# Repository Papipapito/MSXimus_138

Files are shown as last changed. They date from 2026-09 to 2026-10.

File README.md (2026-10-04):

<p align="center">MSXimus</p>

<h1 align="center">MSXimus</h1>
<p align="center"><b>A complete MSX2+ on a Tang Console 60K — now with the V9968 VDP</b></p>

> **This repository is the port of the MSXimus to the Tang Console 138K (MSXimus_138, v3.7).** What is specific to the port (SOM Mega 138K, flash map, PLL cascade, campaigns, what has and has not been tested) is in [README.138.md](README.138.md); the documentation adapted to the 138K is in [docs/INDICE.md](docs/INDICE.md). The rest of this README describes the MSXimus for the Tang Console 60K it derives from.
<p align="center">
  
  
  
</p>

<p align="center">🇪🇸 <a href="README.es.md">Versión en castellano</a></p>

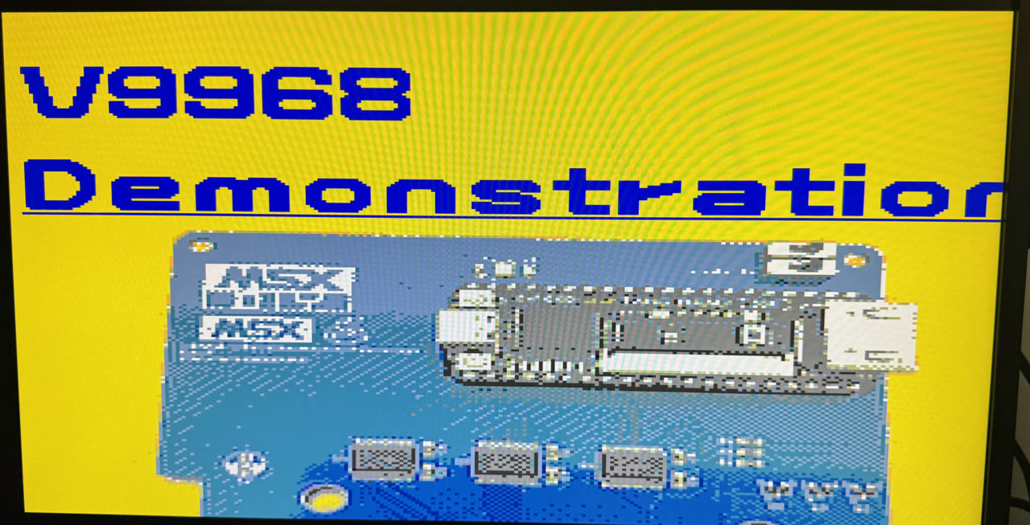
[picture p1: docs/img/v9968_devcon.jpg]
The V9968 DEVCON demo running on the MSXimus

<p align="center"><i>HRA!'s official V9968 demo, running on the MSXimus.</i></p>

---

**MSXimus** is the big brother of the [**MSXnano**](https://github.com/Papipapito/MSXnano): the same MSX2+ core lineage (goauld → MSXnano), ported to and expanded on the **Tang Console 60K**. *Nano* was the small one; *Maximus* is the big one.

It doesn't need an MSX. It **is** an MSX.

## Why v3.1 and not v2.2

Because the ground moved.

In August 2026 Gowin confirmed that the **SSRAM of the GW5AT-60B is withdrawn on purpose**: there is a silicon problem under investigation, and their recommendation is to migrate anything that uses it to BSRAM or to registers.

Version 2.1 leaned on that resource heavily — the audio engines alone accounted for most of it. So v3 is not v2.1 with more features stacked on top: it is the same MSX **rebuilt so that not one bit lives on the withdrawn resource**. Every memory that was there moved to BSRAM or to registers, and that meant reworking the OPL4 wavetable engine, the OPL3 register files and the PCM cache from the inside out.

That is a change at the foundation rather than on the surface, and it earned its own number. Everything you already knew works exactly the same; what changed is what it is standing on.

## What's inside

**Video** · Full-screen 720p HDMI output · **V9968** or V9958 · CRT-style borders · scanlines toggle, right from the menu

**Audio** · PSG · dual SCC with stereo · OPLL (MSX-Music) · **MSX-Audio Y8950** with FM and ADPCM-B · full **MoonSound / OPL4**: FM (OPL3) plus 24-voice wavetable

**Storage** · Nextor over microSD · megaram with Konami4, Konami-SCC, ASCII8 and ASCII16 mappers

**Input** · USB keyboard straight into the board (no hub needed), with physical F1–F10 · USB gamepads mapped to MSX joysticks · USB mouse as an MSX mouse

**On screen** · Optional **status panel on F12**, painted over the MSX by the BL616 the board already carries

**WiFi** · UNAPI through an external **ESP32-C6**, with an **optional display** for extra information

**Extras** · 5.37 MHz Panasonic-style turbo on **F11** · turboR-style machine identification · your choice of two BIOSes · boot logo · temperature-driven fan control · serial-port telemetry for diagnostics

## Required hardware

| | What | Notes |
|---|---|---|
| **Required** | [Sipeed **Tang Console 60K**](https://wiki.sipeed.com/hardware/en/tang/tang-console/mega-console.html) | Tang Mega 60K SOM (Gowin GW5AT-60), HDMI, 2× USB-A, microSD, DDR3 |
| **Required** | The Console's **SDRAM** module | It is the MSX's RAM; the core won't boot without it |
| Optional | **20×20 mm heatsink** on the SOM | Recommended: the core keeps the chip busy. [Like these](https://s.click.aliexpress.com/e/_c4WMlpD9) |
| Optional | **20×20 mm 5 V fan** | **1.25 mm JST connector, 2-pin** — [like this one](https://s.click.aliexpress.com/e/_c328rXwB). Fully temperature-controlled by the core |
| Optional | **USB** keyboard and gamepad | Straight into the board's USB-A ports, no hub |
| Optional | **USB mouse**, wired | Straight into the board. ⚠️ A **wireless** receiver will not work: it presents itself as a composite device |
| Optional | **ESP32-C6** (Waveshare C6-LCD-1.3) | For **WiFi**, with an optional info display |
| Optional | *Nothing to buy* — the board's own **BL616** | Enables the F12 status panel. Needs its firmware flashed once |

The fan is not needed for operation. If you fit one, the core drives it by itself: it measures the die temperature with an internal thermometer and only spins it when needed.

## Installation

Everything goes into the board's **SPI flash**, at three different addresses. ⚠️ **These are the 138K addresses**: the 138K bitstream is twice as big, so the pack and the OPL4 waves sit 4 MB higher than on the 60K (`0x400000` / `0x500000` there).

| # | File | Address | Required? |
|---|---|---|---|
| 1 | `msximus138_v3.x_dadoNNNN.fs` | **`0x000000`** | Yes — this is the core |
| 2 | BIOS pack (`pack_bios_msximus*.bin`) | **`0x800000`** | Yes — the MSX won't boot without it |
| 3 | `yrw801.bin` | **`0x900000`** | No — only for MoonSound/OPL4 (shipped as `.bin`: Gowin's Programmer does not accept `.rom`; rename a `yrw801.rom` if that is what you have) |

Two more pieces are **optional** and do not live in that flash: the **ESP32-C6** firmware (WiFi) and the **BL616** firmware (the F12 panel). Each has its own section below.

**The tools you need**, all free and all official:

| For | Tool |
|---|---|
| The three files above | [**Gowin Programmer**](https://www.gowinsemi.com/en/support/download_eda/) (the one bundled with the 1.9.12 IDE works fine) |
| ESP32-C6 (WiFi) | [**esptool-js**](https://espressif.github.io/esptool-js/) in the browser — nothing to install — or `esptool` |
| BL616 (F12 panel) | [**Bouffalo Lab Dev Cube**](https://github.com/bouffalolab/bouffalo_sdk) (BLDevCube) |

### How to flash

1. Connect the board over **USB-C** and open the **Gowin Programmer** (the 1.9.12 one works fine).
2. Let it detect the device: it should report a **GW5AST-138**.
3. For **each** of the three files, configure a write operation to the **external SPI flash** (the options starting with *exFlash*, not the SRAM ones), select the file as *Programming File*, and put **the address from the table into the start-address field**.
4. Flash the `.fs` first, then the other two. Their order doesn't matter — **the addresses do**: if the pack doesn't land exactly at `0x800000`, the core boots to a black screen.
5. **Power-cycle the board.** A reset is **not** enough: the DDR3 needs a cold recalibration and may hang after a warm reset.

> If you power up and only get a blue screen, it's almost always (a) the pack at the wrong address, or (b) a missing power-cycle.

### About the BIOS pack

The release ships **everything you need**: the core, the BIOS pack, the OPL4's `yrw801.bin` and the firmwares. Download, flash, and it boots.

There are **two builds of the same pack**, differing only in the disk kernel inside:

| Pack | Nextor |
|---|---|
| `pack_bios_msximus.bin` | **2.1.4** — the stable one, the one you want |
| `pack_bios_msximus_nextor3.bin` | **3.0 beta 1** — to try the beta |

If you would rather build the pack from your own ROMs, there's the [**MSXnano Pack Builder**](https://github.com/Papipapito/MSXnano), which assembles the file from them, Nextor included.

Without `yrw801.bin` the core works just the same; you simply won't have MoonSound.

### One BIOS, and the menu is a setting

Up to v3.1 there were **two** packs and you had to decide which to flash. There is now **one**, and that choice is a tick box in Settings.

On power-up the machine **boots straight into the MSX**. If you want the SD browser: press **S** at boot, tick **"Menu al arrancar"**, then `Save & Restart`. Untick it and you are back to booting straight in. The choice is stored in the board's flash, so it survives a power cycle.

With the menu on you get the card browser, the ROM and DSK launcher and — if you fitted the WiFi — key **F** to search and download ROMs and disk images straight to the microSD, with no PC involved.

> Mounting a `.dsk` rewrites sectors of a file that **already exists**: it never creates directory entries or allocates clusters.

After that, insert a microSD with your ROMs and disk images and you're done. The best way to prepare it is **[MSX SD Maker](https://github.com/Papipapito/SD_Maker)**, which has its own repository (a copy with its guide is in [`MSXsdmaker/`](MSXsdmaker/README.md)): a Windows program that partitions the card the way Nextor does, installs Nextor and a set of programs (SofaRun, Multi Mente…) and writes the `AUTOEXEC.BAT`.

> **About microSD cards:** use a **name-brand, Class 10** card (Samsung, SanDisk, Kingston...), formatted **FAT16**. Cheap no-name cards read fine but reject or lose sector writes under sustained bursts — we measured it on the bench: a no-name card kept failing writes even when paced, while a Samsung EVO+ was flawless with the exact same code and geometry. If downloads or saves act up, suspect the card first.

## The status panel — F12 (optional)

The Console 60K carries a second chip you have probably never used: a **BL616** microcontroller, wired to the FPGA from the factory. Give it a firmware and it will paint a status panel straight over the MSX picture.

Press **F12** and the MSX freezes and the panel comes up. Press it again and the game carries on exactly where it was. It is **read-only** — there is no menu, no cursor, nothing to break. It reports what the core says about itself:

```
 ,----------------------------.
 |       MSXimus  V3.1        |
 `----------------------------'

   CPU      3.58 MHz  normal
   Card     SDHC  st 1
   Fan      OFF
   Keyboard CAPS ON
   WiFi     0 lost  0 empty
 `----------------------------'
    F12 to go back to the MSX
```

This costs you nothing in hardware: **no wires, no soldering, no module**. The link between the two chips (a 2 Mbps serial line) was already routed on the board; it was just never used.

> Because the BL616 takes F12 for itself, that key never reaches the MSX. The **turbo toggle is F11**.

### Flashing the BL616

Two images, and they **coexist** — the Sipeed factory one stays where it is:

| File | Address |
|---|---|
| `bl616_fpga_partner_60kConsole.bin` (Sipeed's, shipped in the release) | **`0x0`** |
| `bl616_v3.1.bin` | **`0x40000`** |

1. **Hold the BOOT button down while you plug in the USB.** That puts the chip in ISP mode.
2. A **new COM port** appears — that one is the BL616. (Listing the ports before and after plugging it in is the easy way to tell which.)
3. Open **BLDevCube** and load the release's **`flash_prog_cfg.ini`**: it already carries both images with their addresses, so there is nothing to type. Keep it in the same folder as the two `.bin` files.
4. Unplug, plug back in, and power-cycle the board.

ISP mode lives in the chip's ROM, not in its flash, so it works no matter what you have written. **It is the reverse gear that never fails** — you cannot brick the board this way.

If you would rather not flash it at all, don't: the MSX works exactly the same, you simply won't have the F12 panel.

## Wiring the ESP32-C6 (WiFi)

Optional — the core works fine without it; you simply won't have WiFi. Three or four wires between the board's **J10** header and the module:

<p align="center">ESP32-C6 to J10 wiring diagram</p>

| J10 pin | Signal | FPGA ball | ESP32-C6 |
|---|---|---|---|
| **11** | +5 V (power) | — | **5V** (right strip, last one) |
| **12** | GND | — | **GND** (right strip) |
| **14** | TX (FPGA → C6) | W21 | **IO17** (left strip, the C6's RX) |
| **16** | RX (FPGA ← C6) | N17 | **IO16** (left strip, the C6's TX) |
| **18** | TURBO (FPGA → C6) | N13 | **GPIO3** (right strip, first one) — optional, only feeds the display's turbo indicator |

And this is the module side:

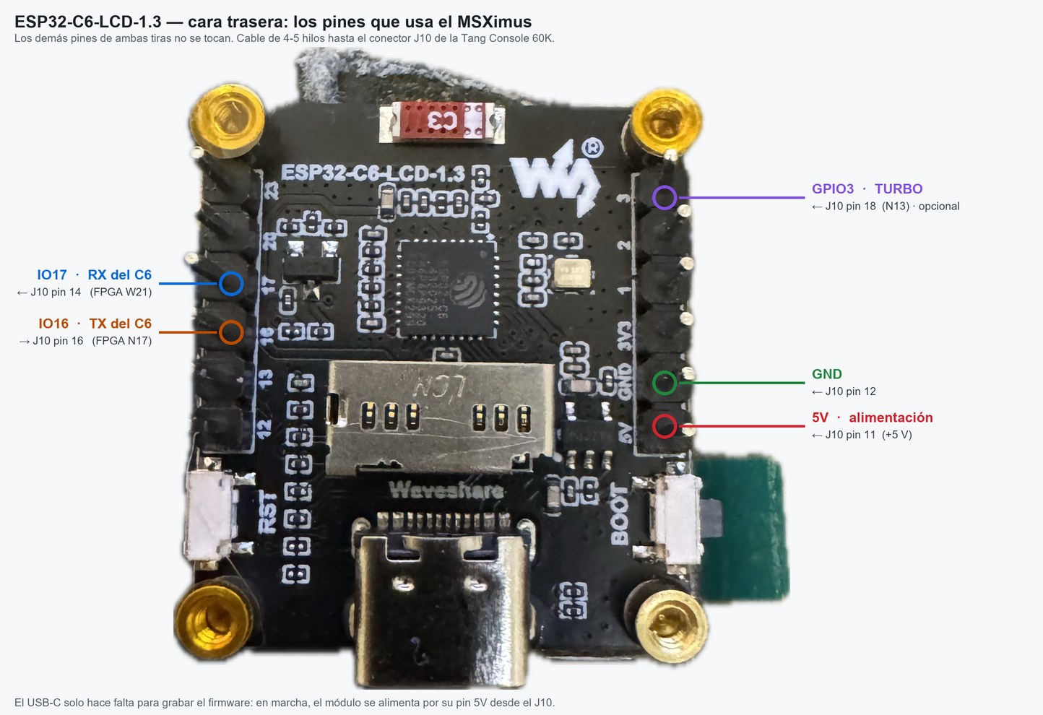
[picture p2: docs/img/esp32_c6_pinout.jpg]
ESP32-C6 pins used by the MSXimus


- **J10 is the free 2×20 header**, labelled *SDRAM1 CONN.* in Sipeed's schematic — **not** the one holding the SDRAM module the core needs.
- **Identifying the pins without silkscreen**: with the board powered off and a multimeter in continuity mode, **pin 12 is the only pin on the whole header with a path to ground**. Its row partner is pin 11 (+5 V), and from pin 12 towards the long side (the one leaving 14 rows, not 5) come 14, 16 and 18.
- **Power comes from J10 itself** (pin 11 → the module's `5V`): the C6's USB-C is only needed to flash its firmware.
- ⚠️ **Better not to have both power sources connected at once.** The module has protection and copes fine, but when flashing over USB-C it's advisable to unplug the 5 V wire (or power the board down).
- TX and RX are **crossed**, as usual. The UART runs at 859 372 baud.
- ⚠️ If a second SDRAM module is ever fitted on J10, the ESP has to move elsewhere.

### Flashing the C6

The module's firmware and its full technical inventory live in their own repository, [**ESP32-for-FPGA**](https://github.com/Papipapito/ESP32-for-FPGA) — the same binary serves the MSXimus and the MSXnano, so no copy is kept here any more. Take `firmware_esp32c6_v3.2_merged.bin` from the release and write it to the C6 through **its own USB-C**. You do **not** need the Arduino IDE, and you do not need to compile anything — the release ships a single merged binary.

**The easy way — from the browser, nothing installed.** Open [**esptool-js**](https://espressif.github.io/esptool-js/), Espressif's own web flasher, in Chrome or Edge. Connect, pick the file, set the offset to `0x0`, and click Program. No drivers, no Python, no IDE.

**The command-line way**, if you already have it:

```
esptool --chip esp32c6 --port COMx write_flash 0x0 firmware_esp32c6_v3.2_merged.bin
```

> There is no drag-and-drop route like the Raspberry Pi Pico's `.uf2`: the ESP32 has no mass-storage bootloader in ROM, so a file you copy onto a drive is not an option on any ESP32. The web flasher above is as close as it gets — one page, two clicks, nothing to install.

## The case

A 3D-printable case in the shape of a Spectravideo SVI-728, with the Console 60K inside, a bay with a lid for the ESP32-C6 and its display, a fan, and the connectors brought out to the back and the front. It derives from Palver's [SVI-728 Retropie case](https://www.thingiverse.com/thing:4066021).

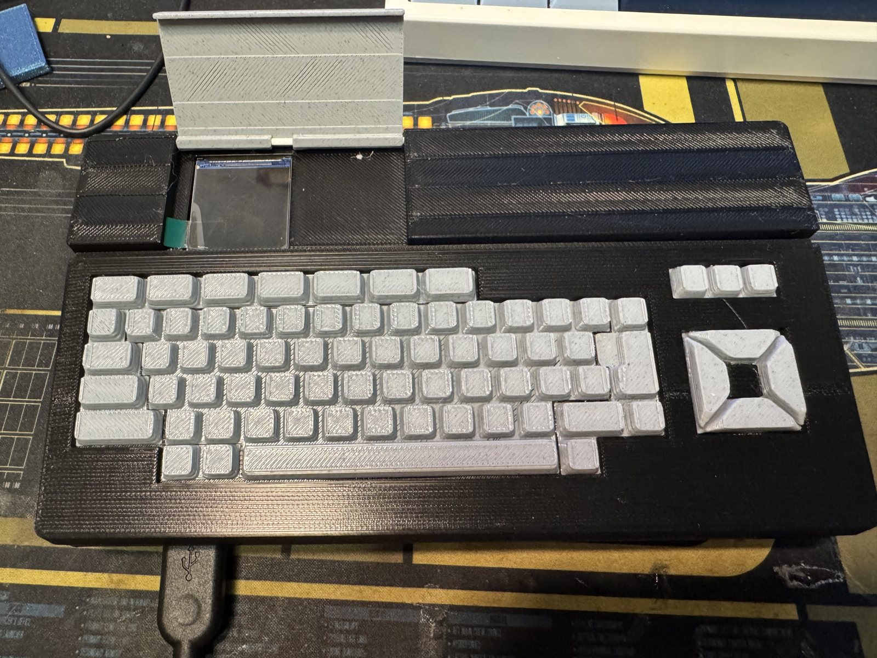
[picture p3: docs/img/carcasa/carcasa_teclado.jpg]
The printed case, display lid open

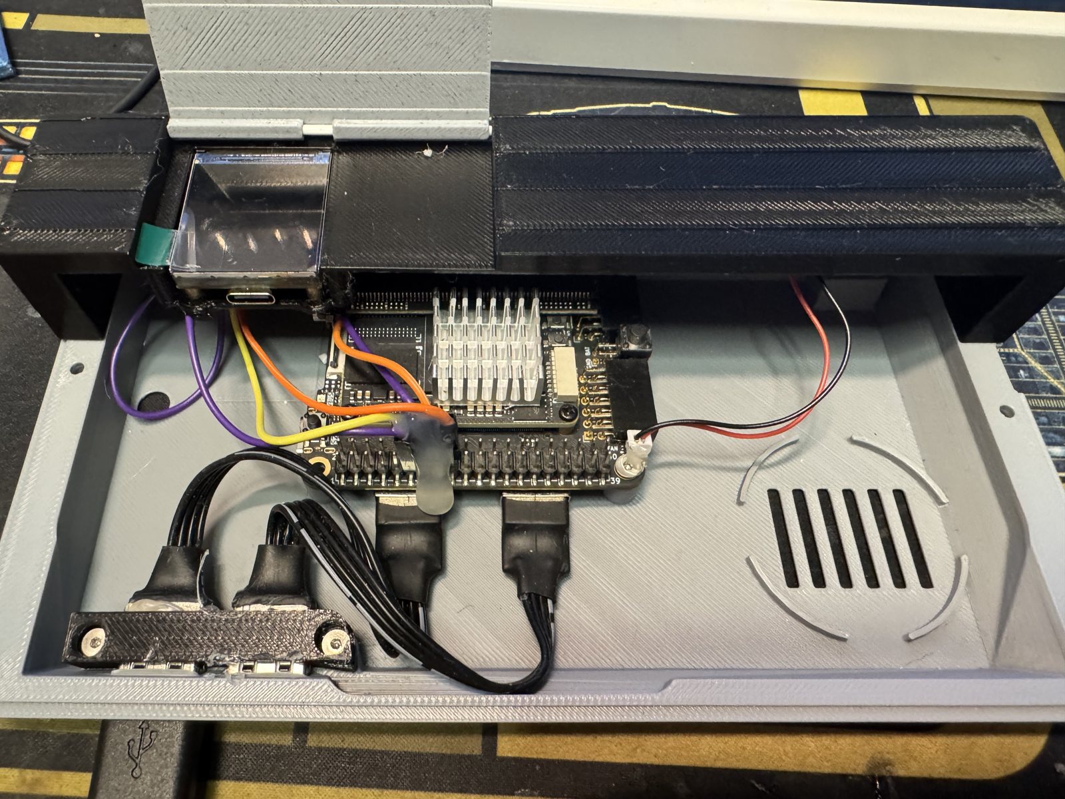
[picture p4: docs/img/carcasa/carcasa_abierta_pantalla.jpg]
Inside: the Console 60K, the C6 in its bay, the wiring


The Bambu Studio project, the STLs, the print settings and the assembly notes are in [`carcasa/`](carcasa/README.md).

## Status

This version has been validated on hardware with HRA!'s V9968 test suite, the DEVCON demos, Metal Gear 2, Aleste 2 and the usual MSX2+ catalogue. The V9968 tracks HRA!'s **latest published revision**; its provenance and every local patch are documented in [`fpga/v9968/ORIGEN.txt`](fpga/v9968/ORIGEN.txt).

## Repository layout

```
carcasa/         The 3D-printable case (3MF, STLs, assembly)
docs/            Manual, technical reference, history, logo, photos
MSXsdmaker/      MSX SD Maker: prepares the SD card (Windows program + instructions)
fpga/            top.v, build.tcl
  v9968/         The V9968 VDP (+ ORIGEN.txt: provenance and local patches)
  video720/      HDMI bridge and scaler
  src/           Own RTL (VRAM shim, DDR3 backend, audio, USB, S1990…)
    iosys/       The BL616 link and the on-screen panel
  constraints/   Console 60K pinout and constraints
tools/           Testbenches and validation utilities
```

## What's new in v3.2

The core **does not change**: it is the same `.fs` as v3.1. What changes is everything above it.

- **One BIOS** — no more picking a pack. The SD browser is now a tick box in Settings: `S` at boot, "Menu al arrancar", done. Stored in flash.
- **Downloads from the menu** — with WiFi, key `F` searches and pulls ROMs and disk images straight to the microSD, no PC.
- **Boot logo on the C6 screen** — the MSX logo assembling from both sides, like a real MSX2.
- **The C6 firmware lives in its own repository**, [ESP32-for-FPGA](https://github.com/Papipapito/ESP32-for-FPGA), and it is the same binary for the MSXimus and the MSXnano.

## What's new in v3.1

- **Rebuilt off the withdrawn silicon** — the whole core now runs without the GW5AT-60B's SSRAM. This is the headline of the version and the reason for the number; the [why](#why-v31-and-not-v22) is at the top.
- **A status panel on F12** — the BL616 already on the board paints the machine's real state over the picture, with the MSX frozen underneath. No wires, no module, no extra hardware.
- **It introduces itself as a turboR** — the S1990 identification registers are in (`E4h`–`E7h`), and `CHGCPU` really does move the turbo. No R800: same Z80, telling the truth about what it is.
- **MSX mouse from a USB mouse** — plug a **wired** USB mouse into the board and MSX software sees an MSX mouse. (A wireless receiver will not do: it presents itself as a composite device.)
- **Two BIOSes to choose from** — a plain MSX, or the same plus an SD browser and launcher. *(Merged into one in v3.2.)*
- **Turbo on F11** — F12 now belongs to the panel.

Everything from v2.1 is still here: the V9968 at HRA!'s latest revision, the remastered audio, the 256 KB MSX-Audio, the CRT-style picture and the full 2 MB ASCII16 megaROMs.

## The V9968

The heart of the MSXimus is **Takayuki Hara's (HRA!) [V9968](https://github.com/hra1129/V9968_Cartridge)**, an imaginary VDP that extends the V9958 with everything Yamaha never got to ship:

- **Multicolor sprites**: 15 colors plus transparency **per sprite**, defined pixel by pixel
- **16 sprites per line** instead of 8 — flicker is over
- **Scalable sprites**, with free magnification, rotation and mirroring
- **Extended palette**: 256 colors in 16 sets of 16
- **256 KB of VRAM**, extended commands (LRMM rotation, LFMM, LFMC) and a fast command mode

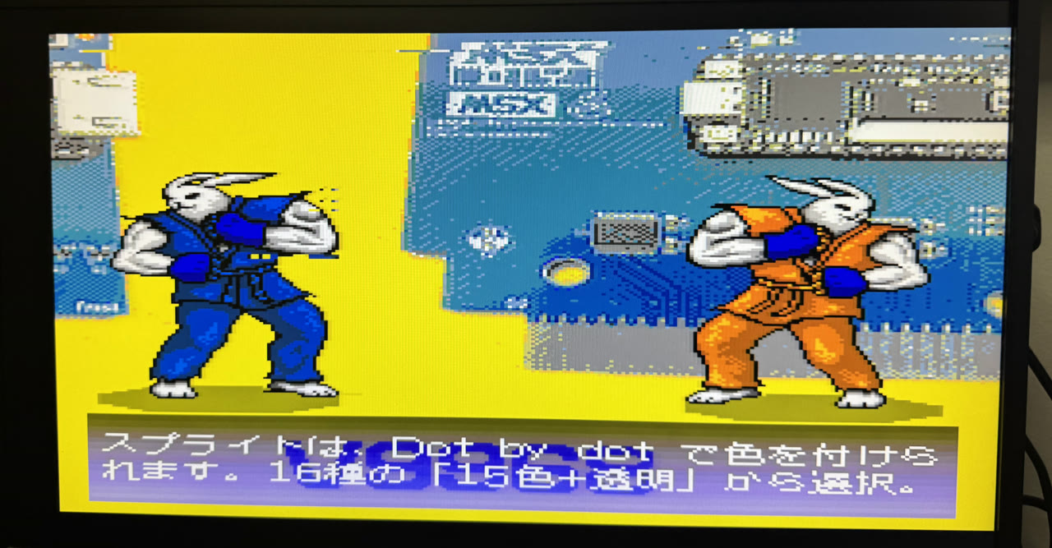
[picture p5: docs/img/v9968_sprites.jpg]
V9968 multicolor sprites

<p align="center"><i>15-color sprites defined pixel by pixel: impossible on a real MSX2+.</i></p>

The V9968's VRAM lives in the board's **DDR3**, leaving the whole SDRAM to the MSX's RAM and to whatever comes next.

And it's still a regular MSX2+: your usual software runs just the same.

## License

**GPLv3**, derived from [`Papipapito/MSXnano`](https://github.com/Papipapito/MSXnano). See [LICENSE](LICENSE) and [UPSTREAM.md](UPSTREAM.md) for full attribution and third-party IP.

The **V9968** belongs to Takayuki Hara and comes under his own BSD-like but **non-commercial** license: it may be redistributed with its notices intact and published for free, **but not sold**. That condition is inherited, so **this project is not for sale**.

The MSXimus logo belongs to the project.

---

# Thanks

I didn't build this alone — not even close. Everything here stands on the work of people who published theirs so others could keep going.

### The core and its lineage

- **[jabadiagm](https://github.com/jabadiagm)** — MSXgoauldSD, the Goa'uld, origin of this whole lineage (goauld → MSXnano → MSXimus), and MSX_LCD_tn20k.
- **OCM-PLD / ESE Artists' Factory lineage** — Kunihiko Ohnaka, KdL and everyone who has kept the FPGA MSX2+ alive for two decades. The V9958 VDP comes from there.

### The V9968

- **[Takayuki Hara — HRA!](https://github.com/hra1129)** — author of the **V9968**, the VDP that makes this version special, of the DEVCON demo and of the whole test suite it was validated against. Thank you for publishing and documenting it so well.
- **[Albert Herranz — herraa1](https://github.com/herraa1)** — the MSXgl demo port (`ru66-v9968-demo`), the V9968 cartridge and the reference material that made debugging the core possible.

### Audio

- **[Jose Tejada — jotego](https://github.com/jotego)** — jt2413 (OPLL), jtopl2 (Y8950 FM) and jt10_adpcmb. GPLv3.
- **[Greg Taylor — gtaylormb](https://github.com/gtaylormb)** — opl3_fpga (LGPLv3), which includes `afifo.v` by **Dan Gisselquist (ZipCPU)**.
- **Jokin Miragaia (antxiko)** — mangOPL4, the Gowin fixes and the integration lessons.
- **srg320** — YMF278B.sv, the OPL4's PCM engine, contributed with express permission.
- **MAME team** — R. Belmont, Olivier Galibert and hap (ymf278b.cpp), and **Aaron Giles** (ymfm).
- **Tatsuyuki Satoh** — the reference ADPCM-B algorithm.

### The board and the video chain

- **[nand2mario](https://github.com/nand2mario)** — `ddr3_framebuffer_gowin` (the DDR3 IP recipe that makes VRAM-in-DDR3 possible), `usb_hid_host`, the 720p video template and, in general, for clearing the path in the Tang ecosystem.
- **hdl-util (Sameer Puri)** — the HDMI packer (MIT).
- **[ducasp](https://github.com/ducasp)** — the ESP UNAPI firmware and protocol.

### Validation and tools

- **The [openMSX](https://openmsx.org) team** — the reference against which right and wrong get decided.
- **Laurens Holst (grauw)** — VGMPlay MSX and the MSX Assembly Page.
- **aoineko (Guillaume Blanchard)** — MSXgl.
- **[Sipeed](https://sipeed.com)** and **Gowin** — the board and the toolchain.
- **Yamaha** — for the original chips (V9958, YM2149, YM2413, Y8950, YMF262, YMF278B) that this project emulates with love.

### And

- **Claude (Anthropic)** — **code co-author**: new RTL, the VRAM-over-DDR3 shim, the audio integrations, the validation suite, and an indecent number of debugging hours built on simulation, telemetry, and being wrong many times before being right.

---

<p align="center"><i>For the MSX community. May it last another forty years.</i></p>

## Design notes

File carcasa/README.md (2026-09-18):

# La carcasa del MSXimus

Una carcasa para imprimir en 3D con la forma de un Spectravideo SVI-728, con la Tang Console 60K dentro, el ESP32-C6 con su pantalla en una bahía con tapa, ventilador, y los conectores sacados al exterior.

<p align="center">La carcasa impresa, con la tapa de la pantalla abierta</p>

## Origen

Deriva de la **[Spectravideo SVI-728 Retropie case](https://www.thingiverse.com/thing:4066021)** de Palver en Thingiverse, una réplica del SVI-728 pensada para una Raspberry Pi, rediseñada aquí para la Console 60K. **El 3MF lleva todo lo necesario**: no hace falta bajar nada del original. La licencia del diseño original se aplica a lo que se conserva de él; conviene mirarla en la página de Thingiverse antes de redistribuir.

## Qué hay

| Fichero | Qué es |
|---|---|
| `MSXimus_carcasa.3mf` | El proyecto de **Bambu Studio** con las once piezas ya repartidas en cuatro platos y con los ajustes de impresión. Es lo que se abre y se imprime, y es la caja completa |
| `stl/` | Las mismas once piezas sueltas, en STL, para cualquier otro laminador |

Las piezas:

| Pieza | Para qué | Plato del 3MF |
|---|---|---|
| `placa_inferior` | **La tapa de abajo**: el suelo, con los postes donde se atornilla la Console 60K, la rejilla del ventilador y las salidas de los cables | 3 |
| `zona_pantalla` | **La tapa de arriba, parte trasera**: la bahía del ESP32-C6 con su pantalla, la ventana del ventilador y la ranura de los conectores | 1 |
| `tapateclado` | **La tapa de arriba, parte delantera**: el marco del teclado, donde se pegan las teclas | 4 |
| `tapacartucho` | La tapa con bisagra de la bahía de la pantalla, donde el SVI-728 tenía el cartucho; se levanta para ver la pantalla | 1 |
| `usb_conector_clamp_x1` | La brida que sujeta la extensión de dos USB-A al frontal | 2 |
| `key_1` a `key_4` (gris oscuro), `key_5` (gris claro), `cursor` | Las teclas del teclado y el cursor en cruz. **Van pegadas** al marco de `tapateclado` | 2 |

El teclado es decorativo: el MSXimus usa un teclado USB.

## Impresión

Los ajustes con que se imprimió la de las fotos, tal como van en el 3MF:

| | |
|---|---|
| Impresora | Bambu Lab X1 Carbon, boquilla de 0,4 mm |
| Material | PLA. Dos colores: gris claro para el suelo y las tapas, negro o gris oscuro para la tapa superior; las teclas en los dos grises |
| Altura de capa | 0,24 mm |
| Relleno | 15 % |

Cuatro platos. En cualquier otra impresora valen los STL con ajustes equivalentes.

## Montaje

<p align="center">La carcasa abierta: la Console 60K atornillada al suelo, el C6 en su bahía, los cables</p>

- La **Console 60K** va atornillada a los postes del suelo, con el disipador hacia arriba y el conector J10 hacia la bahía de la pantalla.
- El **ESP32-C6** se sujeta en la bahía trasera con dos tornillos por su brida impresa y queda con la pantalla mirando hacia arriba, bajo la tapa, y el USB-C accesible desde dentro para grabarlo. Sus cables al J10 son los del [capítulo 02 del manual](../docs/manual/02-instalacion.md): 5 V, GND, TX, RX y, opcional, el turbo. Una vez probados, un poco de silicona sobre el conector del J10 los deja fijos.

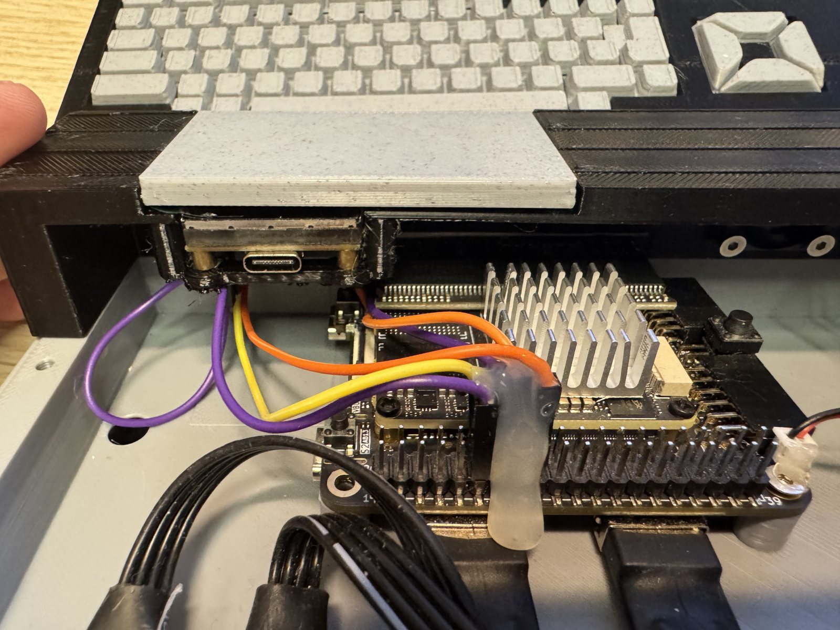
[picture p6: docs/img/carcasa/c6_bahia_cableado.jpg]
El C6 en su bahía, con los cables al J10 fijados con silicona

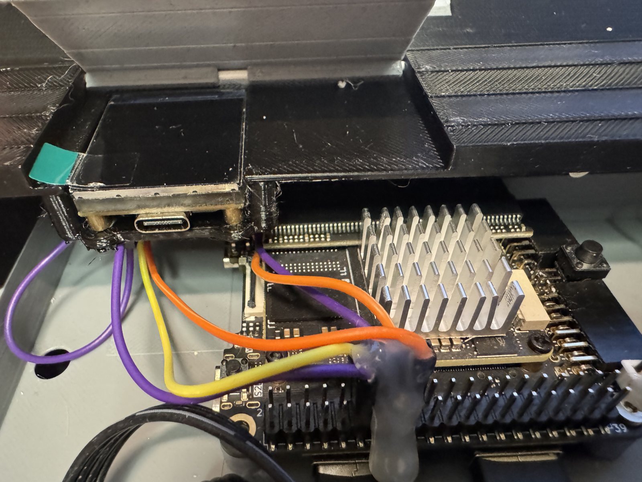
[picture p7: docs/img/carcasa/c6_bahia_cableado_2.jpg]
La bahía del C6 con la tapa levantada

- El **ventilador** de 20 mm va en la ventana trasera de la tapa, con su cable al conector de ventilador de la placa (el rojo y negro de la foto).
- **HDMI y USB**: latiguillos cortos de extensión llevan el HDMI y el USB de la placa a las ranuras traseras, y una extensión de dos USB-A con su brida sale al frontal izquierdo, para el teclado y el mando.

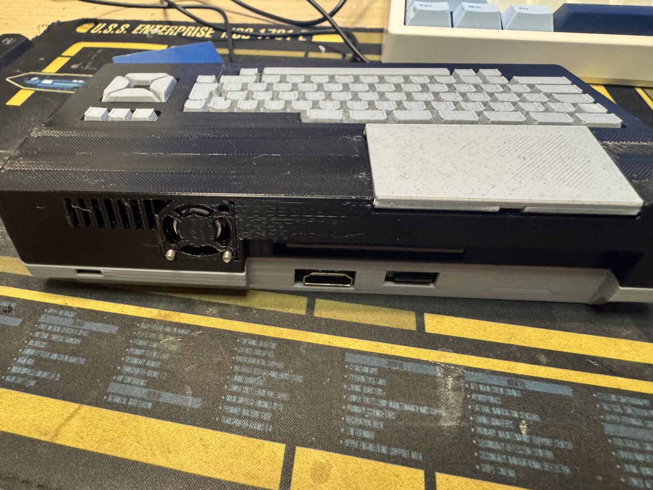
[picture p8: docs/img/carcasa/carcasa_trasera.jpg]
La parte trasera: ventilador, HDMI y USB


Y así queda junto a la carcasa VG-8020 del MSXnano, con la pantalla del C6 encendida:

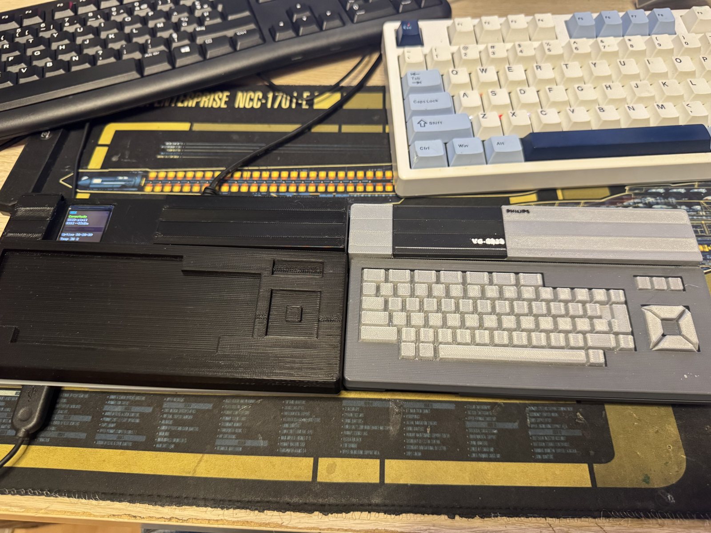
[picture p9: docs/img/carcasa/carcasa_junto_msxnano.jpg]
MSXimus y MSXnano en sus carcasas


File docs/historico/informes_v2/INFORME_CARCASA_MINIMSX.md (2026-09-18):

# Carcasa "mini MSX" para la Tang Console 60K + pantallita Waveshare — catálogo comentado

Investigación web (jul-2026). Objetivo: alojar la **Sipeed Tang Console 60K** (placa base "console" + SOM Mega 60K encima) y la **Waveshare ESP32-C6-LCD-1.3** (LCD 1.3" 240x240) como display frontal, conectada por cable plano de 4 hilos, dentro de una carcasa imprimible con estética de MSX clásico en miniatura.

---

## 1. Dimensiones confirmadas (el dato clave)

| Pieza | Dato | Fuente |
|---|---|---|
| Placa Tang Console (la "dock" donde pincha el SOM) | **65 × 56 mm** | [CNX Software](https://www.cnx-software.com/2025/05/27/sipeed-tang-console-a-gowin-gw5ast-gw5at-board-with-60k-or-138k-lut-for-fpga-development-and-retro-gaming/), [Hackster](https://www.hackster.io/news/sipeed-takes-on-the-mighty-mister-with-its-tang-console-fpga-development-board-112a417b3ec6) |
| Altura del conjunto placa+SOM | No publicada en texto; **sacarla del STEP oficial** (abajo) | — |
| Conectores a recortar | HDMI, 2× USB3-A, 2× USB-C, conector LCD 40P, altavoz, 2× PMOD, 2× 2x20P | Wiki Sipeed / CNX |
| Planos y 3D oficiales | Mechanical drawing: `dl.sipeed.com/shareURL/TANG/Console/04_Mechanical_drawing` · 3D: `.../05_3D_file` | [Wiki Sipeed](https://wiki.sipeed.com/hardware/en/tang/tang-console/mega-console.html) |
| Carcasa oficial del bundle | Acrílico estilo NES (no imprimible, referencia estética) | [Time Extension](https://www.timeextension.com/news/2025/01/usd69-fpga-tang-console-can-double-as-a-retro-gaming-handheld) |
| ESP32-C6-LCD-1.3: pantalla | 1.3" IPS 240×240, ST7789V2, SPI 4 hilos | [docs.waveshare.com](https://docs.waveshare.com/ESP32-C6-LCD-1.3) |
| ESP32-C6-LCD-1.3: conexión | Header GPIO **9 pines paso 2.54 mm** (encaja con tu plan de cable plano de 4 hilos) | docs.waveshare.com |
| ESP32-C6-LCD-1.3: PCB | Dims exactas solo en el plano-imagen "Product_Size" de la wiki (no legible por texto); área activa de un 1.3" cuadrado ≈ **23.4 × 23.4 mm** (geometría) | docs.waveshare.com |

**Conclusión de encaje**: la 60K es pequeña (65×56 mm). Cualquier mini-MSX a escala 1:2 (~25 cm de ancho, siendo un MSX real ~50 cm) la traga con holgura enorme; incluso a ~1:3 cabría. El problema nunca será el volumen, sino los **recortes de puertos** y el anclaje.

---

## 2. Catálogo

### A. Minis MSX imprimibles

| # | Modelo | Plataforma | Enlace | Licencia | Formato | Veredicto |
|---|---|---|---|---|---|---|
| 1 | **MSX Philips VG-8020 (escala 1:2)** — amandris | Thingiverse + Cults3D | [thing:3564052](https://www.thingiverse.com/thing:3564052) · [Cults3D (gratis)](https://cults3d.com/en/3d-model/gadget/amandris) | **CC-BY** (etiqueta "No AI") — remezclable con atribución | **14 STL** (base, teclado, teclas, tapa trasera, tapa cartucho, pies…) + decals al agua en PDF | **El mejor candidato directo**: pensado para meter una Raspberry Pi + electrónica (emulador MSX), interior hueco; pega: solo STL, los recortes de puertos van a golpe de editor de malla |
| 2 | **The MSX Mini Replica** (VG-8020 1:2, diseño de Gustavo Miguélez) | Blog propio | [themsxmini.blogspot.com](https://themsxmini.blogspot.com/) | Carcasa usada "bajo permiso escrito" — **ficheros NO publicados** | — | Solo referencia estética/prueba de concepto (RetroPie dentro, HDMI 720p); no descargable |
| 3 | Omega MSX Computer Case — charlesmouse | Thingiverse | [thing:5233265](https://www.thingiverse.com/thing:5233265) | ver página | STL | Tamaño completo (para el Omega MSX2+ real con teclado): NO es mini, no aplica |
| 4 | Spectravideo SVI-728 Retropie case | Thingiverse (vía Yeggi) | [yeggi "msx case"](https://www.yeggi.com/q/msx+case/) | ver página | STL | Carcasa estilo MSX1 para RPi pero a tamaño grande; estética SVI, no Philips/Panasonic |
| 5 | Miniaturas-llavero MSX (Hotbit HB-8000, Sony Hit-Bit…) | STLFinder/varios | [stlfinder "sony msx"](https://www.stlfinder.com/3dmodels/sony-msx/) | varias | STL | Sólidas, decorativas: no sirven como carcasa |
| 6 | Amstrad CPC464mini retro computer | MakerWorld | [modelo 821842](https://makerworld.com/en/models/821842-amstrad-cpc464mini-retro-computer) | ver página | 3MF/STL | No es MSX, pero es el patrón de calidad de "micro-ordenador retro en mini con hueco para SBC": útil como referencia técnica |
| 7 | Mini NES Raspberry Pi Case (NESPi) — daftmike | Thingiverse | [thing:1727668](https://www.thingiverse.com/thing:1727668) | ver página | STL | Vía alternativa "consola": casa con la estética NES de la carcasa oficial de Sipeed, pero deja de "parecer un MSX" |

### B. Específico Tang Console 60K

| # | Modelo | Plataforma | Enlace | Licencia | Formato | Veredicto |
|---|---|---|---|---|---|---|
| 8 | **Tang Retro Console PCB (STEP oficial de la placa)** — usuario 源源圆球 | MakerWorld | [modelo 1031373](https://makerworld.com/en/models/1031373-tang-retro-console-pcb) | descarga libre | **STEP** | **ORO**: el modelo 3D de la PCB subido expresamente para que la comunidad diseñe carcasas (Sipeed montó un concurso de carcasas regalando una consola al ganador — [RetroShell](https://shop.retroshell.com/2025/01/25/sipeed-introduces-tang-console-a-69-fpga-device-with-retro-gaming-capabilities/)); importas la placa en CAD y los cortes salen exactos |
| 9 | Planos + 3D oficiales Sipeed | dl.sipeed.com | [04_Mechanical_drawing](https://dl.sipeed.com/shareURL/TANG/Console/04_Mechanical_drawing) · [05_3D_file](https://dl.sipeed.com/shareURL/TANG/Console/05_3D_file) | libre | DWG/PDF + 3D | Fuente canónica de cotas; complementa al #8 |
| 10 | Console enclosure for Tang Nano **20K** — Silicon Dioxide Studios | Printables | [modelo 1446342](https://www.printables.com/model/1446342-console-enclosure-for-sipeed-tang-nano-20k-fpga) | gratis (ver página) | STL | Es para la TN20K, no para la 60K → **no vale aquí, pero es un bonus directo para tu MSXnano** |
| 11 | Case for Tang Nano 9K — Alexander K | Printables | [modelo 1047221](https://www.printables.com/model/1047221-case-for-sipeed-tang-nano-9k) | gratis | STL | No aplica (9K); solo inventario |

**No existe (a jul-2026) ninguna carcasa comunitaria imprimible publicada específica de la Tang Console 60K** en Printables/MakerWorld/Thingiverse — el hueco que dejó el concurso de Sipeed lo cubre el STEP del #8. TangCore (nand2mario) tampoco referencia carcasas en su repo.

### C. Montura para la Waveshare ESP32-C6-LCD-1.3

| # | Modelo | Plataforma | Enlace | Veredicto |
|---|---|---|---|---|
| 12 | (ninguno específico del 1.3") | — | búsquedas en [Yeggi](https://www.yeggi.com/q/esp32+c6/), MakerWorld, Printables | **No hay case/bezel publicado para el 1.3"** (placa nueva); todo lo que aparece es del hermano **1.47"** |
| 13 | Cases del ESP32-C6-LCD-**1.47** (referencia) | MakerWorld / Cults3D / Thingiverse | [1839340](https://makerworld.com/en/models/1839340-waveshare-esp32-c6-touch-lcd-1-47-case) · [1301018](https://makerworld.com/en/models/1301018-esp32-lcd-1-47-case) · [458740](https://makerworld.com/en/models/458740-waveshare-esp32-c6-case) · [Cults3D edge](https://cults3d.com/en/3d-model/gadget/enclosure-edge-for-waveshare-esp32-c6-1-47-rectangle-lcd-sdlw01-28563) · [thing:7065147](https://www.thingiverse.com/thing:7065147) | PCB distinta: no compatibles directamente; sirven para copiar el truco de clip/bisel. Un bezel propio es trivial: ventana de ~23.5 mm + bolsillo para la placa, cotas del plano "Product_Size" de la wiki |

---

## 3. TOP 3 razonado

1. **Diseño propio: contorno VG-8020 escalado + STEP oficial de la PCB (#8/#9)**. Tienes el contorno del VG-8020 ya trabajado en KiCad→STEP/DXF (proyecto msxnano-board8020): escalarlo a ~1:2–1:2.5 alrededor de los 65×56 mm e importar el STEP de la placa da recortes de puertos exactos a la primera. Único camino con encaje garantizado y estética 100% Philips.
2. **Adaptar el VG-8020 1:2 de amandris (#1)**. La estética ya está resuelta y probada (es la base visual del "MSX Mini"), licencia CC-BY remezclable, interior pensado para SBC. Coste: solo STL (retocar recortes en malla o remodelar la tapa trasera), y la pantalla frontal habría que integrarla en la zona del slot de cartucho.
3. **Vía "consola mini" (#7/#10 como patrones)**. Rápida y funcional, casa con la carcasa NES oficial de Sipeed, pero pierde el "parece un MSX" que pide Albert; dejarla como plan C.

## 4. La vía de diseño propio, en 3 líneas

Mejor **escalar tu contorno VG-8020** que adaptar un STL ajeno: tu activo ya está en STEP/DXF paramétrico (oro para CAD), mientras que lo publicado es malla. La 60K es tan pequeña que el escalado no tiene restricción de volumen, solo de posición de puertos, y eso se resuelve importando el STEP oficial de la PCB (#8). De amandris conviene "robar" (con atribución CC-BY) lo caro de modelar: teclado, teclas, proporciones y sus decals al agua.

## 5. Recomendación final

**Híbrido**: carcasa propia con tu contorno VG-8020 escalado (~25 cm de ancho a 1:2, o más compacta a 1:2.5) alrededor del STEP de la Tang Console (MakerWorld 1031373 + planos dl.sipeed.com), tomando de amandris (CC-BY) teclado/teclas/decals para el acabado. La **ESP32-C6-LCD-1.3 como display frontal** en la posición del slot de cartucho o del logo, con bezel propio (ventana ~23.5 mm; no existe montura publicada, y las del 1.47" no encajan) y su header de 9 pines a 2.54 mm alimentando el cable plano de 4 hilos hacia el dock. Verificar la altura apilada placa+SOM en el STEP antes de fijar la altura de la carcasa — es el único dato que no está publicado en texto.

---

### Fuentes principales
- Sipeed Tang Console: [CNX Software](https://www.cnx-software.com/2025/05/27/sipeed-tang-console-a-gowin-gw5ast-gw5at-board-with-60k-or-138k-lut-for-fpga-development-and-retro-gaming/) · [Hackster](https://www.hackster.io/news/sipeed-takes-on-the-mighty-mister-with-its-tang-console-fpga-development-board-112a417b3ec6) · [Wiki Sipeed](https://wiki.sipeed.com/hardware/en/tang/tang-console/mega-console.html) · [Time Extension](https://www.timeextension.com/news/2025/01/usd69-fpga-tang-console-can-double-as-a-retro-gaming-handheld) · [RetroShell (concurso carcasas)](https://shop.retroshell.com/2025/01/25/sipeed-introduces-tang-console-a-69-fpga-device-with-retro-gaming-capabilities/)
- STEP de la PCB: [MakerWorld 1031373](https://makerworld.com/en/models/1031373-tang-retro-console-pcb)
- Mini MSX: [Thingiverse thing:3564052](https://www.thingiverse.com/thing:3564052) · [Cults3D amandris](https://cults3d.com/en/3d-model/gadget/amandris) · [The MSX Mini Replica](https://themsxmini.blogspot.com/) · [MSX Resource Center (hilo VG-8020)](https://www.msx.org/forum/msx-talk/hardware/3d-printed-philips-vg-8020)
- Pantalla: [docs.waveshare.com/ESP32-C6-LCD-1.3](https://docs.waveshare.com/ESP32-C6-LCD-1.3) (esquema PDF: files.waveshare.com/wiki/ESP32-C6-LCD-1.3/ESP32C6-1.3.pdf)
- TangCore sin carcasas: [github.com/nand2mario/tangcore](https://github.com/nand2mario/tangcore)

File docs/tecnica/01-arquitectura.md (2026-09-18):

# 01. Arquitectura del core

Cómo está montado el MSXimus por dentro: qué bloques hay, cómo se conectan, con qué relojes van y qué pasa desde que se enciende la placa hasta que el Z80 ejecuta su primera instrucción. Todo sale de `fpga/top.v` y de los módulos que instancia; los números están tomados del RTL tal como se sintetiza.

Este es el porte del MSXimus a la **Tang Console 138K**. El core es el mismo que el del MSXimus 60K salvo en el chip, los relojes y el mapa de flash, y eso es lo que cambia en este capítulo. Una advertencia que vale para todo el documento y no se repite en cada apartado: el porte está compilado y verificado en simulación, pero **nunca se ha probado en una placa 138K**. Lo que en el 60K son medidas en placa (márgenes de dados, velocidades, temperaturas) se cita aquí como del 60K.

## 1. La placa y lo que se usa de ella

El MSXimus_138 corre en la **Sipeed Tang Console 138K**: la misma placa base que la Console 60K con el SOM **Tang Mega 138K** en vez del Mega 60K. El SOM lleva la FPGA **Gowin GW5AST-LV138PG484A** (484 bolas; 138.240 LUT, 340 bloques de BSRAM, 12 PLL, 298 DSP), una **DDR3** de 1 GB de la que el core usa una región (la VRAM del V9968) y una flash SPI de 16 MB. En la placa base hay una **SDRAM Winbond W9825G6KH** de 16 bits (el módulo de 40 pines de 32 MB, el mismo que en el 60K), la ranura de la tarjeta SD, dos puertos USB-A, el HDMI, el conector 2×20 libre donde va el ESP32-C6 y un microcontrolador **BL616** que hace de programador y de canal de servicio.

El SOM Mega 138K saca a la placa base las mismas bolas que el Mega 60K, dock y DDR3 incluidos, así que el fichero de pines (`fpga/constraints/msx_console138k.cst`) es una copia del del 60K con tres retoques que exige el chip: `IO_TYPE=SSTL15`/`SSTL15D` en la DDR3 (el 138 rechaza el sufijo `_I`), `s1`/`s2`/`fan_en_o` a `LVCMOS33` porque en el 138 el banco 5 va a 3,3 V, y fuera las `INS_LOC` del DLL/PLL de la DDR3. Quedan sin contrastar contra el esquemático las señales que nand2mario no usa en sus cores para la 138K: `sd_*`, `spi_irqn`, `s2`, `fan_en_o` y `esp_*` (pendiente de verificar en placa).

| Recurso | Para qué lo usa el core |
|---|---|
| SDRAM externa de 16 bits | Toda la memoria del MSX: BIOS y ROMs del pack, mapper de 2 MB, megaram de 4 MB, fuente kanji, driver de disco. Mapa en el capítulo 03. Y, por encima de los 8 MB que direcciona la CPU (filas 4096+), la tabla de ondas de 2 MB del OPL4 más 2 MB de RAM de muestras (`wave_sdram`, desde la _104) |
| DDR3 del SOM | La VRAM del V9968, con su propio controlador (la misma IP x16 a 297 MHz que en el 60K). Es el único cliente de la DDR3: las ondas del OPL4 no van aquí |
| Flash SPI de 16 MB | El bitstream (4,88 MB), el pack de BIOS de 512 KB, once bytes de configuración y la ROM de ondas YRW801 |
| Tarjeta SD | Discos y ROMs del usuario, con su propio controlador en el core (capítulo 06) |
| BL616 | Flasheo por JTAG, y una UART con el core para el panel de estado F12 sobre el HDMI. El firmware del BL616 del 60K (fork de TangCore) no se ha compilado para la 138K, que trae el partner firmware de Sipeed: el panel F12 queda pendiente |
| ESP32-C6 externo | WiFi UNAPI y pantalla de estado, por UART a unos 860 kbps |
| USB-A ×2 | Teclado, ratón y mando, con un host USB HID propio en el fabric, sin hub |

La flash está compartida con el BL616 y el bitstream del GW5AST-138 ocupa 4,88 MB (el del 60K, 2,47), así que todo el mapa sube 4 MB respecto al 60K: el pack de BIOS va en 0x800000 (60K: 0x400000), el bloque de configuración en 0x880000 (60K: 0x480000) y la YRW801 en 0x900000 (60K: 0x500000). Son tres `localparam` en `top.v` (`FLASH_START_ADDRESS`, `FLASH_CONFIG_ADDRESS`, `WL_FLASH_BASE`). Los packs son los mismos ficheros que en el 60K, solo cambia la dirección donde se graban; el programador de Gowin graba el `.fs` en 0x000000 igual.

El dispositivo en `build.tcl` es `GW5AST-138B`. Sipeed monta chips versión C desde julio de 2025 y para ellos Gowin pide compilar con `GW5AST-138C`: hay que mirar la serigrafía del chip del SOM. Hace falta Gowin EDA 1.9.12.03 en edición Standard con licencia; la Education no soporta el 138K.

## 2. Diagrama de bloques

```mermaid
flowchart LR
    subgraph CPU["Bus del MSX (54 MHz, T-estados a 3,58 / 5,37 MHz)"]
        Z80["Z80 (G80a)"]
        PPI["PPI A8-AB"]
        SLOT["Decodificador de slots\ny puertos de E/S"]
    end
    Z80 --- SLOT
    PPI --- SLOT

    subgraph MEM["Memoria"]
        MC["memory_ctrl\n(SDRAM 16 bits, 108 MHz)"]
        MAP["Mapper 2 MB"]
        MEGA["Megaram 4 MB\n+ SCC + GM2"]
        ROM["BIOS, menú, Nextor,\nkanji (del pack)"]
    end
    SLOT --> MAP --> MC
    SLOT --> MEGA --> MC
    SLOT --> ROM --> MC

    subgraph VID["Vídeo"]
        VDP["V9968 (85,9 MHz)"]
        SHIM["Shim de VRAM\n+ caché"]
        VDDR["Backend DDR3\n(VRAM 256 KB)"]
        HDMI["msx2hdmi\n720p, 74,25 MHz"]
    end
    SLOT --> VDP --> SHIM --> VDDR
    VDP --> HDMI

    subgraph AUD["Audio"]
        PSG["PSG ×2"]
        SCC["SCC ×2"]
        OPLL["OPLL"]
        Y8950["Y8950 + ADPCM"]
        OPL4["OPL4: FM + PCM\n(ondas en SDRAM)"]
        MIX["Mezclador con\nganancia #44"]
    end
    SLOT --> PSG & SCC & OPLL & Y8950 & OPL4 --> MIX --> HDMI
    OPL4 --> MC

    subgraph IO["Periféricos"]
        SD["Controlador SD\n+ DMA"]
        USB["USB HID ×2"]
        ESP["UART ESP32-C6"]
        BL["UART BL616\n(panel F12)"]
        FLASH["Streamer de flash"]
    end
    SLOT --> SD --> MC
    USB --> PPI
    SLOT --> ESP
    BL --> HDMI
    FLASH --> MC
```

Todo lo que toca la SDRAM pasa por un único controlador, `memory_ctrl`, que reparte turnos entre la CPU y los clientes secundarios. El V9968 no toca la SDRAM: su VRAM vive en la DDR3 a través del shim.

## 3. Relojes y dominios

El GW5AST no tiene el primitivo `PLLA` del GW5AT del 60K: tiene `PLL`, con los mismos divisores pero sin mDRP, y un `PLL_INIT` que le carga los parámetros del lazo (ICP/LPF) por puertos directos. Los seis PLL del core están regenerados para él en `fpga/pll138/`. Además impone dos límites que el PLLA no tenía: VCO entre 650 y 1300 MHz y frecuencia de comparación (PFD) entre 19 y 81,25 MHz. Desde el pad de 50 MHz no salen 108/54/27 ni 371,25 exactos y enteros, así que los PLL van **en cascada**, como en los cores de nand2mario para esta consola: `pll_27` (50 ÷ 2 × 27, VCO 675) da 27,000 MHz exactos y de él cuelgan `pll_main` (× 40, VCO 1080: 108, 54, 27, 135 y 36 MHz), `pll_86` (VCO 945) y `pll_ddr3` (× 33, VCO 891: 297 MHz para la DDR3 y 74,25 para el HDMI). `pll_main` y `pll_ddr3` esperan en reset al lock de `pll_27`. El vídeo y la DDR3 siguen teniendo sus propios PLL, a propósito: así el HDMI no comparte nada con el bus del MSX y los cruces se reducen a FIFOs y sincronizadores.

| Reloj | Frecuencia | Quién lo usa |
|---|---|---|
| `clk_108m` | 108,000 MHz | El controlador de SDRAM |
| `clk_54m` | 54,000 MHz | El Z80 y todo el bus del MSX: slots, puertos, PPI, PSG, SCC, mezclador, SD |
| `clk_27m` | 27,000 MHz | Registros de configuración, RTC, OPL3, UART del ESP, cronómetro de la SD, streamer de flash |
| `clk_135` | 135,000 MHz | Serializadores TMDS heredados (el HDMI real va por la cadena de vídeo) |
| `clk_wave375` | 36,000 MHz | Motor PCM del OPL4. En el 60K son 37,5 MHz (de ahí el nombre de la señal); aquí sale del mismo VCO de 1080 dividido por 30, en fase con 27/54/108, y el CE de 44,1 kHz del motor se recalculó a 14112/15000 |
| `clk_86` | 85,909 MHz | El V9968 y su shim de VRAM. Es 27 × 35/11, cero ppm respecto a 24 veces la subportadora de color |
| `clk_hdmi` / `clk_hdmi5` | 74,25 / 371,25 MHz | Píxel y TMDS ×5 del 720p. `pll_74` multiplica por 10 (VCO 742,5) el 74,25 que presta el PLL de la DDR3 (VCO 891 ÷ 12, sin gatear), como en la cascada de nand2mario para la 138K |
| DDR3 | 297 MHz | Un solo controlador, el de la VRAM del V9968 (las ondas del OPL4 van por la SDRAM), con el reloj de calibración desde el pad de 50 MHz. El `pll_stop` de la IP va directo a `ENCLK2` del PLL; en el 60K era la secuencia mDRP con `pll_mDRP_intf` |

El Z80 no va a 3,58 MHz: va a 54 MHz con habilitaciones de reloj que dibujan los T-estados. El divisor normal es 108 ÷ 30 = 3,6 MHz; el turbo es 108 ÷ 20 = 5,4 MHz con un pulso tragado cada 176, que da 5,369318 MHz exactos, la receta del turbo de Panasonic. El cambio entre los dos se hace sin glitch, solo cuando el bus está en reposo y la SDRAM libre.

Dos frenos deliberados mantienen la velocidad de un MSX real: un estado de espera en cada búsqueda de opcode (M1) y otro en cada escritura a memoria. En turbo la latencia de la SDRAM y su refresco no caben en un T-estado de 186 ns, así que hay una guarda que cuesta un 18 % del turbo teórico; se probó a quitarla en el 60K y la máquina se colgaba.

En el sdc, `clk_86` está **sobre-restringido a 11,30 ns** (el periodo real es 11,64): es la forma de obligar al rutador de Gowin, que cumple el periodo y para, a dejar margen. Un gate OK con 0,07 ns contra 11,30 son unos 0,41 ns reales. En el 138 ese dominio cierra alrededor de uno de cada tres dados; el resto del chip va holgado (CLS ~57 %, BSRAM 116/340, PnR de unos 7 minutos), así que las campañas son de tres dados (capítulo 07).

## 4. El bus del MSX

El Z80 es un **G80a**, la variante del T80 en Verilog, en modo Z80 con ciclos de E/S estándar. El bus que sale de él es el de un MSX de cuatro slots primarios, dos de ellos expandidos:

| Slot | Contenido |
|---|---|
| 0-0 | BIOS principal (32 KB) |
| 0-2 | ROM del driver de red UNAPI (16 KB, página 1) |
| 0-3 | ROM del logo de arranque (16 KB, página 1) |
| 1 | Segundo SCC o Game Master 2, según Ajustes; libre si no |
| 2 | Megaram: el cartucho emulado, con su SCC, una vez que el menú lanza una ROM |
| 3-0 | Mapper de RAM de 2 MB |
| 3-1 | SubROM (página 0), menú con FM-BIOS (página 1), segunda página del menú (página 2) |
| 3-2 | ROM del disco: Nextor y la ventana de la SD |
| 3-3 | Megaram en su posición de arranque, antes de lanzar nada |

La decodificación es la clásica: el registro de slot primario está en el puerto A del PPI y los registros de slot secundario en FFFFh de cada slot expandido. Todos los `*_req` que salen del decodificador están registrados en `clk_54m` y son mutuamente exclusivos; el mux de lectura del bus es un OR plano de esas peticiones. No es cosmética: viene del 60K, donde con la FPGA al 98 % de celdas lógicas los nodos IORQ_n y WR_n del Z80 están saturados y cualquier cono combinacional colgado de ellos aparece en la lotería de rutado. En el 138 la lógica cabe holgada, pero el diseño se conserva tal cual.

Las señales del bus que llegan a módulos en otros dominios se registran antes: el módulo de red y el V9968 ven el bus un ciclo tarde, y el glue del V9968 lo convierte en una transacción valid/ready por ciclo de E/S.

## 5. La memoria

`memory_ctrl` gobierna la SDRAM externa a 108 MHz. Es el controlador del MSXnano adaptado al bus de 16 bits: en cada turno sirve un byte, con la máscara DQM sacada del bit 0 de la dirección. Los turnos se reparten con un divisor libre de 108 ÷ 8 y ÷ 16 que marca las ranuras de CPU a 6,75 MHz, y los huecos vacíos los aprovechan dos puertos secundarios, `wv` para las ondas del OPL4 y `wv2`/`wv3` para la RAM de muestras del ADPCM-B en la línea principal (o para el V9968 cuando la VRAM va por SDRAM en la línea de respaldo).

La dirección física de 23 bits se elige en un mux de dos ramas. La rama normal es la de la CPU: mapper, BIOS, megaram, Game Master 2, kanji, menú y logo, cada uno con su región del capítulo 03. La otra rama es el **camino de streaming**, activo cuando la CPU está parada: por él escriben el streamer de la flash al arrancar y la DMA de la SD. La elección entre esos dos va por debajo, sobre registros, fuera del cono de la CPU, que en el 60K es donde vive el 98 % de la congestión.

El refresco de la SDRAM tiene dos modos. Con la CPU en marcha lo dispara la señal RFSH del Z80. Con la CPU parada entra un refresco autónomo, y ahí hay una regla dura aprendida a base de fallos: el refresco autónomo solo puede correr cuando se sabe que nadie está escribiendo, porque puede pisar una aceptación en vuelo. Por eso la señal `cpu_run` que lo gobierna junta el reset del Z80, el fin del streaming de flash, el arranque del ESP, la congelación del panel F12 y la ventana de espera de la DMA, y desde la V3.6d va registrada.

## 6. El vídeo

El VDP es el **V9968** de Takayuki Hara, el superconjunto del V9958 con comandos rápidos, paleta de 5 bits, sprites en modo 3 y VRAM de 256 KB. Va en su propio dominio de 85,9 MHz. El capítulo 05 cuenta su procedencia y su estado; aquí, cómo encaja:

1. **Glue del bus**. El V9968 espera un interfaz valid/ready. El glue registra el bus del Z80 y emite una transacción por ciclo de E/S en 98-9B (y en 88-8B, que se aliasa al mismo chip para el software que busca un V9968 como cartucho externo).
2. **Shim de VRAM**. El core pide la VRAM con un contrato de ocho ciclos. El shim la sirve con una caché de línea y prefetch y traduce las peticiones a palabras de 32 bits con máscara de bytes hacia el backend. Dos canales en paralelo, porque los modos de 256 bytes por línea consumen una palabra cada 730 ns y un canal solo no llegaba.
3. **Backend DDR3**. La VRAM vive en la DDR3 del SOM, con un controlador propio calcado del framebuffer de nand2mario para esta placa. La IP de Gowin (v3.0, x16, 297 MHz) es la misma que en el 60K: el netlist encriptado es portable dentro de Arora V, y nand2mario usa una sola para las dos consolas. El motor de reintentos escalonado de la calibración y los puertos 2Ah-2Ch (capítulo 05) van igual; la lotería de calibración por dado que se vio en el 60K es igual de aplicable aquí (pendiente de verificar en placa). Existe una línea de respaldo con la VRAM en la SDRAM compartida, que serializa cada palabra en hasta cuatro accesos al controlador de memoria; se conserva pero no es la que se entrega.
4. **msx2hdmi**. El puente al HDMI de 720p a 60 Hz. El HDMI corre en su dominio de 74,25 MHz y se alimenta del VDP a través de un anillo de 32 líneas en BRAM de doble reloj; la captura se auto-alinea con las señales reales de sincronismo y blanking del VDP. El audio va embebido en el mismo HDMI. Sobre esta imagen el BL616 puede superponer el panel de texto de la tecla F12.

Solo hay salida de 60 Hz. La geometría de 50 Hz del V9968 no está medida.

## 7. El audio

Siete generadores entran en un mezclador con saturación en `clk_54m`:

| Chip | Puertos | Implementación |
|---|---|---|
| PSG YM2149 | A0-A2 | Con filtro de paso bajo, y el registro 14 sirve el joystick USB |
| Segundo PSG | 10-12 | El mismo módulo, para el software que lo busca ahí |
| SCC / SCC+ | En la megaram, 9800h y B800h | `scc_wave2` en Verilog puro; el VHDL original lo barría la síntesis de la GW5A |
| Segundo SCC | Slot 1 | El mismo módulo, en el slot que no ocupa la megaram |
| OPLL YM2413 | 7C-7D | `jt2413` de JOTEGO |
| Y8950 MSX-Audio | C0-C1 | `jtopl2` más un decodificador ADPCM-B con los 256 KB de muestras del Y8950 en la SDRAM (`adpcm_sdram`, puerto `wv2` de `memory_ctrl`, filas 5120+; en la línea de respaldo con la VRAM en SDRAM cae a 32 KB en BSRAM) y su IRQ al Z80 |
| OPL4 MoonSound | C4-C7 y 7E-7F | FM con `opl3_fpga` y motor PCM `YMF278B` de 24 slots (a 36 MHz en el 138) con las ondas en la SDRAM (`wave_sdram`, por el puerto `wv` de `memory_ctrl`), cargadas de la flash en segundo plano tras el arranque |

El grupo clásico pasa por una ganancia maestra ajustable de 0 a 7 por el puerto #44, guardada en la flash; el OPL4 entra después de esa ganancia, a nivel nativo, porque la ganancia existe justamente para subir los chips flojos a la altura del MoonSound. El OPLL entra atenuado a tres cuartos para igualar el balance medido en openMSX entre su portadora y la del Y8950. En el 138 su salida se registra en `clk_27m` antes de entrar al mezclador (`jt2413_wav_r27`): el árbol de sumas de 22 ns que en el 60K cabía por poco en la relación 54 → 27 aquí no cerraba (−4,3 ns en la campaña p138f); cuesta 37 ns de retardo, inaudible. Hay salida mono y estéreo, según Ajustes.

## 8. Periféricos

- **Teclado, ratón y mando USB**, por los dos USB-A: dos instancias del host USB HID en el fabric, con un PLL de 12 MHz propio, sin hub. El teclado se traduce a la matriz del MSX; el ratón se presenta por el puerto de joystick como un ratón MSX; el mando (desde la v3.6f) sale del host como una palabra de doce bits en formato SNES (4 arriba, 5 abajo, 6 izquierda, 7 derecha, 8 A, 0 B, 10 y 11 los hombros) y va al puerto 1 del registro 14 del PSG, con autodisparo en los botones 3 y 4. El host es HID puro con el informe de los mandos genéricos (ejes a 00/7F/FF): un mando **XInput** (Xbox y los receptores que lo imitan) no es HID y no se ve. El BL616 tiene su propio host USB en el USB-C OTG y el firmware TangCore del 60K entiende XInput, pero exige un hub o adaptador OTG con alimentación en el puerto donde normalmente va el cargador; el MSXimus no cuenta con él para los mandos (y en la 138K ese firmware está además pendiente).
- **Reloj de tiempo real** en B4-B5, alimentado por el reloj del sistema.
- **Fuente kanji** por los puertos D8-DB, con los 256 KB de JIS1 y JIS2 en la SDRAM.
- **S1990 del turbo R** en E4-E7: la máquina se identifica como turbo R y la rutina CHGCPU de la BIOS mueve el turbo. No hay R800.
- **ESP32-C6** por los puertos 06-07: el puente `wifi_lite` es una UART con FIFO de recepción de 2080 bytes, prescaler fijo 27 ÷ 31 = 870968 bps (el firmware del ESP va a 859372, un 1,3 % menos, dentro de la tolerancia de una UART), y "recepción rápida" que retiene la lectura hasta 25 ms cuando el FIFO está vacío.
- **BL616**: el core le manda su estado por UART y él dibuja el panel F12 sobre el HDMI. Mientras el panel está abierto, el MCU congela el Z80 parando su `cpu_run`, sin resetearlo. Esto lo hace el firmware del 60K (fork de TangCore), que no se ha compilado para la 138K; con el partner firmware de Sipeed que trae la Console 138K el panel no existe. Pendiente.
- **Tira de ocho LEDs WS2812**: diagnóstico. El LED de red parpadea con el tráfico de la UART del ESP.
- **Ventilador** por temperatura (`fan_ctrl` + oscilador de anillo `ro_osc` como termómetro relativo). En el 138 `fan_en_o` va a 3,3 V y es de los pines sin contrastar contra el esquemático (pendiente de verificar en placa).
- **Telemetría serie** (`dbg_uart` por E22 y la UART del USB-C): contadores del shim del V9968, la DDR3, el audio y el ventilador; su periodo (`PERIOD_MS`) es el dado que siembra el placement de cada campaña.
- La telemetría, la tira de LEDs, el ventilador por temperatura y el segundo PSG, más un decodificador de teclado único, forman la *dieta* de la v3.6h (`DIETA_V36H` en `top.v`, apagada): se probó en el 60K y rutaba peor, ver el [capítulo 07](07-sintesis-campanas.md).
- **UART de depuración** a 54 MHz por un PMOD, apagada en las entregas.

## 9. Qué pasa al encender

1. `pll_27` engancha y con él la cascada de PLL. Un secuenciador de reset suelta tres etapas separadas 39 ms.
2. El **streamer de flash** copia el pack de BIOS, 512 KB más once bytes, desde 0x800000 de la flash a la SDRAM, byte a byte por el camino de streaming. Al final lee los once bytes de configuración: los seis de siempre (los dos registros de Ajustes, el byte de turbo al arrancar y el de ganancia) más los cuatro niveles del mezclador por fuente y su byte de comprobación (V3.7). Con el botón S2 pulsado se cargan los valores de fábrica.
3. Mientras tanto la DDR3 calibra y, en cuanto el pack está en su sitio, el **cargador de ondas** empieza a copiar los 2 MB de la YRW801 desde 0x900000 a la región de ondas de la SDRAM, en segundo plano.
4. El core espera unos tres segundos a que el **ESP32** haya arrancado, para que el driver de red lo encuentre a la primera.
5. Cuando todo eso está, y la DDR3 de la VRAM ha calibrado (desde la V3.6g el paso a `reset3_n` espera al `ready` del backend, con un tope de unos 10 s desde la V3.7b para arrancar a ciegas si nunca calibra; mientras tanto el LED de la SD parpadea solo), el Z80 sale de reset y arranca la BIOS del pack. El menú de la BIOS vive como cartucho en el slot 3-1 y toma el control en el escaneo de slots; lo que hace a partir de ahí lo cuenta el capítulo 04 del manual.

Un reset del MSX no repite el streaming: la SDRAM conserva su contenido, y por eso conserva también la megaram con la partida guardada, que es lo que permite el guardado de SRAM al siguiente arranque. Un apagado lo pierde todo.

## 10. Lo que no está

- No hay R800 ni MSX-DOS 2 en ROM; el identificador de turbo R sirve para el turbo y para el software que lo consulta.
- No hay salida analógica de vídeo ni de audio: todo va por el HDMI.
- No hay host USB en el ESP32-C6, por silicio; el teclado va por los USB de la placa.
- La variante con el V9958 original está eliminada del árbol; el V9968 es el único VDP.
- No hay firmware propio del BL616 para la 138K: el fork de TangCore del 60K no se ha compilado para ella y el partner firmware de Sipeed no conoce el panel F12. Flashear por el programador de Gowin no lo necesita.

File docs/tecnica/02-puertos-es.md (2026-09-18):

# 02. Mapa de puertos de E/S

Todos los puertos a los que responde el core, sacados del decodificador de `fpga/top.v` y de los módulos que cuelgan de él. Los puertos que no aparecen devuelven FFh en lectura y se ignoran en escritura: no hay bus externo.

El mapa es el mismo que el del MSXimus 60K: la Tang Console 138K es la misma placa base con otro SOM (el Tang Mega 138K), y el porte no toca la decodificación de E/S. Lo que cambia entre las dos máquinas (relojes, mapa de flash, licencia de Gowin) no se ve desde el Z80. Como el resto del porte, este mapa está compilado y comprobado en simulación, no en una placa 138K.

## 1. Resumen

| Puertos | Dispositivo | Estándar MSX |
|---|---|---|
| 06-07 | UART del ESP32 (WiFi UNAPI) | no |
| 10-12 | Segundo PSG | no |
| 2D-2F | Diagnóstico USB, diagnóstico del ratón, versión del core | no |
| 34-37 | Diagnóstico de la DDR3 y del cargador de ondas | no |
| 40-4F | E/S conmutada: configuración del core, SD por puertos, OCM, turbo Panasonic | OCM |
| 7C-7D | OPLL (MSX-MUSIC) | sí |
| 7E-7F | OPL4, parte de ondas (MoonSound) | sí |
| 88-8B | V9968 como cartucho externo (alias del interno) | HRA! |
| 98-9B | V9968 (el VDP de la máquina) | sí |
| A0-A2 | PSG | sí |
| A8-AB | PPI: slots, teclado, casete, click | sí |
| B4-B5 | Reloj de tiempo real | sí |
| C0-C1 | Y8950 (MSX-Audio) | sí |
| C4-C7 | OPL4, parte FM (MoonSound) | sí |
| D8-DB | Fuente kanji JIS1 y JIS2 | sí |
| E4-E7 | S1990 (identificación turbo R) | sí |
| F2 | Registro libre de 8 bits | no |
| FC-FF | Registros del mapper de RAM | sí |

## 2. La E/S conmutada: 40h a 4Fh

Es el mecanismo del OCM. Se escribe en el puerto **40h** el identificador de un dispositivo y a partir de ahí los puertos 41h a 4Fh son de ese dispositivo. Leer 40h devuelve el identificador invertido, que es como el software comprueba que el dispositivo existe. El MSXimus responde a tres identificadores:

| OUT 40h | Lee 40h | Dispositivo |
|---|---|---|
| 48h | B7h | La configuración del core, la del menú de Ajustes. Es el dispositivo "goauld" heredado del MSXnano |
| 08h | F7h | Turbo del T9769 de Panasonic, para el software que lo maneja así |
| D4h | 2Bh | E/S conmutada del OCM: órdenes inteligentes en 41h y DIP virtuales en 42h |

Sin dispositivo seleccionado, o con otro identificador, 41h-4Fh caen en el módulo OCM.

### Dispositivo 48h: la configuración del core

| Puerto | Acceso | Contenido |
|---|---|---|
| 41h | R/W | Config 1. bit 0 mapper activo, bit 1 megaram activa, bit 2 segundo SCC en el slot 1, bit 3 scanlines, bits 5-4 slot del mapper (11 = expandido 3-0), bits 7-6 slot de la megaram (11 = expandido 3-3 al arrancar; el dispositivo OCM la pasa a 10 = slot 2 al lanzar una ROM) |
| 42h | R/W | Config 2. bit 0 SD activa, bits 2-1 slot de la SD (3-2), bit 3 menú al arrancar, bit 4 Game Master 2 en el slot 1, bit 5 estéreo. En escritura, el bit 6 ordena guardar la configuración en la flash y el bit 7 ordena un reset; solo se almacenan los bits 5-0 |
| 43h | W | Configuración de la SRAM de la megaram, volátil. En ASCII8 el bit de habilitación; en ASCII16 distinto de cero activa el modo "valor 10h"; 0 la apaga |
| 44h | R/W | Mezclador de audio (v3.7). Escritura: `{solo_sel[7], canal[6:4], nivel[3:0]}`. Canal 0 = la ganancia maestra de siempre (nivel 0-7 = x1..x8, así que `OUT 44h,0..7` sigue significando lo mismo); canales 1-6 = PSG, SCC, OPLL, MSX-Audio, OPL4 FM, OPL4 wave, nivel 0-8 = k/8 (8 = tal cual, 0 = mudo); el 7 (WaveGame) solo existe en la línea Zynq. Con el bit 7 a 1 no escribe: solo selecciona el canal. Lectura: `{0, canal seleccionado, su nivel}`; el canal 7 lee Fh en el Tang (60K y 138K). Sonda del menú: `OUT 44h,F0h` + `IN 44h` = 7nh si hay mezclador. Todo se guarda en la flash con la orden de 42h |
| 45h | R/W | bit 0 = arrancar en turbo. Se guarda en la flash como el byte 'T' |
| 46h | R/W | Extensión del mapper de la megaram, volátil pero sobrevive al reset del MSX: bit 0 NEO (convierte ASCII8 en NEO-8 y ASCII16 en NEO-16), bit 4 mitad alta de los 4 MB para el cargador, bit 6 Game Master 2 armado. En lectura, el bit 7 a 1 dice que el core trae el Game Master 2 |
| 47h-4Fh | | El controlador de la SD por puertos, en el apartado siguiente |

Los registros 41h y 42h se escriben en una copia temporal y solo pasan a ser efectivos con la orden de guardar de 42h, que también reinicia la máquina. El 46h se pone a cero en cada reset a propósito: si el Game Master 2 quedara armado, el escaneo de slots de la BIOS se toparía con su firma en el slot 1.

### Dispositivo 48h, puertos 47h a 4Fh: la SD por puertos

Es el interfaz que usan el menú y el driver de Nextor. La ventana de memoria clásica sigue existiendo (capítulo 03) y ambos caminos gobiernan el mismo controlador.

| Puerto | Acceso | Contenido |
|---|---|---|
| 47h | W | Orden: bit 0 leer, bit 1 escribir, bit 2 DMA (con el bit 0), bit 3 contar patrones de mapper durante la DMA, bit 4 poner a cero los contadores, bit 7 inicializar la tarjeta. Además rebobina el puntero del búfer |
| 47h | R | Estado: bit 7 ocupado, bit 3 bloque listo, bit 2 error de CRC en lectura, bit 1 timeout, bit 0 error de CRC en escritura. Los bits 6-5 fijos a 0 y el bit 4 fijo a 1 sirven de sonda: un core sin puertos devuelve FFh |
| 48h-4Bh | W | Los cuatro bytes del número de sector, del bajo al alto |
| 48h | R | Tipo de tarjeta: 0 desconocida, 1 SD v1, 2 SD v2, 3 SDHC |
| 4Ch | R/W | Un byte del búfer de sector; el puntero avanza solo, pensado para INIR y OTIR |
| 4Dh | R/W | Número de bloques de la siguiente orden: 0 o 1 un solo sector, N mayor que 1 lectura o escritura multibloque |
| 4Eh | W | Índice del byte de información que devolverá la lectura de 4Eh |
| 4Eh | R | El byte de información elegido, según la tabla de abajo |
| 4Fh | W | 80h arma el registro de destino de la DMA y los tres OUT siguientes son la dirección; cualquier otro valor rebobina el puntero del búfer |
| 4Fh | R | Puntero del búfer, byte bajo, para depurar |

Índices de 4Eh:

| Índice | Devuelve |
|---|---|
| 2 | El mismo estado que 47h |
| 7, 8, 9 | Tamaño de la tarjeta (C_SIZE), tres bytes |
| 10 | C_SIZE_MULT |
| 11 | READ_BL_LEN |
| 12 | Tipo de tarjeta |
| 25, 26, 27 | Cronómetro de milisegundos, tres bytes. Al pedir el 25 se congela la foto de los 24 bits, y 26 y 27 devuelven esa misma foto |
| 28 | 54h ('T'): este core tiene cronómetro |
| 29 | 44h ('D'): este core tiene DMA de lectura |
| 31 | 4Dh ('M'): la DMA tiene modo lógico y contadores de mapper |
| 32-33, 34-35, 36-37, 38-39 | Los cuatro contadores de patrones de la DMA, 16 bits cada uno: Konami-SCC, Konami, ASCII8, ASCII16 |

El cronómetro va con el reloj de 27 MHz y no depende de las interrupciones del MSX; existe porque el menú medía la carga con el contador de la BIOS, que se para con las interrupciones inhibidas. Todo el detalle de la DMA está en el capítulo 06.

### Dispositivo 08h: el turbo de Panasonic

| Puerto | Acceso | Contenido |
|---|---|---|
| 41h | W | Solo el bit 0, activo a nivel bajo: 0 pone 5,37 MHz, 1 pone 3,58 MHz |
| 41h | R | bit 0 estado del turbo (0 = activo), bit 2 a 0 (turbo disponible), bit 7 a 1; es decir FAh en turbo y FBh en normal |

Es el protocolo que openMSX describe para el MSXMatsushita, y el que usan los juegos y utilidades que conocen el turbo de la serie FS-A1.

### Dispositivo D4h: la E/S conmutada del OCM

Llega del módulo `swioports` del OCM-PLD. El menú la usa para una sola cosa: la orden inteligente 0Fh en 41h, que pone el slot 2 en modo SCC-I interno, que es como el cargador escribe la megaram. Los DIP virtuales del puerto 42h fijan el modo de ese slot 2.

## 3. El resto de puertos, uno a uno

### 06h-07h: UART del ESP32

Es el puente `wifi_lite` de ducasp, agnóstico al módulo. Un byte por acceso, sin búfer de transmisión, FIFO de recepción de 2080 bytes.

| Puerto | Acceso | Contenido |
|---|---|---|
| 06h | W | Orden de velocidad. La versión "lite" solo reconoce la 20, que vacía el FIFO; la velocidad es fija |
| 06h | R | Saca un byte del FIFO de recepción. Si está vacío, el hardware retiene la lectura hasta 25 ms esperando un byte; si no llega, devuelve FFh y marca underrun |
| 07h | W | Byte a transmitir |
| 07h | R | Estado: bit 0 hay datos, bit 1 transmisión en curso, bit 2 FIFO lleno, bit 3 soporta recepción rápida, bit 4 underrun |

El módulo pone al Z80 en espera durante sus ciclos de E/S.

### 10h-12h: segundo PSG

Un segundo YM2149 completo, con la misma decodificación que el principal desplazada: 10h dirección, 11h escritura, 12h lectura. Para el software que espera un PSG ahí. (Con la opción `DIETA_V36H` desaparece y 12h lee FFh; en producción va.)

### 2Ah-2Fh: diagnóstico y versión

| Puerto | Devuelve |
|---|---|
| 2Ah | Arranque de la DDR3 (v3.7b): décimas de segundo desde el encendido hasta que la VRAM calibró (255 = 25 s o más, o no ha calibrado) |
| 2Bh | Arranque de la DDR3: duración en centésimas del intento de calibración que lo consiguió (255 = 2,55 s o más); sin calibrar, el intento en curso |
| 2Ch | Arranque de la DDR3: bit 7 = calibrada; bits 6-0 = intentos de calibración fallidos antes (0 = a la primera, 127 = saturado) |
| 2Dh | Estado del USB: bit 7 error de conexión en el USB 2, bit 6 en el USB 1, bits 5-4 tipo del USB 2 y bits 3-2 tipo del USB 1 (0 nada, 1 teclado, 2 ratón, 3 mando), bits 1-0 cuenta de informes recibidos, que cambia si el dispositivo habla |
| 2Eh | Estado interno del ratón |
| 2Fh | Versión del core, en BCD: 37h es la 3.7. El porte 138 devuelve el mismo valor que el 60K de la misma versión: no hay ningún byte que distinga las dos placas |

El menú de Ajustes muestra la versión leyendo 2Fh. Un core anterior a que existiera devuelve FFh, y el menú dice "desconocida".

Los tres de la DDR3 son la respuesta al arranque en negro desde un cargador que se vio en el 60K (capítulo 10 del manual); el 138 lleva la misma IP de DDR3 y el mismo motor de reintentos, así que la lotería de calibración por dado es igual de aplicable (pendiente de verificar en placa). Desde BASIC, `PRINT INP(&H2C) AND 127, INP(&H2B)*10, INP(&H2A)/10` dice cuántos intentos fallaron, cuántos milisegundos duró el bueno y a los cuántos segundos arrancó el vídeo.

### 34h-37h: DDR3 y cargador de ondas

Cuatro puertos de solo lectura que dejó el bring-up de la DDR3 para el OPL4, cuando las ondas vivían en ella (desde la _104 van por la SDRAM del dock, `wave_sdram`, y los puertos conservan el nombre y la interfaz): 34h diagnóstico de la memoria de ondas, 35h diagnóstico del motor, 36h estado del cargador (bit 2 = copiando la YRW801), 37h un byte de la memoria de ondas leído por anticipado.

### 7Ch-7Dh: OPLL

El YM2413 de MSX-MUSIC, solo escritura: 7Ch registro, 7Dh dato.

### 7Eh-7Fh: OPL4, ondas

La parte PCM del MoonSound: 7Eh registro y 7Fh dato del motor de 24 slots. La ROM de ondas es la YRW801 de 2 MB, copiada de la flash (0x900000 en el 138K) a la SDRAM del dock al arrancar (capítulo 03).

### 88h-8Bh y 98h-9Bh: el V9968

Los cuatro puertos clásicos del VDP: 98h datos de VRAM, 99h registros y estado, 9Ah paleta, 9Bh registros indirectos. El rango 88h-8Bh es un alias del mismo chip: el software escrito para el cartucho V9968 de HRA! lo busca ahí como VDP externo, y en el MSXimus el V9968 ya es el interno.

Los puertos 9Ch y 8Ch, el "puerto 4" que el V9968 define para los flags de interrupción, **no están decodificados**. El capítulo 05 explica qué implica.

### A0h-A2h: PSG

El YM2149 principal. En A2h con el registro 14 seleccionado se lee el joystick, que viene del mando o del ratón USB; el bit 6 del registro 15 elige el puerto. Los botones 3 y 4 del mando hacen autodisparo sobre los botones 1 y 2. El registro 15 se relee (lo último escrito): la BIOS lo lee, modifica y escribe en cada interrupción, y devolver FFh conmutaba el pin 8 del puerto 2 a 60 Hz y vaciaba el ratón (arreglado en la v3.6e del 60K, incluido en el porte). Los demás registros siguen devolviendo FFh al leerlos: el `O_DA` del YM2149 está sin conectar, aunque el modelo los sirve.

### A8h-ABh: PPI

| Puerto | Contenido |
|---|---|
| A8h | Registro de slots primarios |
| A9h | Lectura de la fila del teclado seleccionada |
| AAh | bits 3-0 fila del teclado, bit 4 motor del casete, bit 5 salida de casete, bit 6 LED de kana, bit 7 click del teclado. Se puede releer |
| ABh | Registro de control: el modo de poner y quitar bits sueltos del puerto C, que usa la BIOS para CAPS, el click y el motor |

### B4h-B5h: reloj de tiempo real

El RP5C01 de un MSX2: B4h selecciona el registro, B5h lo lee o escribe. Su reset está fijo a cero, así que hora y RAM sobreviven a los resets del MSX; no hay pila, al apagar se pierden. Con el ESP32 conectado, el driver de red puede ponerlo en hora por internet.

### C0h-C1h: Y8950

MSX-Audio: C0h registro, C1h dato. En lectura, C0h devuelve el estado con los flags de los temporizadores, el fin de muestra y el búfer del ADPCM. La IRQ va al Z80 en AND cableado, y arranca enmascarada.

### C4h-C7h: OPL4, FM

La parte OPL3 del MoonSound: C4h/C5h primer banco de registros, C6h/C7h segundo banco. En lectura, el estado.

### D8h-DBh: fuente kanji

El interfaz estándar: D8h y D9h fijan la dirección en JIS1, DAh y DBh en JIS2, y la lectura devuelve los bytes del glifo. Los 256 KB de fuente viven en la SDRAM.

### E4h-E7h: S1990

El controlador del turbo R, solo para identificarse como tal. La BIOS y el software leen aquí el modo de CPU y CHGCPU conmuta el turbo del core. No hay R800 detrás.

### F2h: registro libre

Un byte de lectura y escritura sin función en el hardware. Se lee tal como se escribió.

### FCh-FFh: mapper de RAM

Los cuatro registros de segmento del mapper, uno por página de 16 KB. Son de **solo escritura** en el core: leerlos devuelve FFh. El mapper es de 2 MB, así que se usan siete bits y el octavo se ignora, que es como se comporta un mapper real de 8 bits con menos memoria. Que sean de solo escritura es lo que obligó a dar a la DMA de la SD un modo lógico que traduce direcciones con estos registros dentro del core (capítulo 06).

## 4. Puertos que existen en un MSX y aquí no

- **Impresora** (90h-91h): no hay.
- **Joystick por PSG**: sí, pero solo desde USB; no hay conectores DE-9.
- **Puerto 4 del V9968** (9Ch): no decodificado, ver arriba.
- **Cinta**: el motor y la salida existen en el PPI, pero no hay conector; la cinta virtual que se preparó para el ESP32 se retiró.

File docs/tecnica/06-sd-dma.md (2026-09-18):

# 06. La tarjeta SD y la DMA

Cómo llega un sector de la tarjeta a la memoria del MSX. Hay cuatro caminos, del más antiguo al más rápido, y todos gobiernan el mismo controlador. Sale de `fpga/src/wondertang/` (el lector, el controlador de órdenes y los puertos), de `fpga/src/sd_dma.sv` y del driver `nextor214/sd_rw_ports.inc` del repositorio de la BIOS.

## 1. El controlador

La tarjeta se maneja en **modo SD nativo de un bit**, no en SPI: líneas CMD, CLK y DAT0. El lector es el `sd_reader` del proyecto WonderTANG, con la escritura que le añadió Felipe Antoniosi, y encima de él el MSXimus ha ido poniendo capas:

| Capa | Qué aporta |
|---|---|
| `sdcmd_ctrl` | Las órdenes SD y su CRC7 |
| `sd_reader` | Inicialización de la tarjeta (SD v1, v2 y SDHC), lectura y escritura de sector, CRC16 de datos, y desde la 3.5c **multibloque** con CMD18 y CMD25 sobre un único búfer de 512 bytes |
| Búfer de sector | Una BSRAM de doble puerto: el puerto A lo ve el Z80, el puerto B lo ve la tarjeta, y también la DMA |
| `sdc_ioport` | Los registros en los puertos 47h-4Fh |
| `sd_dma` | La copia del búfer a la RAM sin pasar por el Z80 |

Dos relojes. La inicialización va a 69,6 kHz, por debajo de los 400 kHz que exige la norma. La transferencia va a **6,75 MHz**: el divisor rápido está a cero, que es el mínimo del diseño actual porque el periodo de `sdclk` son `2 × divisor + 4` ciclos de 27 MHz. Subir a 13,5 MHz exigiría rehacer el divisor y el muestreo, y es la fase 3 pendiente.

Todo el módulo va en `clk_27m` y sus salidas están registradas, con las órdenes convertidas en pulsos de un ciclo con el dato ya capturado. No es una elección de estilo: en el 60K los nodos IORQ_n y WR_n del Z80 estaban saturados, y colgar de ellos un decodificador combinacional se llevó por delante tres campañas de síntesis seguidas antes de hacerlo así. El 138K hereda el módulo tal cual, con los mismos relojes.

Un detalle de arranque que costó encontrar: el lector solo acepta la orden de inicializar estando en reposo. Si algo arranca la tarjeta antes que Nextor, la petición de Nextor se ignora en silencio y el MSX no arranca. El menú, que monta la tarjeta antes que Nextor, la deja en reposo al terminar.

## 2. Los cuatro caminos

### Camino 1: la ventana de memoria

El interfaz original del WonderTANG. En la página 1 del slot 3-2, activa tras escribir un 1 en 7E00h:

| Dirección | Contenido |
|---|---|
| 7C00h-7DFFh | El búfer de sector, 512 bytes, byte a byte |
| 7E00h | Habilitar (1) o deshabilitar (0) los registros |
| 7E01h | Orden: 1 leer, 2 escribir, 80h inicializar |
| 7E02h | Estado |
| 7E03h-7E06h | Número de sector, cuatro bytes |
| 7E07h-7E18h | Datos de la tarjeta: tamaño, multiplicador, longitud de bloque, tipo, fabricante, OEM, nombre, número de serie |
| 7E80h | Habilitar el SCC+ |

Un sector por orden, y el Z80 lo saca del búfer con LDIR a 21 T-estados por byte. Es el camino de los drivers antiguos y sigue funcionando tal cual; una orden dada por la ventana fuerza el contador de bloques a 1.

### Camino 2: los puertos, sector a sector

Los registros del capítulo 02 en 47h-4Fh. La ganancia es que el búfer se lee con INIR, a 16 T-estados por byte, y que el búfer de destino puede estar en cualquier página, no solo donde la ventana deje sitio. Con Nextor 3 eso resolvió un solape entre su kernel y la ventana.

### Camino 3: los puertos, multibloque

Con N mayor que 1 en 4Dh, la orden de 47h lanza un CMD18 o CMD25 y la tarjeta encadena N sectores sin volver a negociar. Con un solo búfer, el protocolo entre el lector y el que vacía es este: cuando hay un bloque en el búfer, el lector para el reloj de la tarjeta, la tarjeta se queda en espera, y levanta `blk_rdy`; el que vacía lee los 512 bytes por 4Ch y, al pasar por el byte 511, el puerto emite `buf_ack`, que reanuda el reloj y trae el siguiente bloque. En escritura es simétrico.

### Camino 4: la DMA

Con el bit 2 en la orden de lectura, el búfer no lo vacía el Z80 sino el core. La cuenta que lo motivó, medida en el 60K: la tarjeta tarda 0,6 ms en traer un bloque y el Z80 tardaba 3 ms en vaciarlo, así que la tarjeta esperaba parada el 80 % del tiempo. Con la DMA el vaciado son 150 µs y el cuello vuelve a ser la tarjeta.

Las velocidades medidas en placa **en el 60K** con la prueba 1 del menú de pruebas, sobre los mismos 128 KB (el controlador, la DMA y los relojes de 27 y 54 MHz son los mismos en el 138K, así que cabe esperar las mismas cifras, pero no se han medido: pendiente de verificar en placa):

| Camino | KB/s |
|---|---|
| Ventana | 90 |
| Puertos, sector a sector | 104 |
| Puertos, multibloque | 112 |
| DMA | 640 |

Con turbo los tres caminos por Z80 suben (109, 129 y 144) y la DMA no cambia, porque durante ella la CPU está parada.

## 3. Cómo funciona la DMA

La máquina de estados vive en `clk_54m`, el dominio de la RAM:

1. El Z80 deja el destino con `OUT 4Fh,80h` seguido de tres bytes, programa el sector y los bloques, y da la orden 05h en 47h. La instrucción siguiente al OUT no llega a ejecutarse hasta que todo ha acabado.
2. La DMA pide congelar la CPU y espera a que el bus esté en reposo: sin ciclo de memoria ni de E/S en curso, sin M1, sin espera pendiente y con el controlador de RAM libre. Entonces corta la habilitación de reloj del Z80. Sin CPU no hace falta árbitro: el puerto de RAM queda libre y la DMA escribe por el mismo camino de streaming que usa la flash al arrancar.
3. Por cada bloque espera a `blk_rdy`, o al fin de la orden en el último bloque, que no lo levanta. Antes del primer byte deja pasar 40 ciclos de guarda por si hay un refresco de SDRAM en vuelo. Luego lee los 512 bytes por el puerto B del búfer, que está ocioso mientras la tarjeta espera, y los escribe uno por turno del controlador. Al terminar manda `buf_ack`.
4. Con la orden acabada y el búfer vacío, suelta la CPU. El Z80 despierta en la instrucción siguiente al OUT y lee el estado de 47h como siempre.

Si la orden falla, por timeout o por CRC, el bloque no se copia y la máquina termina igual: nunca se queda colgada, y el estado dice qué pasó.

**El refresco de la SDRAM** es la parte delicada. Con la CPU parada, el controlador entra en refresco autónomo, y ese refresco puede pisar una escritura en vuelo. Por eso la DMA solo lo permite mientras está esperando a la tarjeta, que son 600 µs por bloque, de sobra para varios refrescos, y lo prohíbe durante la ráfaga de escrituras. Esa señal entra en la misma `cpu_run` que gobierna el refresco en todos los demás casos, y desde la 3.6d va registrada porque era el peor camino de temporización de la campaña del 60K.

**Coste**: unos 150 registros y ninguna BSRAM (en el 60K está al 100 %; en el 138K sobra, 116 de 340, pero el módulo es el mismo). Nada en el cono de la CPU: el mux de la RAM sigue teniendo dos ramas, y la elección entre flash y DMA va por debajo, sobre registros.

### Los dos modos de destino

| Modo | Byte alto del destino | Dirección |
|---|---|---|
| **Físico** | bit 7 = 0 | 23 bits de RAM, lineal. El menú carga así la megaram: la dirección de un segmento es `{~A21, A21, A[20:0]}` con A = mitad × 2 MB + segmento × 8 KB + desplazamiento |
| **Lógico** | bit 7 = 1 | Los 16 bits bajos son una dirección del Z80. El core la traduce con los registros del mapper: física = `{00, registro[página][6:0], desplazamiento[13:0]}`, en el banco A. Al cruzar los 16 KB pasa a la página siguiente, como haría el Z80 escribiendo de seguido |

El modo lógico existe porque los registros FCh-FFh son de solo escritura: el driver de Nextor no puede leerlos para calcular una dirección física, pero el core sí los tiene. Ojo con el armado: 80h en 4Fh arma el registro solo estando desarmado; una vez armado, un tercer byte de 80h es un destino lógico con segmento 0. Así el menú anterior sigue valiendo.

### Los contadores de mapper

Con el bit 3 en la orden, mientras copia, la DMA busca el patrón `32 lo hi`, la instrucción LD (nn),A con que los mappers cambian de banco, y cuenta las direcciones que caen en cada familia:

| Familia | Direcciones |
|---|---|
| Konami-SCC | 5000h, 9000h, B000h y 7000h |
| Konami | 4000h, 8000h, A000h y 6000h |
| ASCII8 | 6800h, 7800h y 6000h, 7000h |
| ASCII16 | 6000h, 7000h y 77FFh |

Es la misma tabla que usaba el menú escaneando byte a byte en el Z80. El bit 4 pone los contadores a cero antes; sin él acumulan de una orden a la siguiente, que es lo que hace el menú a lo largo de los 256 KB que analiza. Un patrón que cruza de bloque se detecta igual, porque la ventana de tres bytes no se reinicia entre bloques. El resultado se lee en 4Eh, índices 32 a 39, y el análisis de una ROM sin etiqueta pasa de siete segundos a nada: es la misma DMA que ya la estaba cargando.

Las ROMs que cambian de banco de otra forma, con LD (HL),r por ejemplo, no dejan patrón y el mapper hay que elegirlo a mano con la tecla M.

## 4. Quién usa cada camino

| Cliente | Camino | Notas |
|---|---|---|
| Menú, cargar una ROM | DMA física por clusters enteros | Si el core no contesta 'D' en el índice 29, vuelve a los puertos con INIR |
| Menú, analizar una ROM | DMA con contadores | Sin 'M', DMA sin contadores y escaneo con CPIR desde la ventana de la megaram; sin 'D', el escaneo antiguo sector a sector |
| Menú, montar un disco | Puertos | Solo escribe el descriptor de emulación de Nextor |
| Driver de Nextor, lectura | DMA lógica | Solo si el core contesta 'M' y todas las páginas del búfer son RAM del mapper en el slot 3-0 y ninguna es la página 1, donde vive el propio driver. Si no, puertos con INIR |
| Driver de Nextor, escritura | Puertos multibloque con OTIR | No hay DMA de escritura |
| Drivers antiguos | Ventana | Sin cambios |

El driver de Nextor es un único include compartido por Nextor 2.1.4 y Nextor 3: sondea el core al arrancar (un core sin puertos devuelve FFh en 47h) y elige el camino en cada petición. El pack de Nextor 3 del MSXnano lleva la misma ROM; allí la sonda falla y va por la ventana.

## 5. Firmas: cómo sabe el software qué core tiene delante

| Sonda | Significa |
|---|---|
| IN 47h distinto de FFh, con el bit 4 a 1 y los bits 6-5 a 0 | Hay puertos (3.5c o posterior) |
| 4Eh índice 28 = 'T' | Hay cronómetro (3.5d) |
| 4Eh índice 29 = 'D' | Hay DMA de lectura (3.6) |
| 4Eh índice 31 = 'M' | La DMA tiene modo lógico y contadores (3.6c) |

Un mismo pack de BIOS funciona con cualquier core desde la 3.5c: cada pieza sondea y se degrada al camino anterior.

## 6. Verificación

- `tools/sd_tb/`: bancos en Icarus Verilog con un modelo de tarjeta. `tb_sd` para el lector en sus tres velocidades, `tb_sdio` para los puertos, `tb_mstimer` para el cronómetro, `tb_glue` para el pegamento con el bus y `tb_sddma` para la DMA: registro de destino, CMD17, CMD18 de cuatro bloques, espera con el bus ocupado, orden normal tras una DMA, guarda del refresco, modo lógico cruzando de página y contadores contra una cuenta por software.
- En placa: tecla T, prueba 1, mide los cuatro caminos sobre los mismos 128 KB con el cronómetro del core. Solo lee. En el 138K esta prueba está pendiente de placa; el RTL de la SD y de la DMA es el mismo que el del 60K.

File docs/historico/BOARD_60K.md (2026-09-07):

# BOARD_60K — Pinout GW5AT-60 (Tang Console 60K) y skeleton .cst para el port MSXnano

**Objetivo**: mapear el pinout del **GW5AT-60** en la **Tang Console 60K** (SOM Tang Mega 60K)
para portar el core MSXnano desde el Tang Nano 20K (GW2AR-18C). Este documento cubre la parte
**A3 (Constraints)** y parte de **A4 (Companion BL616)** de la guía de port
`fpga/AUDIT_PRE_PORT_60K.md` (secciones 5.A3 y 5.A4).

**REGLA de este documento**: todo pin va anclado a una fuente real (URL + fichero). Lo no
confirmado va marcado **INCIERTO** y no lleva número inventado. Los pines FPGA de la columna
"pin GW5AT-60" NO son suposiciones: salen del `.cst` oficial de un core que corre HOY en la
Tang Console 60K.

---

## 0. Contexto y hallazgo principal

El MSXnano vive en el **mismo ecosistema** que el core de referencia elegido: FPGA-Companion /
BL616 de Harbaum + MiSTle-Dev (el firmware del companion del MSXnano es "the same version as for
the Tang Nano 20K", ver `AUDIT_PRE_PORT_60K.md:99-101` y el propio README de C64Nano). Por eso la
fuente-de-verdad más fiable para el pinout es el `.cst` del **C64Nano** para el Tang Console 60K,
no un schematic PDF suelto: es un `.cst` que sintetiza y arranca en la placa real con la misma
topología BL616-onboard que necesitamos.

- **Fuente primaria (ALTA confianza)** — pinout FPGA verbatim de un core funcionando:
  `MiSTle-Dev/C64Nano` → `src/tang/console60k/c64nano.cst` y `.../c64nano.sdc`
  https://github.com/MiSTle-Dev/C64Nano/blob/main/src/tang/console60k/c64nano.cst
  https://github.com/MiSTle-Dev/C64Nano/blob/main/src/tang/console60k/c64nano.sdc
- **Fuente del mapeo BL616↔FPGA (ALTA)** — tabla JTAG-repurposed:
  `MiSTle-Dev/FPGA-Companion` → `SPI.md`
  https://github.com/MiSTle-Dev/FPGA-Companion/blob/main/SPI.md
- **Fuente de placa / device part (MEDIA)** — Sipeed Wiki + CNX:
  https://wiki.sipeed.com/hardware/en/tang/tang-console/mega-console.html
  https://www.cnx-software.com/2025/05/27/sipeed-tang-console-a-gowin-gw5ast-gw5at-board-with-60k-or-138k-lut-for-fpga-development-and-retro-gaming/
- **Referencia cruzada de pinout (MEDIA)** — `nand2mario/snestang` `src/boards/mega60k.cst`
  y `console.cst` (mismos pines HDMI G15/G16, J14/H14, J15/H15, K17/J17 → doble-confirmación).
  https://github.com/nand2mario/snestang/tree/main/src/boards

**Device part**: `GW5AT-LV60PG484AC1/I0` (paquete PBGA484). Confirmado por Sipeed Wiki
(GW5AT-LV60PG484AC1/I0) y por el `.gprj` del port (`tang_console_60k_c64.gprj`). Confianza ALTA.

---

## 1. La trampa del "IRQ = IO27" — aclaración obligatoria

El dato de partida "BL616 por SPI sobre pines JTAG repurposed con **IRQ = IO27**" **NO es un pin
del FPGA**: es la numeración **GPIO del propio BL616** (lado micro), y además corresponde al build
del **TN20K onboard**, no al Console 60K. Verificado en `FPGA-Companion/SPI.md`:

| Señal | GPIO del **M0S Dock** → pin FPGA (TN20K) | GPIO **onboard TN20K** → pin FPGA (TN20K) |
|---|---|---|
| CSN | GPIO12 → 56  | GPIO0 → 86  |
| SCK | GPIO13 → 54  | GPIO1 → 13  |
| MOSI  | GPIO11 → 41  | GPIO3 → 76  |
| MISO  | GPIO10 ← 42  | GPIO2 ← 75  |
| IRQN  | GPIO14 ← 51  | **GPIO13 ← 69** |

O sea: en TN20K-onboard el IRQ sale del **GPIO13 del BL616 al pin 69 del FPGA**. El "27" que
circulaba es la etiqueta del GPIO del micro en OTRA variante, no un pin del GW5AT-60. **En el Tang
Console 60K el mapeo es DISTINTO** y hay que tomarlo del `.cst` del Console 60K (sección 2), donde
la conexión onboard usa los pines **JTAG re-propósito** (TMS/TCK/TDI/TDO) + la antigua UART TX.
→ Regla: **no copiar el "IO27" a ningún sitio del port**. Confianza ALTA (contradice el dato de
entrada, con fuente).

---

## 2. Tabla de pinout — Tang Console 60K (GW5AT-60)

Todos los pines de la columna "pin GW5AT-60" provienen VERBATIM de
`C64Nano/src/tang/console60k/c64nano.cst` salvo donde se indique. Los bancos de tensión
(`BANK_VCCIO`) son los declarados en ese mismo `.cst`.

### 2.1 Companion BL616 onboard (JTAG-repurposed) — el equivalente al `spi_*` del MSXnano

| Señal (net C64Nano) | pin GW5AT-60 | IOSTANDARD / banco | función (etiqueta en .cst) | procedencia | confianza |
|---|---|---|---|---|---|
| `spi_csn` | **T13** | LVCMOS33 / VCCIO 3.3, PULL_UP | TMS · GPIO0 · _SS | C64Nano console60k.cst | ALTA |
| `spi_sclk`  | **V12** | LVCMOS33 / 3.3, PULL_NONE DRIVE=OFF | TCK · GPIO1 · SCLK (4K7 PD en SOM) | idem | ALTA |
| `spi_dat` | **R13** | LVCMOS33 / 3.3, PULL_NONE DRIVE=OFF | TDI · GPIO3 · MOSI | idem | ALTA |
| `spi_dir` | **U13** | LVCMOS33 / 3.3, PULL_NONE DRIVE=8 | TDO · GPIO2 · MISO (3K3 PD en board) | idem | ALTA |
| `spi_irqn`  | **U15** | LVCMOS33 / 3.3, PULL_NONE DRIVE=8 | antigua UART TX del BL616 | idem | ALTA |
| `bl616_jtagsel` | **V14** | LVCMOS33 / 3.3, PULL_UP | ex-UART-out del BL616, ahora entrada FPGA | idem | ALTA |
| `bl616_mon_tx`  | **R14** | LVCMOS33 / 3.3, DRIVE=8 | monitor/consola serie del BL616 | idem | MEDIA (opcional) |

Notas de diseño (de `AUDIT_PRE_PORT_60K.md:98-102`):
- El MSXnano de TN20K expone `spi_sclk/spi_csn/spi_dat/spi_dir/spi_irqn` (tang9k.cst:13-22). El
  **renombrado 1:1 a estos 5 pines onboard del Console 60K** es directo. Los nombres de net del
  MSXnano se conservan; solo cambian los `IO_LOC`.
- **`jtagseln` / `bl616_jtagsel`**: el Console 60K reconfigura los pines JTAG de programación en un
  interfaz SPI, y con ello **bloquea reprogramaciones posteriores por JTAG** (documentado por
  FPGA-Companion y nand2mario). Requiere el net-attribute especial `NET_LOC "jtagseln"
  V_JTAGSELN;` + `CLOCK_LOC "spi_io_clk" LOCAL_CLOCK;` que aparecen en la cabecera del `.cst`. Esto
  **NO existía en TN20K** → es nuevo en el port. Confianza ALTA.
- **Decisión pendiente (A4 del audit)**: en el Console 60K el M0S Dock externo deja de tener
  sentido como mitigación secure-boot (aquí el BL616 onboard SÍ arranca el partner). Si se decide
  quitar el dock, se borra `spi_ext`/mux (fpga_companion.v:47-59) y desaparece el TA1132 del SDC.
  El companion externo alternativo, si se quiere, va por **PMOD0** (sección 2.7), no por m0s[].

### 2.2 HDMI TMDS (onboard)

| Señal | pin GW5AT-60 (P,N) | IOSTANDARD | procedencia | confianza |
|---|---|---|---|---|
| `tmds_clk_p`  | **G15, G16** | LVCMOS33D DRIVE=8 PULL_NONE | C64Nano + snestang (doble) | ALTA |
| `tmds_d_p[0]` | **J14, H14** | LVCMOS33D DRIVE=8 | idem | ALTA |
| `tmds_d_p[1]` | **J15, H15** | LVCMOS33D DRIVE=8 | idem | ALTA |
| `tmds_d_p[2]` | **K17, J17** | LVCMOS33D DRIVE=8 | idem | ALTA |

Nota: doble-confirmados contra `snestang/src/boards/mega60k.cst` y `console.cst` (mismos pares).
El MSXnano hoy declara TMDS como `data_p[0..2]`/`clk_p` (tang9k.cst:53-61). Renombrado directo, PERO
el core TMDS del MSXnano (CLK_135 ×5 con `DYN_DA_EN`) hay que regenerarlo para GW5A o pasar al
serdes nativo (ver `AUDIT_PRE_PORT_60K.md:89` A2). Los PINES son ALTA; el IP TMDS no es cosa del .cst.

### 2.3 microSD (onboard, SDIO 4-bit)

| Señal | pin GW5AT-60 | IOSTANDARD | procedencia | confianza |
|---|---|---|---|---|
| `sd_clk` | **V15** | LVCMOS33 PULL_UP DRIVE=8 | C64Nano console60k.cst | ALTA |
| `sd_cmd` | **Y16** | LVCMOS33 PULL_UP DRIVE=8 | idem | ALTA |
| `sd_dat[0]` | **AA15** | LVCMOS33 PULL_UP DRIVE=8 | idem | ALTA |
| `sd_dat[1]` | **AB15** | LVCMOS33 PULL_UP DRIVE=8 | idem | ALTA |
| `sd_dat[2]` | **W14** | LVCMOS33 PULL_UP DRIVE=8 | idem | ALTA |
| `sd_dat[3]` | **W15** | LVCMOS33 PULL_UP DRIVE=8 | idem | ALTA |
| SD card-detect | **V13** (VCC 1.5V) | — | comentario en .cst ("TF_SDIO_DET V13") | MEDIA/INCIERTO |

El MSXnano usa 6 pines SD: `sd_sclk/sd_cmd/sd_dat0..3` (tang9k.cst:78-89) → mapeo 1:1
(ojo al renombrado `sd_dat[N]` vector vs `sd_datN` escalar; el RTL WonderTANG del MSXnano usa
escalares, decidir si se adaptan los nombres o el bus). El card-detect en TN20K no se usa; en el
60K está en V13 pero **es banco 1.5V** → si se cablea, requiere buffer/atención de nivel. INCIERTO
si el RTL actual lo necesita: hoy no.

### 2.4 Reloj de sistema y botones

| Señal | pin GW5AT-60 | IOSTANDARD / banco | nota | procedencia | confianza |
|---|---|---|---|---|---|
| `clk` (XO) | **V22** | LVCMOS33 PULL_NONE | **50 MHz** en Console 60K (no 27 MHz) | C64Nano .cst + .sdc (period 20ns) | ALTA |
| `key_reset_n` (s2) | **AA13** | LVCMOS15 PULL_UP / **1.5V** | botón reset activo-bajo | C64Nano .cst | ALTA |
| `key_user_n` (s1)  | **AB13** | LVCMOS15 PULL_UP / **1.5V** | botón user activo-bajo | idem | ALTA |
| (3er botón Y12 = NC) | Y12 | — | no conectado | comentario .cst | MEDIA |

**Impacto crítico de reloj (A2 del audit)**: el TN20K entra a **27 MHz** (`ex_clk_27m` pin 4,
tang9k.cst:1). El Console 60K entra a **50 MHz** en V22 (confirmado por el `.sdc`:
`create_clock -name clk -period 20`). → **Todo el árbol de PLL/CLKDIV se recalcula** (rPLL→PLLA,
VCO nuevo) y **todas las constantes absolutas** (÷30→3.6MHz, ÷20+swallow→5.369318MHz turbo WSX,
esp_boot 3s, autofire, prescaler 859372 bps del ESP, LFSR del RTC) parten ahora de 50 MHz, no 27.
Ver `AUDIT_PRE_PORT_60K.md:88-91`. El `.cst` solo fija el pin de entrada; el resto es RTL/IP.
Los botones s1/s2 del MSXnano (tang9k.cst:4-7, hoy en pines 88/87 a 3.3V) pasan a **AA13/AB13 en
banco 1.5V** → cambia el IOSTANDARD, cuidado con el `IO_TYPE`.

### 2.5 LEDs de estado

| Señal | pin GW5AT-60 | IOSTANDARD | nota | confianza |
|---|---|---|---|---|
| `leds_n[0]` | **G11** | LVCMOS33 DRIVE=4 | "fpga done" (activo bajo) | ALTA |
| `leds_n[1]` | **U12** | LVCMOS33 DRIVE=4 | "fpga ready" (activo bajo) | ALTA |
| `leds_n[2]` | **V13** | LVCMOS33 DRIVE=4 | "sys_act" (comentado en ref) | MEDIA |

El MSXnano declara **6 LEDs discretos** `led[0..5]` (tang9k.cst:37-48). El Console 60K de
referencia solo expone **2 LEDs onboard fiables** (G11/U12). → Decisión de port: reducir a 2 LEDs,
o llevar los otros 4 a pines de header/PMOD (INCIERTO cuáles; no hay pin confirmado → no invento).
Marcar 4 de los 6 LEDs como **INCIERTO / pendiente de asignar**.

### 2.6 WS2812B (tira de estado en carcasa) — INCIERTO

El MSXnano usa `ws2812_led` en un GPIO de header (pin 25 en TN20K, tang9k.cst:50). El `.cst` de
C64Nano para Console 60K **no expone ningún ws2812**. Un pin de header/PMOD libre serviría, pero
**no hay pin confirmado por una fuente** → **INCIERTO, sin número**. Candidato natural: una línea
libre de PMOD1 (`io[0..5]`, sección 2.7) o de los 2×20 headers. A confirmar con el schematic
oficial de Sipeed (aún no publicado con pinout FPGA a fecha de este doc). NO inventar el pin.

### 2.7 Companion externo alternativo (PMOD0) y GPIO PMOD1

Presente en el `.cst` de referencia por si el companion va **externo** en PMOD0 (mismo rol que el
M0S Dock del TN20K). Útil si se conserva la ruta dock:

| Señal | pin GW5AT-60 | rol | confianza |
|---|---|---|---|
| `pmod_companion_dout` | **V19** | MISO (IO10) | ALTA |
| `pmod_companion_din`  | **V18** | MOSI (IO11) | ALTA |
| `pmod_companion_ss` | **G22** | CSn (IO12) | ALTA |
| `pmod_companion_clk`  | **G21** | SCK (IO13) | ALTA |
| `pmod_companion_intn` | **E18** | IRQn (IO14) | ALTA |
| `io[0..5]` (PMOD1, p.ej. joystick DB9) | W19,W20,F19,F20,E22,D22 | GPIO genérico open-drain | ALTA |

Estos 5 `pmod_companion_*` son el sitio natural para un ws2812 o LEDs extra si se sacrifica el
companion externo. Anclado a C64Nano console60k.cst.

### 2.8 Flash NOR (MSPI) — re-mapear direcciones

| Señal | pin GW5AT-60 | nota | confianza |
|---|---|---|---|
| `mspi_cs`  | **T19** | W25Q64 (128 Mbit) | ALTA |
| `mspi_clk` | **L12** | | ALTA |
| `mspi_di`  | **P22** | | ALTA |
| `mspi_do`  | **R22** | | ALTA |
| `mspi_wp`  | **P21** | | ALTA |
| `mspi_hold`| **R21** | | ALTA |

El MSXnano usa 4 pines flash `mspi_cs/sclk/miso/mosi` (tang9k.cst:68-75). El Console 60K expone
además wp/hold (QSPI). **Impacto (sección 5.B del audit)**: la flash del Console 60K es **W25Q64 =
64 Mbit / 8 MB** y la **comparte el BL616**. El bitstream GW5AT-60 es MAYOR que el del GW2AR-18 →
hay que **re-mapear el pack (0x200000) y la config (0x280000)** del MSXnano y aplicar antes los
fixes de `flash_rw.v` (#1 write_terminate + plausibles). Confianza de PINES ALTA; el layout de
direcciones es decisión de port, no del .cst.

### 2.9 UART / WiFi ESP-01S

| Señal | pin GW5AT-60 | nota | confianza |
|---|---|---|---|
| `uart_rx` (ejemplo C64Nano) | **M13** (TWI SCL) | UART por USB-C; C64Nano lo mueve | MEDIA |
| `bl616_mon_tx` | **R14** | monitor serie BL616 | MEDIA |
| WiFi ESP-01S UART (rx/tx del MSXnano) | **INCIERTO** | ver abajo | INCIERTO |

El MSXnano lleva su propio UART al **ESP-01S** para WiFi UNAPI (`uart_rx` pin 28 / `uart_tx` pin 27
en TN20K, tang9k.cst:93-96) a **859372 bps FIJOS** (firmware ducasp). El Console 60K **no tiene un
conector ESP-01S dedicado**: habría que sacar 2 pines libres consecutivos por header/PMOD para el
ESP-01S. **No hay par de pines confirmado por fuente** → **INCIERTO, sin número**. Candidatos:
2 líneas de PMOD1 (`io[4]`=E22, `io[5]`=D22) o `uart_ext_rx/tx` (B22/C22 en el ref). A DECIDIR con
el schematic y con dónde se enchufa físicamente el ESP-01S en el dock; NO inventar.

---

## 3. Skeleton candidato de .cst (NO usar tal cual — verificar cada match)

> **Este bloque es un SKELETON, no un fichero listo.** Los bloques ALTA salen del `.cst` real del
> Console 60K y son fiables. Los bloques **INCIERTO** llevan `<<<INCIERTO>>>` y **NO tienen pin**:
> hay que rellenarlos con el schematic oficial o midiendo en la placa. Además, el audit avisa
> (`AUDIT_PRE_PORT_60K.md:93-94`, A3) que en Gowin un `IO_LOC` sobre un net inexistente **falla en
> silencio**: tras el primer PnR, **verificar en el log que cada constraint casa >0 objetos**.
> Nombres de net = los del top del MSXnano (spi_sclk, sd_dat0…, led[…]); ajustar al RTL real.

```tcl
// ============================================================================
//  msxnano_console60k.cst  — SKELETON port TN20K(GW2AR-18) -> Console 60K(GW5AT-60)
//  Device: GW5AT-LV60PG484AC1/I0  (PBGA484)
//  Fuente de pines ALTA: MiSTle-Dev/C64Nano src/tang/console60k/c64nano.cst
//  ⚠ VERIFICAR tras el 1er PnR que NINGUNA constraint quede sin match (fallo silencioso Gowin)
// ============================================================================

// ---- JTAG-repurposed / SPI-IO clock (NUEVO en el 60K, no existía en TN20K) ----
CLOCK_LOC "spi_io_clk" LOCAL_CLOCK;
NET_LOC   "jtagseln" V_JTAGSELN;
IO_PORT   "jtagseln" PULL_MODE=DOWN IO_TYPE=LVCMOS33 BANK_VCCIO=3.3;
IO_LOC    "bl616_jtagsel" V14;
IO_PORT   "bl616_jtagsel" PULL_MODE=UP IO_TYPE=LVCMOS33 BANK_VCCIO=3.3;

// ---- Companion BL616 onboard (equivale a spi_* del MSXnano) ----
IO_LOC  "spi_csn"  T13;  IO_PORT "spi_csn"  PULL_MODE=UP   IO_TYPE=LVCMOS33 BANK_VCCIO=3.3;
IO_LOC  "spi_sclk" V12;  IO_PORT "spi_sclk" PULL_MODE=NONE DRIVE=OFF IO_TYPE=LVCMOS33 BANK_VCCIO=3.3;
IO_LOC  "spi_dat"  R13;  IO_PORT "spi_dat"  PULL_MODE=NONE DRIVE=OFF IO_TYPE=LVCMOS33 BANK_VCCIO=3.3;
IO_LOC  "spi_dir"  U13;  IO_PORT "spi_dir"  PULL_MODE=NONE DRIVE=8   IO_TYPE=LVCMOS33 BANK_VCCIO=3.3;
IO_LOC  "spi_irqn" U15;  IO_PORT "spi_irqn" PULL_MODE=NONE DRIVE=8   IO_TYPE=LVCMOS33 BANK_VCCIO=3.3;

// ---- Reloj de sistema: 50 MHz (¡NO 27!) -> recalcular TODO el árbol PLL/CLKDIV ----
IO_LOC  "clk" V22;
IO_PORT "clk" IO_TYPE=LVCMOS33 PULL_MODE=NONE DRIVE=OFF;

// ---- Botones (banco 1.5V, activo bajo) ----
IO_LOC  "key_reset_n" AA13; IO_PORT "key_reset_n" IO_TYPE=LVCMOS15 PULL_MODE=UP DRIVE=OFF BANK_VCCIO=1.5;
IO_LOC  "key_user_n"  AB13; IO_PORT "key_user_n"  IO_TYPE=LVCMOS15 PULL_MODE=UP DRIVE=OFF BANK_VCCIO=1.5;

// ---- LEDs onboard (solo 2 fiables; los 4 extra del MSXnano => INCIERTO) ----
IO_LOC  "led[0]" G11; IO_PORT "led[0]" IO_TYPE=LVCMOS33 DRIVE=4 PULL_MODE=NONE BANK_VCCIO=3.3;
IO_LOC  "led[1]" U12; IO_PORT "led[1]" IO_TYPE=LVCMOS33 DRIVE=4 PULL_MODE=NONE BANK_VCCIO=3.3;
// <<<INCIERTO>>> led[2..5]: no hay pin confirmado en el 60K. Asignar por header/PMOD con schematic.

// ---- HDMI TMDS (pares) ----
IO_LOC  "tmds_clk_p"  G15,G16; IO_PORT "tmds_clk_p"  PULL_MODE=NONE DRIVE=8 IO_TYPE=LVCMOS33D;
IO_LOC  "tmds_d_p[0]" J14,H14; IO_PORT "tmds_d_p[0]" PULL_MODE=NONE DRIVE=8 IO_TYPE=LVCMOS33D;
IO_LOC  "tmds_d_p[1]" J15,H15; IO_PORT "tmds_d_p[1]" PULL_MODE=NONE DRIVE=8 IO_TYPE=LVCMOS33D;
IO_LOC  "tmds_d_p[2]" K17,J17; IO_PORT "tmds_d_p[2]" PULL_MODE=NONE DRIVE=8 IO_TYPE=LVCMOS33D;

// ---- microSD (SDIO 4-bit) ----
IO_LOC  "sd_clk"    V15;  IO_PORT "sd_clk"    IO_TYPE=LVCMOS33 PULL_MODE=UP DRIVE=8 BANK_VCCIO=3.3;
IO_LOC  "sd_cmd"    Y16;  IO_PORT "sd_cmd"    IO_TYPE=LVCMOS33 PULL_MODE=UP DRIVE=8 BANK_VCCIO=3.3;
IO_LOC  "sd_dat0"   AA15; IO_PORT "sd_dat0"   IO_TYPE=LVCMOS33 PULL_MODE=UP DRIVE=8 BANK_VCCIO=3.3;
IO_LOC  "sd_dat1"   AB15; IO_PORT "sd_dat1"   IO_TYPE=LVCMOS33 PULL_MODE=UP DRIVE=8 BANK_VCCIO=3.3;
IO_LOC  "sd_dat2"   W14;  IO_PORT "sd_dat2"   IO_TYPE=LVCMOS33 PULL_MODE=UP DRIVE=8 BANK_VCCIO=3.3;
IO_LOC  "sd_dat3"   W15;  IO_PORT "sd_dat3"   IO_TYPE=LVCMOS33 PULL_MODE=UP DRIVE=8 BANK_VCCIO=3.3;
// (nota: renombrar sd_sclk->sd_clk y vector/escalar sd_dat según el RTL WonderTANG)

// ---- Flash NOR MSPI (W25Q64 8MB, compartida con BL616 -> re-mapear direcciones del pack) ----
IO_LOC  "mspi_cs"  T19; IO_PORT "mspi_cs"  PULL_MODE=NONE IO_TYPE=LVCMOS33;
IO_LOC  "mspi_clk" L12; IO_PORT "mspi_clk" PULL_MODE=NONE IO_TYPE=LVCMOS33;
IO_LOC  "mspi_di"  P22; IO_PORT "mspi_di"  PULL_MODE=NONE IO_TYPE=LVCMOS33; // MOSI
IO_LOC  "mspi_do"  R22; IO_PORT "mspi_do"  PULL_MODE=NONE IO_TYPE=LVCMOS33; // MISO
IO_LOC  "mspi_wp"  P21; IO_PORT "mspi_wp"  PULL_MODE=NONE IO_TYPE=LVCMOS33;
IO_LOC  "mspi_hold" R21; IO_PORT "mspi_hold" PULL_MODE=NONE IO_TYPE=LVCMOS33;

// ---- WS2812B tira de estado ----
// <<<INCIERTO>>> ws2812_led: sin pin confirmado en el 60K. Candidato: PMOD1 io[5]=D22 o header 2x20.

// ---- WiFi ESP-01S UART (859372 bps fijos, firmware ducasp) ----
// <<<INCIERTO>>> uart_rx / uart_tx del ESP-01S: sin par de pines confirmado.
//   Candidatos: PMOD1 io[4]=E22 / io[5]=D22, o uart_ext_rx=B22 / uart_ext_tx=C22. Decidir con HW.

// ---- Memoria principal: NO son pines de usuario en el path DDR3 ----
//   El Console 60K lleva DDR3 512MB como HARD-IP (sin pines de usuario en el .cst).
//   Alternativa SDR: la placa acepta Tang-SDRAM en PMOD; el .cst de C64Nano SÍ trae un bloque
//   SDRAM completo (IO_sdram_dq/addr/ba/dqm/clk/wen/ras/cas/cs) EN EL PMOD.
//   -> Decisión de A1 del audit (DDR3 hard-IP vs SDR-en-PMOD). NO se resuelve en este skeleton.
```

**Sobre la memoria (aclaración importante)**: el dato de entrada dice "DDR3 es hard-IP (SIN pines
de usuario)" — **correcto para el DDR3 onboard**: el controlador DDR3 del GW5AT es IP dura y no
aparece como `IO_LOC` en el `.cst`. PERO el `.cst` de C64Nano para Console 60K **sí incluye un
bloque SDRAM completo con pines** (`IO_sdram_dq[0..15]` E14/E13/…, `O_sdram_addr[0..12]`,
`O_sdram_ba`, `O_sdram_dqm`, `O_sdram_clk` B17, etc.): esos pines son para el **módulo Tang-SDRAM en
el PMOD** (misma vía SDR que el TN20K, ver `TANG_CONSOLE_60K.md`). Es la ruta que permitiría
**reutilizar `memory.v` casi tal cual** en vez de reescribir a DDR3. Los pines SDRAM completos
están en la fuente si se elige esa vía; se han omitido del skeleton por brevedad y porque la
decisión A1 (DDR3 vs SDR-PMOD) está abierta en el audit.

---

## 4. Contexto de relojes (SDC) para el port

Del `Z80_goauld.sdc` actual (TN20K): reloj base `clock_27m` sobre el net `clk_27m`, generados
`clock_54m` (×2), `clock_108m` (×4, sobre `O_sdram_clk`), `clock_108i`, y `clock_VideoDHClk`/`DLClk`
(÷2/÷4). Todo anclado a nombres GW2A (`clk_main/rpll_inst/CLKOUT`) y a la RED, no al puerto — origen
de fallos silenciosos al portar (`AUDIT_PRE_PORT_60K.md:94`, A3). En el Console 60K:

- El reloj de ENTRADA es **50 MHz en `clk` (V22)**, no 27 MHz (`.sdc` de C64Nano:
  `create_clock -name clk -period 20`). El `create_clock` base del SDC nuevo va sobre `[get_ports {clk}]`.
- El SDC de referencia declara `spi_clk` (period 50, sobre `[get_ports {spi_sclk}]`) y
  `spi_io_clk` (LOCAL_CLOCK) → el dominio SPI del BL616 **sí se puede constrainear** en el 60K.
  Esto resuelve el hueco TA1132 que el audit señala en `mcu_spi_new.v:43/117` (A3): con el pin SPI
  limpio, `create_clock` directo sobre `spi_sclk`.
- Todos los `create_generated_clock` y `set_false_path` anclados a nombres GW2A
  (`rpll_inst/CLKOUT`, `O_sdram_clk`) hay que **regenerarlos con los nombres de instancia del PLLA
  del GW5A**. El SDC entero es nuevo, no se copia.

---

## 5. Recuento y estado

**Pines CONFIRMADOS (ALTA, del `.cst` real del Console 60K)** — 27 nets con pin fiable:
- Companion BL616: spi_csn T13, spi_sclk V12, spi_dat R13, spi_dir U13, spi_irqn U15,
  bl616_jtagsel V14 (6)
- HDMI TMDS: clk + d[0..2] = 4 pares (4)
- microSD: clk, cmd, dat0..3 (6)
- clk V22 + reset AA13 + user AB13 (3)
- LEDs onboard led[0] G11, led[1] U12 (2)
- Flash MSPI: cs, clk, di, do, wp, hold (6)

**INCIERTOS (sin pin, marcados en el doc, NO inventados)** — 3 grupos:
- `ws2812_led` (1 pin) — no expuesto en el ref
- ESP-01S UART rx/tx (2 pines) — sin conector dedicado en el 60K
- `led[2..5]` (4 pines) — el MSXnano lleva 6, el ref solo confirma 2 onboard

**MEDIA / opcional**: bl616_mon_tx R14, SD card-detect V13 (banco 1.5V), 3er botón Y12 NC,
uart por USB-C M13, LED sys_act V13.

**Contradicción resuelta con fuente**: el "IRQ = IO27" del brief es GPIO del BL616 (no pin FPGA) y
de la variante TN20K; en el Console 60K el `spi_irqn` va al pin FPGA **U15**. No propagar "IO27".

---

## 6. Fuentes

- C64Nano (pinout Console 60K, ALTA): https://github.com/MiSTle-Dev/C64Nano/blob/main/src/tang/console60k/c64nano.cst · https://github.com/MiSTle-Dev/C64Nano/blob/main/src/tang/console60k/c64nano.sdc · https://github.com/MiSTle-Dev/C64Nano/blob/main/TANG_CONSOLE_60K.md
- FPGA-Companion SPI.md (mapeo BL616↔FPGA, aclaración IRQ): https://github.com/MiSTle-Dev/FPGA-Companion/blob/main/SPI.md
- snestang (doble-confirmación HDMI/SDRAM): https://github.com/nand2mario/snestang/tree/main/src/boards
- Sipeed Wiki Tang Console / Mega 60K (device part, interfaces): https://wiki.sipeed.com/hardware/en/tang/tang-console/mega-console.html · https://wiki.sipeed.com/hardware/en/tang/tang-mega-60k/mega-60k.html
- CNX-Software (GW5AT-LV60P484A, specs): https://www.cnx-software.com/2025/05/27/sipeed-tang-console-a-gowin-gw5ast-gw5at-board-with-60k-or-138k-lut-for-fpga-development-and-retro-gaming/
- nand2mario BL616 dual-mode / TangCore (contexto companion): https://nand2mario.github.io/posts/2025/mcu_for_better_fpga_gaming/

_Referencias internas: `fpga/AUDIT_PRE_PORT_60K.md` (secciones 5.A2 relojes, 5.A3 constraints,
5.A4 companion, 5.B flash), `fpga/tang9k.cst`, `fpga/Z80_goauld.sdc`._

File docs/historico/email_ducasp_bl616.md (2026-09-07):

# Borrador de correo para ducasp (port UNAPI a BL616)

**Para**: ducasp (via GitHub issue en ESP32-UNAPI-Firmware, o su contacto de MSX.org)
**Asunto sugerido**: Porting your UNAPI firmware to the Bouffalo BL616 (new MSX FPGA target) — firmware ID request

---

Hi Daniel,

First of all, thank you for your amazing work on the ESP8266/ESP32 UNAPI
firmware and the whole MSX networking ecosystem — it has been running for
months in my MSXnano project (a standalone MSX2+ on the Tang Nano 20K FPGA,
derived from the Goa'uld/WonderTANG lineage, using your wifi.vhd UART core
and an ESP-01S with your legacy firmware).

I am now working on its bigger brother, "MSXimus": the same MSX2+ core
ported to the Sipeed Tang Console 60K (Gowin GW5AT-60). This board has an
onboard Bouffalo BL616 MCU (WiFi 6 + BT 5.2) with a factory-populated MHF4
antenna connector and a dedicated UART already wired to the FPGA fabric —
so it can become a zero-extra-hardware UNAPI modem.

My plan is to port your firmware to the BL616 as a sibling project
("BL616-UNAPI-Firmware"), using your excellent protocol documentation
(documentation/README.md of the ESP32 repo) as the normative spec, on top
of the Bouffalo SDK (FreeRTOS + lwIP + mbedTLS). Scope: the custom + TCP/IP
UNAPI command sets first (targeting your V2 driver), TLS next; I would
leave SSH out initially. The protocol implementation would remain LGPL-2.1
like your code, with proper attribution.

Two small things I wanted to ask before starting:

1. **Firmware ID**: could you reserve/bless an identifier for this target
   in your naming scheme (something like "UNBL616..." following your
   UN32C6xx pattern), so CFGESP/UPDTESP and future tools can identify it
   cleanly and never confuse it with an ESP build?

2. If you have any advice or "wish I had known" notes about the trickier
   corners of the firmware (the 2KB RX expectations, the update flows, or
   anything the docs understate), I am all ears.

And of course: if a BL616 target is something you would rather see done
differently (or inside your ecosystem in some other form), happy to adapt
— you are the upstream here.

Thanks again for everything you do for the MSX community!

Best regards,
Albert (Papipapito)
MSXnano / MSXimus — https://github.com/Papipapito/MSXimus

---

*Notas para Albert (no enviar): el repo de referencia es
https://github.com/ducasp/ESP32-UNAPI-Firmware — lo natural es abrir un
issue ahí con este texto; menciona Leo Manes/Stargate si responde bien
(él integró aquel port). El plan técnico completo está en la memoria de
Claude (análisis 2026-07-11: fases P0-P3, UART a 869.565 bps, esquema
partner@0x0 + app@0x40000 que conserva el USB-JTAG).*

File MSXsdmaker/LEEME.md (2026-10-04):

# MSX SD Maker 1.3 — preparar la tarjeta SD

*[English version](README.md)*

**MSX SD Maker** deja una tarjeta SD lista para usar en un **MSXimus** (Tang Console 60K, Tang Mega 138K o la versión Zynq), un **MSXnano** o una **MSX Pico**. En unos segundos hace todo esto:

1. Borra la tarjeta y la parte en particiones que MSX-DOS entiende.
2. Formatea cada partición.
3. Copia el sistema operativo (Nextor o MSX-DOS) en la primera partición.
4. Copia una colección de programas: SofaRun, Multi Mente, utilidades, red, música…
5. Escribe un `AUTOEXEC.BAT` que lo deja todo a mano al arrancar.
6. Relee lo escrito para comprobar que la tarjeta ha quedado bien.

No hay nada que instalar: es un solo fichero, `MSXsdmaker.exe`.

---

## Índice

1. [Qué necesitas](#1-qué-necesitas)
2. [Abrir el programa](#2-abrir-el-programa)
3. [Paso a paso](#3-paso-a-paso)
4. [Qué queda en la tarjeta](#4-qué-queda-en-la-tarjeta)
5. [El primer arranque en el MSX](#5-el-primer-arranque-en-el-msx)
6. [Poner juegos y programas](#6-poner-juegos-y-programas)
7. [Guardar como imagen en vez de tarjeta](#7-guardar-como-imagen-en-vez-de-tarjeta)
8. [Problemas frecuentes](#8-problemas-frecuentes)
9. [Para curiosos: cómo lo hace](#9-para-curiosos-cómo-lo-hace)
10. [Licencias y créditos](#10-licencias-y-créditos)

---

## 1. Qué necesitas

- **Un PC con Windows 10 u 11.**
- **Un lector de tarjetas**: el del portátil o uno USB.
- **Una tarjeta SD o microSD de 4 GB o más.** Lo más práctico es de 8 a 32 GB. Una de más de 32 GB también vale, pero con FAT16 solo se usan 8 particiones.
- **Saber qué versión de Nextor lleva tu máquina.** Depende del pack de BIOS o del `BOOT` que grabaste. Lo verás en el [paso 3.3](#33-el-sistema).

> ⚠️ **El programa borra la tarjeta entera.** Si tiene algo que quieras conservar, cópialo antes al PC.

---

## 2. Abrir el programa

1. Descarga el ZIP de la [última versión de MSX SD Maker](https://github.com/Papipapito/SD_Maker/releases/latest) (`MSX_SD_Maker_<versión>.zip`), en su repositorio ([SD_Maker](https://github.com/Papipapito/SD_Maker)), y **descomprímelo** donde quieras: dentro está `MSXsdmaker.exe` con estas instrucciones. En los repositorios de las máquinas también hay una copia en la carpeta `MSXsdmaker`.
2. Mete la tarjeta en el lector.
3. Haz doble clic en `MSXsdmaker.exe`.
4. Windows pregunta si permites que haga cambios en el equipo: responde **Sí**. Hace falta porque el programa escribe la tarjeta entera, tabla de particiones incluida.

**Versiones nuevas**: al abrirse, el programa mira en GitHub si hay una versión más nueva de MSX SD Maker; si la hay, lo dice y ofrece abrir la página de descarga. Sin internet no pasa nada.

**Si Windows muestra «Windows protegió su PC»** (SmartScreen): pulsa **Más información** y después **Ejecutar de todas formas**. Sale porque el programa no está firmado digitalmente.

**Si el antivirus se queja**: los programas hechos en Python y empaquetados en un solo `.exe` dan a veces falsos positivos. El código fuente está en [SD_Maker](https://github.com/Papipapito/SD_Maker) (y una copia en la carpeta `fuente/`).

---

## 3. Paso a paso

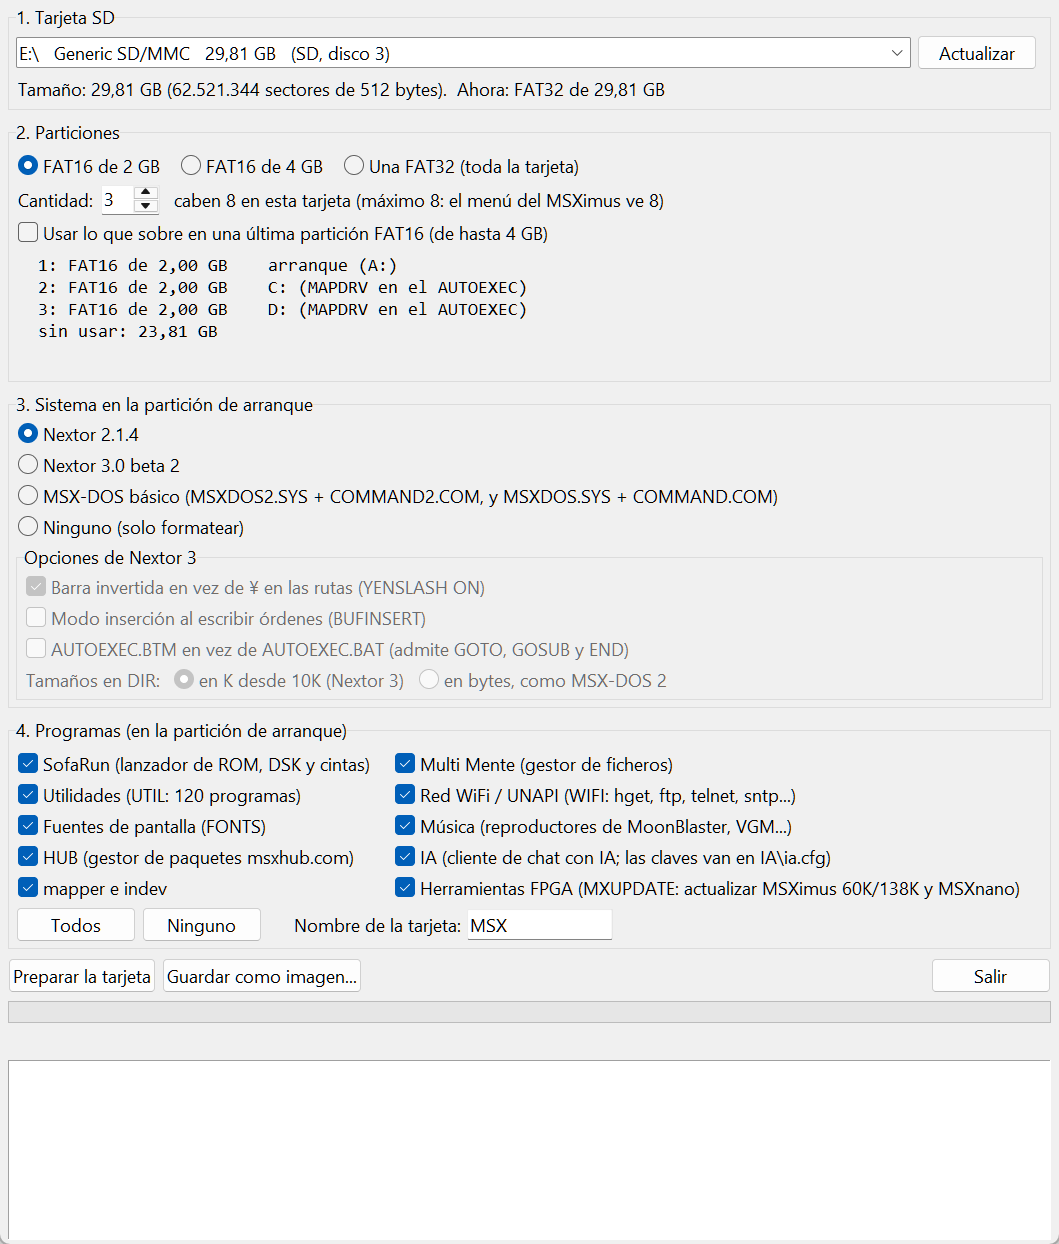
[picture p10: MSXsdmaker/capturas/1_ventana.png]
La ventana de MSX SD Maker


La ventana tiene cuatro bloques, de arriba abajo. Rellénalos en orden y pulsa **Preparar la tarjeta**.

### 3.1 La tarjeta

La lista de arriba muestra las tarjetas conectadas: letra de unidad, nombre del lector, tamaño y tipo. Si acabas de meter la tarjeta y no sale, pulsa **Actualizar**.

Debajo se ve el tamaño exacto y cómo está la tarjeta ahora; por ejemplo «Ahora: FAT32 de 29,81 GB».

> 🛡️ **Solo aparecen lectores de tarjetas SD y memorias USB extraíbles.** El disco donde está Windows no aparece nunca, y los discos duros externos tampoco. Aun así, fíjate bien en el tamaño antes de seguir.

### 3.2 Las particiones

Una **partición** es un trozo de la tarjeta que el MSX ve como una unidad de disco independiente (A:, C:, D:…). MSX-DOS no puede usar discos enormes, por eso la tarjeta se reparte en trozos que sí entiende.

| Opción | Tamaño de cada partición | Para qué sirve |
|---|---|---|
| **FAT16 de 2 GB** | 2 GB | **La opción recomendada.** Cada fichero ocupa como mínimo 32 KB, así que se desperdicia poco con ROM y DSK pequeños. |
| **FAT16 de 4 GB** | 4 GB, el máximo de Nextor | Menos particiones y más grandes. Cada fichero ocupa como mínimo 64 KB. |
| **Una FAT32** | Toda la tarjeta | Solo para el menú del MSXimus (ROM y DSK) y la MSX Pico. **MSX-DOS no la ve** (ver el aviso de abajo). |

**Cantidad.** El programa te dice cuántas particiones caben en tu tarjeta y no te deja pasar de ahí. El máximo es 8, que son las que recorre el menú del MSXimus. Si la tarjeta es más pequeña que una partición entera (las de «2 GB» tienen menos de 2 GB de verdad), se hace una sola partición con toda la tarjeta.

**«Usar lo que sobre en una última partición FAT16».** Márcalo para no desperdiciar el trozo final de la tarjeta: se crea una partición más, más pequeña, con lo que quede (hasta 4 GB). Si no lo marcas, ese espacio queda libre y ni Windows ni el MSX lo ven.

Debajo verás cómo quedará la tarjeta. Por ejemplo:

```
  1: FAT16 de 2,00 GB    arranque (A:)
  2: FAT16 de 2,00 GB    C: (MAPDRV en el AUTOEXEC)
  3: FAT16 de 2,00 GB    D: (MAPDRV en el AUTOEXEC)
  sin usar: 23,81 GB
```

Cuántas caben en las tarjetas más habituales (su capacidad real es algo menor que la de la etiqueta):

| Tarjeta | FAT16 de 2 GB | + lo que sobra | FAT16 de 4 GB | + lo que sobra |
|---|---|---|---|---|
| 2 GB | 1 con toda la tarjeta | — | 1 con toda la tarjeta | — |
| 4 GB | 1 | + 1 de 1,7 GB | 1 con toda la tarjeta | — |
| 8 GB | 3 | + 1 de 1,4 GB | 1 | + 1 de 3,4 GB |
| 16 GB | 7 | + 1 de 0,8 GB | 3 | + 1 de 2,8 GB |
| 32 GB | 8 | — | 7 | + 1 de 1,7 GB |
| 64 GB o más | 8 | — | 8 | — |

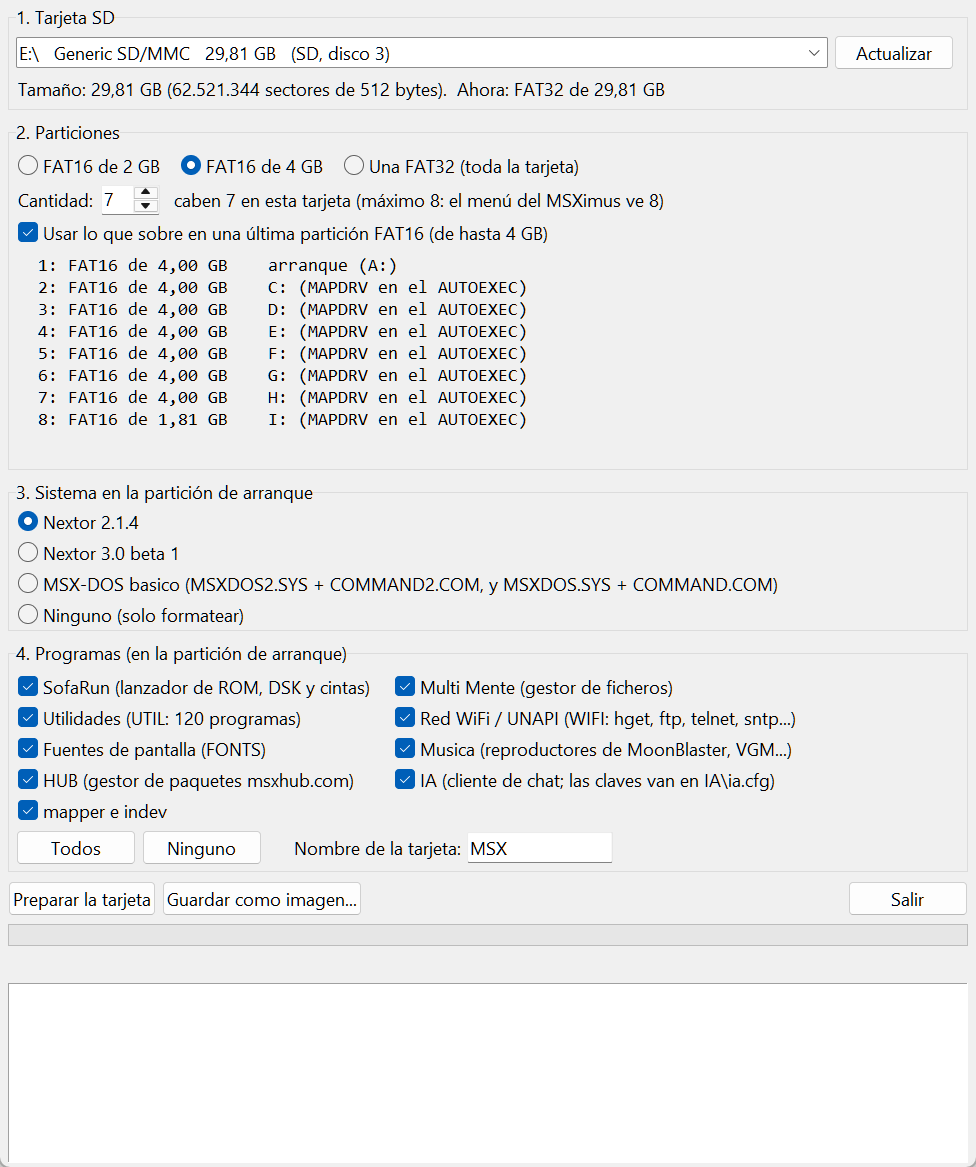
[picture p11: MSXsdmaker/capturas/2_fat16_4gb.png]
FAT16 de 4 GB con el sobrante aprovechado


> ⚠️ **FAT32 y MSX-DOS.** Ni Nextor 2.1.4 ni Nextor 3.0 leen particiones FAT32. Con una tarjeta FAT32 el MSX **no arrancará MSX-DOS** desde ella; saldrá el menú del MSXimus o BASIC. En el MSXimus, además, el menú no descarga del File-Hunter ni guarda la SRAM de los cartuchos en FAT32: solo lanza ROM y DSK. Elígela solo para eso o para la MSX Pico.
>
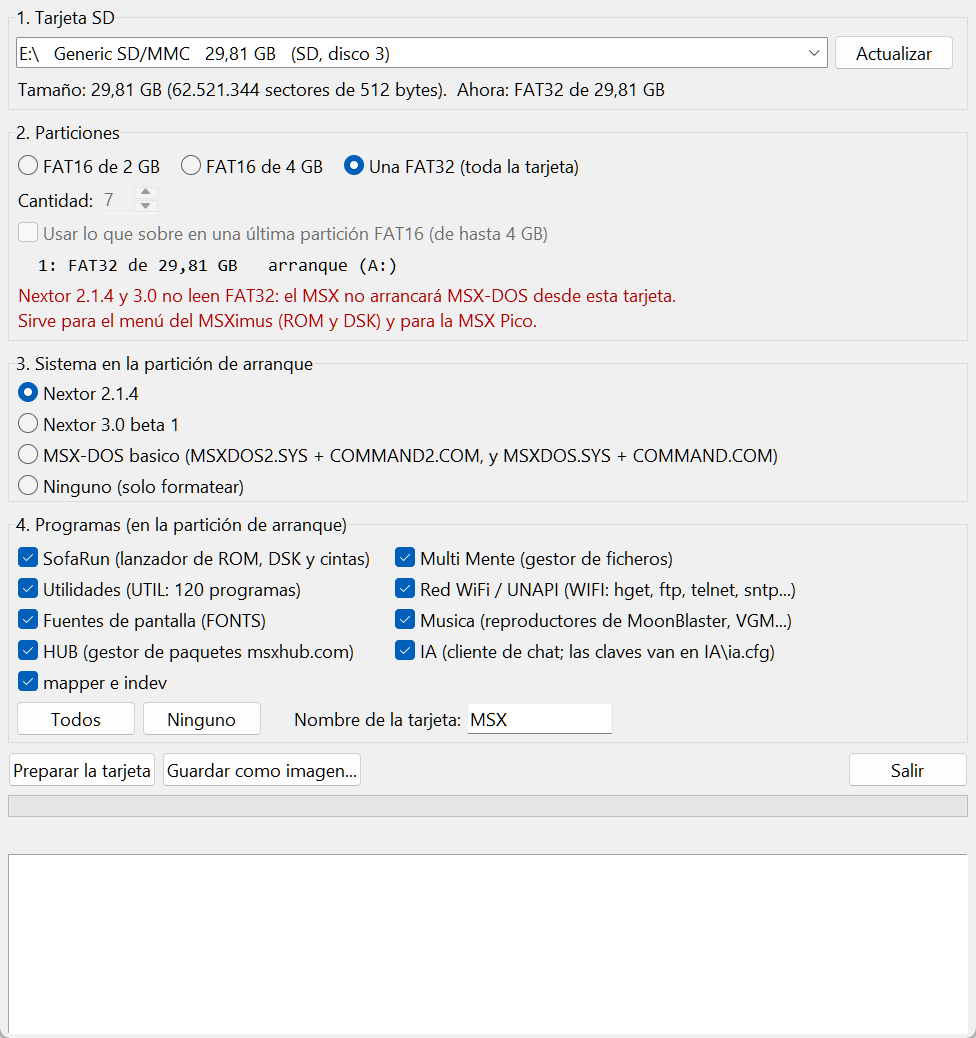
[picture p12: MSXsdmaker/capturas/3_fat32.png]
Aviso de FAT32
> 

### 3.3 El sistema

Es el sistema operativo que se copia en la primera partición, la de arranque. **Tiene que coincidir con el Nextor que lleva tu máquina**: si no, el MSX no llega a MSX-DOS.

| Tu máquina | Si grabaste… | Elige |
|---|---|---|
| MSXimus 60K o 138K | `pack_bios_msximus.bin` o `pack_bios_msximus_en.bin` | **Nextor 2.1.4** |
| MSXimus 60K o 138K | `pack_bios_msximus_nextor3.bin` o `…_en_nextor3.bin` | **Nextor 3.0 beta 2** |
| MSXimus Z (Zynq) | un `BOOT_…_nextor214.bin` | **Nextor 2.1.4** |
| MSXimus Z (Zynq) | un `BOOT_…_nextor3.bin` | **Nextor 3.0 beta 2** |
| MSXnano | `pack_bios_msxnano.bin` o `pack_bios_msxnano_en.bin` | **Nextor 2.1.4** |
| MSXnano | `pack_bios_msxnano_nextor3.bin` o `…_en_nextor3.bin` | **Nextor 3.0 beta 2** |
| Goa'uld | `pack_bios_goauld_es.bin` o `pack_bios_goauld_en.bin` | **Nextor 2.1.4** |
| MSX Pico u otro MSX con Nextor 2.1 | — | **Nextor 2.1.4** |

Las otras dos opciones:

- **MSX-DOS básico**: solo `MSXDOS2.SYS` y `COMMAND2.COM`, más `MSXDOS.SYS` y `COMMAND.COM` de MSX-DOS 1, sin las herramientas de Nextor. Sin ellas el `AUTOEXEC` no puede montar C:, D:…; se hace a mano con `CALL MAPDRV` desde BASIC.
- **Ninguno (solo formatear)**: particiona y formatea, sin sistema ni programas. Útil para una tarjeta solo de juegos.

**Opciones de Nextor 3.** Con Nextor 3 se activa un recuadro con cuatro opciones del arranque:

| Opción | Qué hace | Por defecto |
|---|---|---|
| Barra invertida en vez de ¥ (`YENSLASH ON`) | Las rutas se ven `A:\DIR\FICHERO` y no con el yen de los MSX japoneses. Desde la beta 2, `YENSLASH` es una orden del propio `COMMAND3.COM` | Marcada |
| Modo inserción (`SET BUFINSERT=ON`) | Al escribir una orden, lo que tecleas se inserta en vez de sobrescribir. INS cambia de modo, como siempre | Sin marcar |
| `AUTOEXEC.BTM` en vez de `AUTOEXEC.BAT` | `COMMAND3.COM` lo carga entero, así que admite `GOTO`, `GOSUB`, `RETURN` y `END` | Sin marcar |
| Tamaños en DIR | En K desde 10K (lo de Nextor 3) o siempre en bytes, como MSX-DOS 2 (`SET DIRK=0`). `DIRB` los da siempre en bytes | En K |

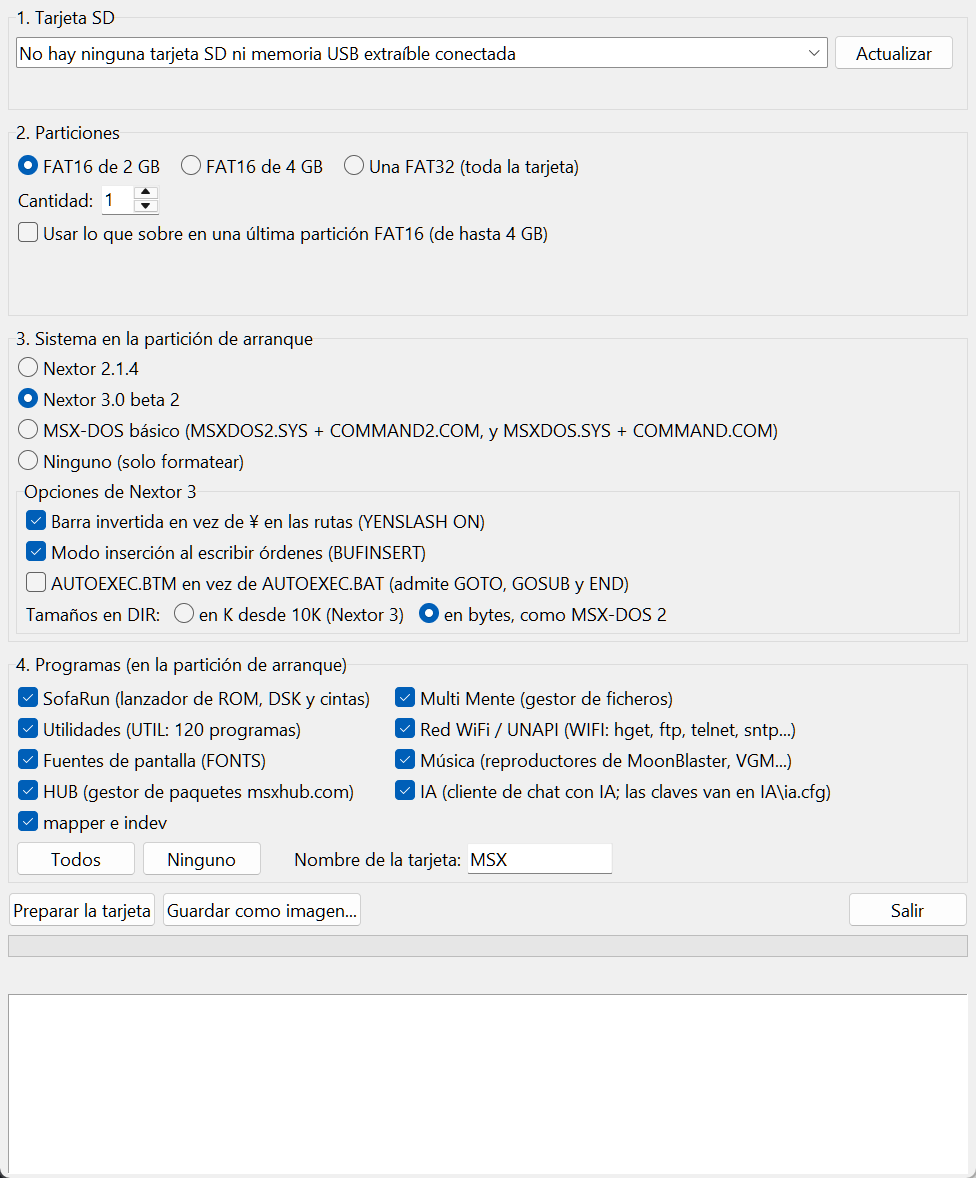
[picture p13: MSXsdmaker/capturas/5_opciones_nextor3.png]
Opciones de Nextor 3


> ℹ️ MSX-DOS 1 solo arranca desde particiones FAT12 de 16 MB o menos, que no son las que crea este programa. Por eso con cualquiera de estas opciones arranca MSX-DOS 2, y los ficheros de MSX-DOS 1 van solo por si los necesitas.

### 3.4 Los programas

Se copian en la primera partición, cada uno en su carpeta. Marca los que quieras; los botones **Todos** y **Ninguno** ayudan.

| Casilla | Carpeta | Qué es | Cómo se abre |
|---|---|---|---|
| SofaRun | `SOFARUN` | Lanzador de ROM, DSK y cintas CAS con menú, de Louthrax | `SR` |
| Multi Mente | `MM` | Gestor de ficheros de dos paneles | `MM` |
| Utilidades | `UTIL` | Unas 120 herramientas: `DI` (DIR con nombres largos), `LOGIN`, reproductores, copias… | por su nombre |
| Red WiFi / UNAPI | `WIFI` | Programas de red TCP/IP: `HGET`, `FTP`, `TELNET`, `SNTP`, `FH` (File-Hunter)… | por su nombre |
| Fuentes de pantalla | `FONTS` | Tipos de letra para Multi Mente (ISO Latin-1, japonés, ruso…) | los usa MM |
| Música | `musica` | Reproductores de MoonBlaster Wave, VGM y más | por su nombre |
| HUB | `hub` | Cliente de MSX Hub, para instalar programas desde internet | `HUBG` o `HUB` |
| IA | `IA` | Cliente de chat con IA; tus claves van en `IA\ia.cfg` | `IA` |
| mapper e indev | `mapper`, `indev.com` | `MAPPER` desactiva el mapeador de MSX-DOS 2 para programas antiguos | por su nombre |
| Herramientas FPGA | `FPGA` | `MXUPDATE`: actualiza el core y el pack del MSXimus 60K/138K y del MSXnano (2.1.1 o posterior) desde MSX-DOS, con un `.UPD` de la tarjeta o por WiFi (`MXUPDATE /N`); por WiFi se pone al día él mismo antes de nada. `MXUPDATE /?` enseña las órdenes. El MSXimus Z (Zynq) se actualiza por su cuenta | `MXUPDATE` |

Siempre que haya sistema se crean también estas carpetas vacías. **No las borres**:

- `FHUNT`: donde el menú del MSXimus guarda lo que descarga del File-Hunter. El menú no puede crear carpetas, así que tiene que existir.
- `TMP`: carpeta temporal de MSX-DOS y de SofaRun.
- `SAVES` y `SETTINGS`, si marcaste SofaRun: sus partidas guardadas y su configuración.

**Nombre de la tarjeta**: es el nombre de la partición 1 que verás en Windows y con `VOL` en MSX-DOS. Las demás se llaman igual con su número detrás: «MSX 2», «MSX 3»…

### 3.5 Preparar

1. Pulsa **Preparar la tarjeta**.
2. El programa te enseña **qué va a borrar** (nombre, tamaño y unidades de la tarjeta) y **qué va a crear**. Léelo con calma. Solo sigue si respondes **Sí**; el botón por defecto es No.
3. La barra avanza mientras trabaja. Tarda unos segundos; con FAT32 en tarjetas grandes, algo más.
4. Al final, **verifica**: vuelve a leer la tabla de particiones y cada fichero copiado, y los compara con lo que quería escribir. Si todo cuadra, dice **«La tarjeta está lista y verificada»**.
5. Windows vuelve a montar la tarjeta solo. Cada partición aparece con su propia letra de unidad.

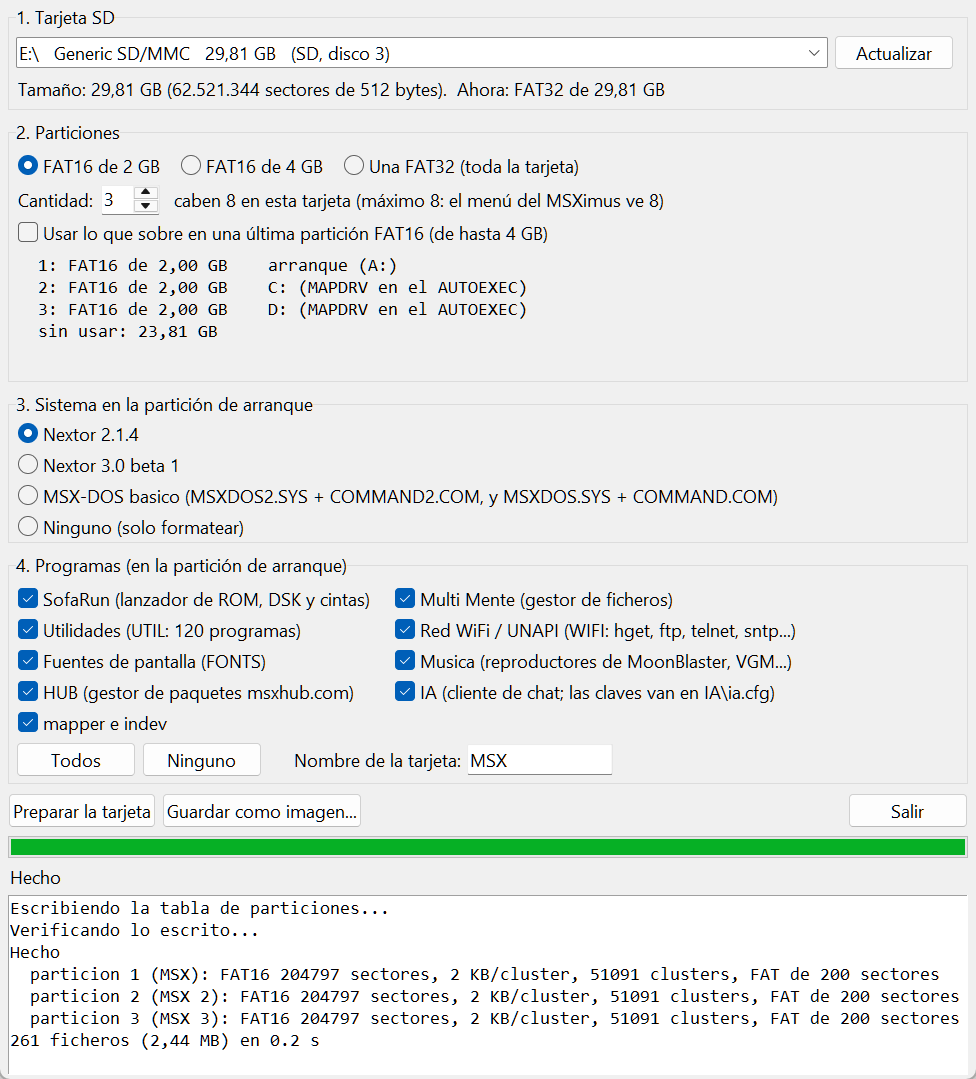
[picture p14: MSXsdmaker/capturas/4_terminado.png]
Tarjeta terminada


Ya puedes sacar la tarjeta. Usa «Expulsar» en Windows antes de quitarla, como con cualquier memoria.

---

## 4. Qué queda en la tarjeta

La **partición 1** (A: en el MSX), con Nextor 2.1.4 y todos los programas:

```
A:\
├── NEXTOR.SYS, COMMAND2.COM       el sistema (con Nextor 3: COMMAND3.COM)
├── MSXDOS2.SYS, MSXDOS.SYS…       sistema de respaldo
├── AUTOEXEC.BAT                   se ejecuta al arrancar (ver abajo)
├── bin\                           herramientas de Nextor: MAPDRV, DRIVERS, DEVINFO…
├── SOFARUN\  SAVES\  SETTINGS\    SofaRun y lo suyo
├── MM\  FONTS\                    Multi Mente y sus fuentes
├── UTIL\  WIFI\  musica\          utilidades, red y música
├── hub\  IA\  mapper\  indev.com
├── FPGA\                          MXUPDATE: actualizar el core del MSXimus y del MSXnano
├── FHUNT\                         descargas del File-Hunter (no borrar)
└── TMP\                           temporal (no borrar)
```

Las **particiones 2, 3…** quedan vacías para tus juegos y programas.
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

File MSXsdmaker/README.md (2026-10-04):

# MSX SD Maker 1.3 — preparing the SD card

*[Versión en castellano](LEEME.md)*

**MSX SD Maker** gets an SD card ready for an **MSXimus** (Tang Console 60K, Tang Mega 138K or the Zynq version), an **MSXnano** or an **MSX Pico**. In a few seconds it does all this:

1. Wipes the card and splits it into partitions that MSX-DOS understands.
2. Formats each partition.
3. Copies the operating system (Nextor or MSX-DOS) to the first partition.
4. Copies a set of programs: SofaRun, Multi Mente, utilities, networking, music…
5. Writes an `AUTOEXEC.BAT` that sets everything up at boot.
6. Reads everything back to check that the card came out right.

Nothing to install: it is a single file, `MSXsdmaker.exe`. The program itself is in Spanish; this guide explains every option.

---

## Contents

1. [What you need](#1-what-you-need)
2. [Opening the program](#2-opening-the-program)
3. [Step by step](#3-step-by-step)
4. [What ends up on the card](#4-what-ends-up-on-the-card)
5. [First boot on the MSX](#5-first-boot-on-the-msx)
6. [Adding games and programs](#6-adding-games-and-programs)
7. [Saving an image instead of a card](#7-saving-an-image-instead-of-a-card)
8. [Troubleshooting](#8-troubleshooting)
9. [For the curious: how it works](#9-for-the-curious-how-it-works)
10. [Licenses and credits](#10-licenses-and-credits)

---
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

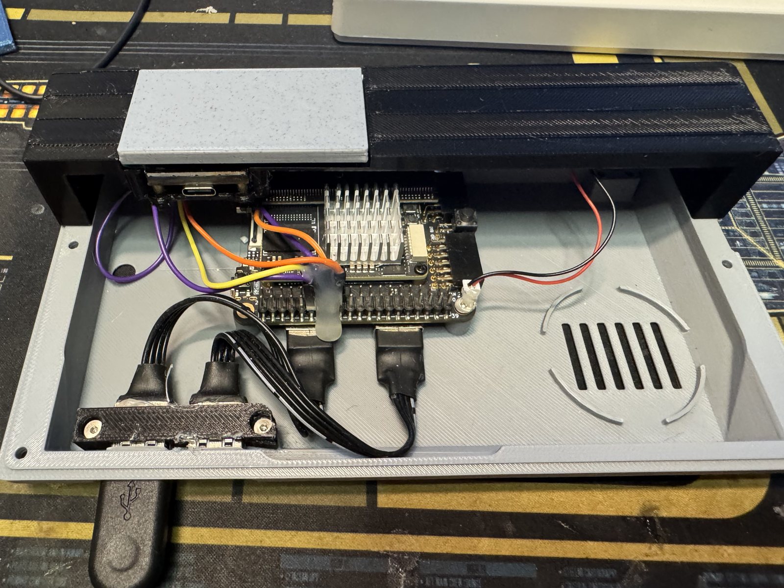
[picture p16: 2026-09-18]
docs/img/carcasa/carcasa_abierta.jpg

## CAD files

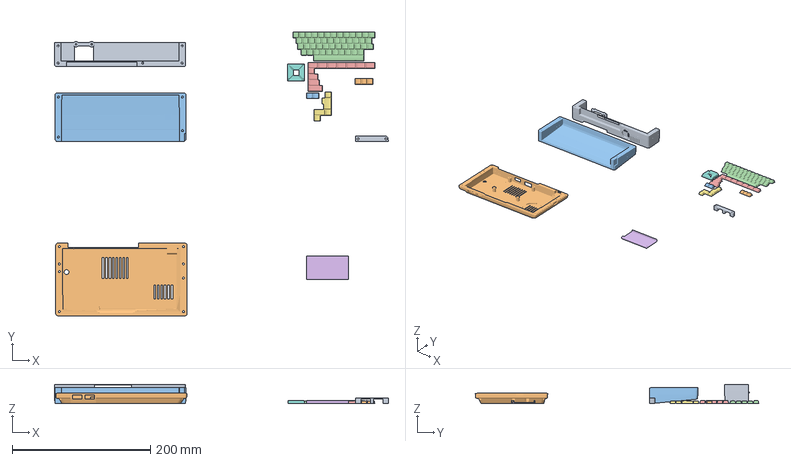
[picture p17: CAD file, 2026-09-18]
carcasa/MSXimus_carcasa.3mf
483.5 x 410.5 x 27.7 mm
zona pantalla.stl
placa inferior.stl
tapacartucho.stl
key_5_light_grey_x1.stl
key_1_dark_grey_x1.stl
tapateclado.stl
key_3_dark_grey_x1.stl
cursor_dark_grey_x1.stl
usb_conector_clamp_x1.stl
key_4_dark_grey_x1.stl
key_2_dark_grey_x1.stl

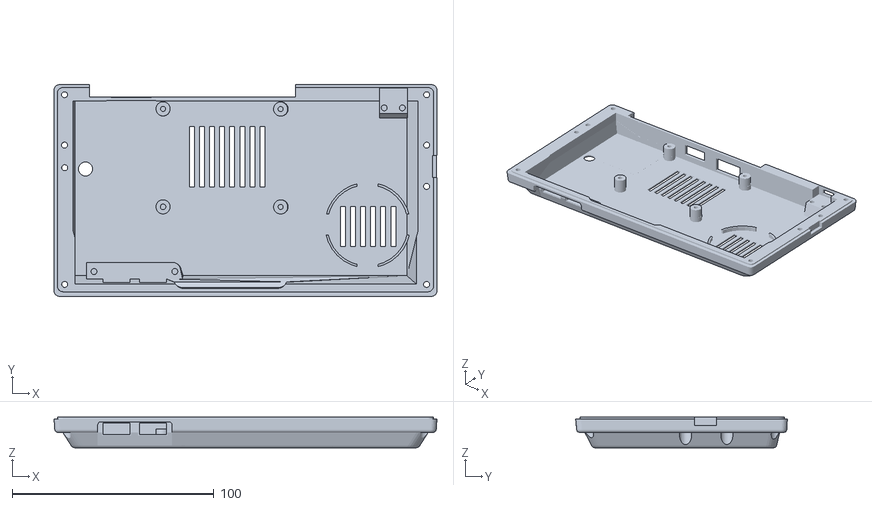
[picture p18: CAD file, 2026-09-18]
carcasa/stl/placa_inferior.stl
190.0 x 105.1 x 15.2

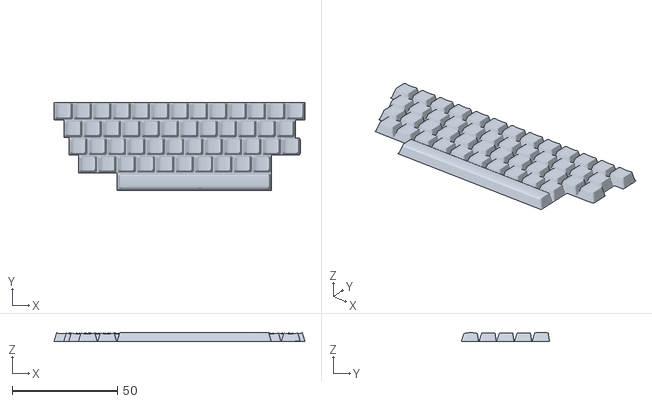
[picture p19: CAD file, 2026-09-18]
carcasa/stl/key_5_light_grey_x1.stl
119.0 x 41.8 x 4.11

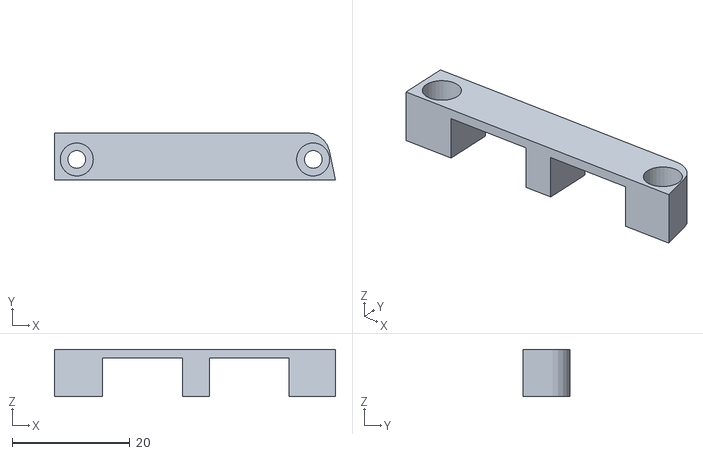
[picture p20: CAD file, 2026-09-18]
carcasa/stl/usb_conector_clamp_x1.stl
47.6 x 8.00 x 8.00

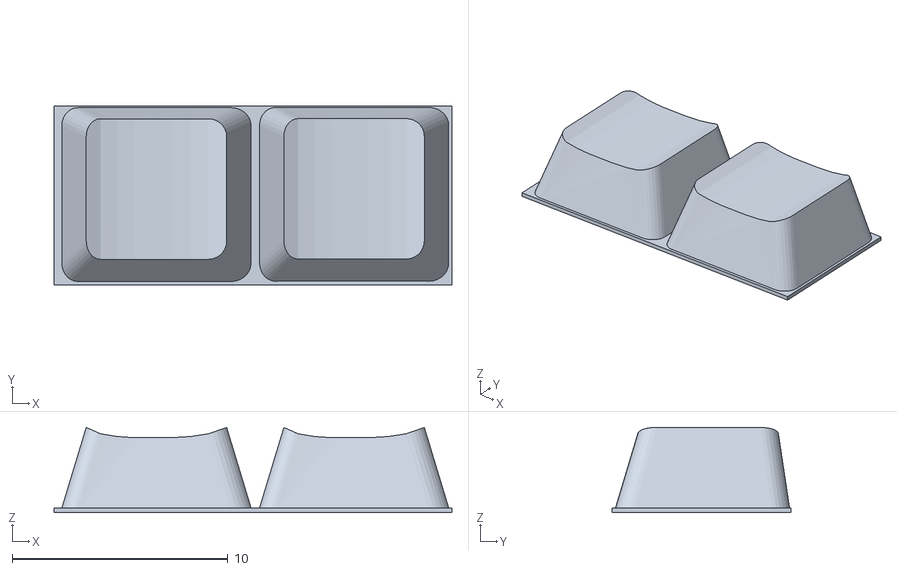
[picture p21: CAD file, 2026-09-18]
carcasa/stl/key_2_dark_grey_x1.stl
18.5 x 8.30 x 3.95

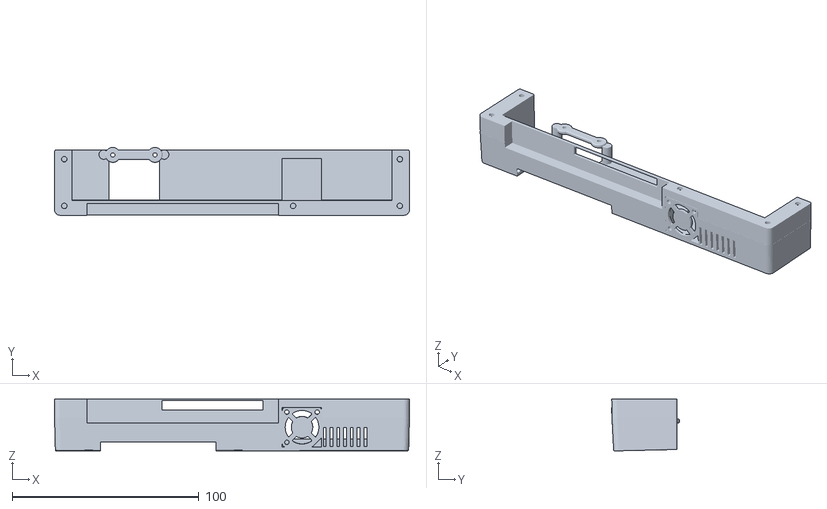
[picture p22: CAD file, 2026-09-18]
carcasa/stl/zona_pantalla.stl
190.0 x 36.5 x 27.7

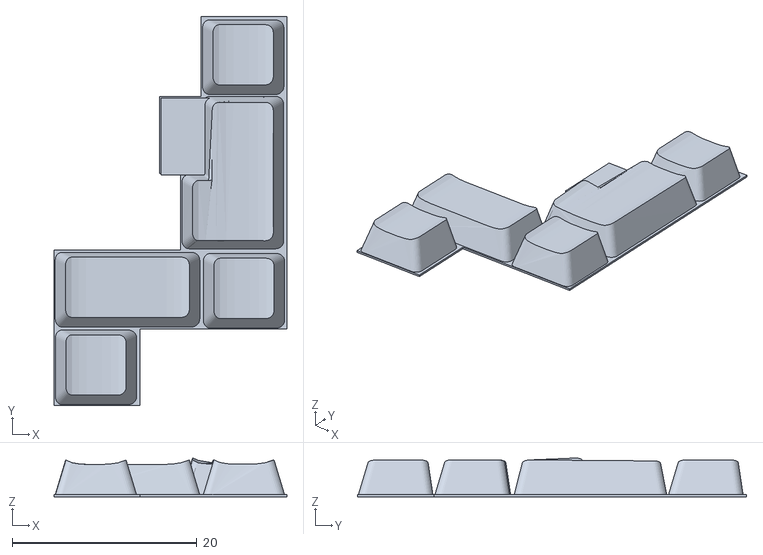
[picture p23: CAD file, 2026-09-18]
carcasa/stl/key_3_dark_grey_x1.stl
25.2 x 42.1 x 4.21

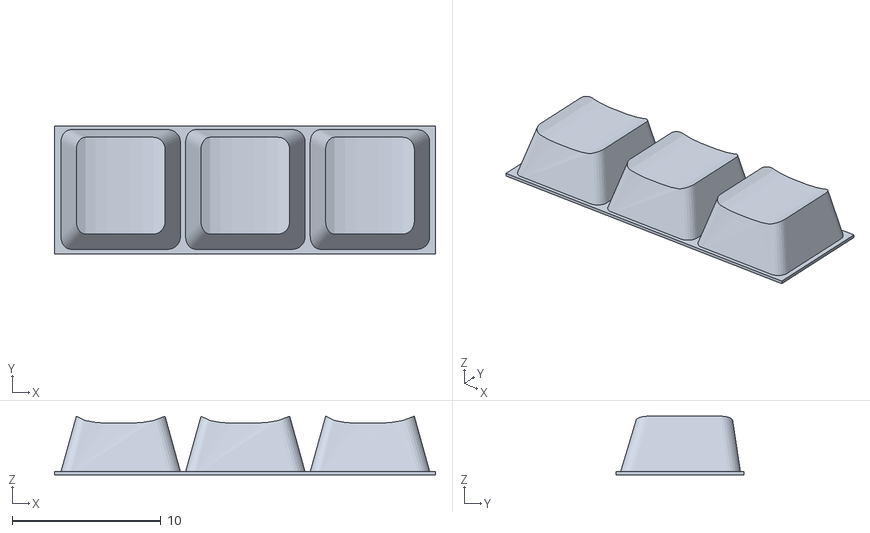
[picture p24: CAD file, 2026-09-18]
carcasa/stl/key_4_dark_grey_x1.stl
25.7 x 8.60 x 3.95

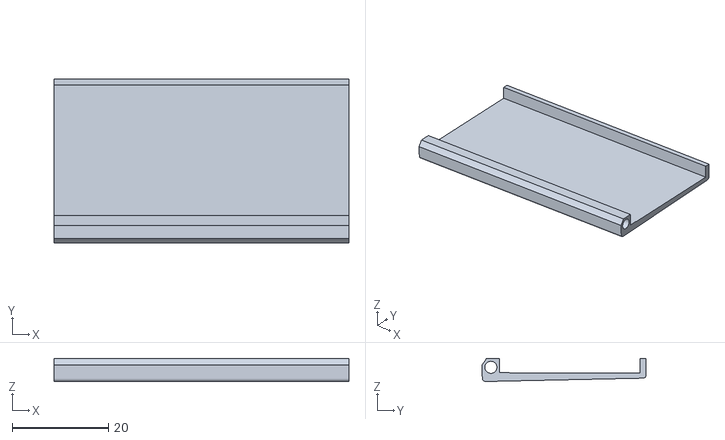
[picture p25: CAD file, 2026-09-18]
carcasa/stl/tapateclado.stl
61.2 x 34.1 x 4.77

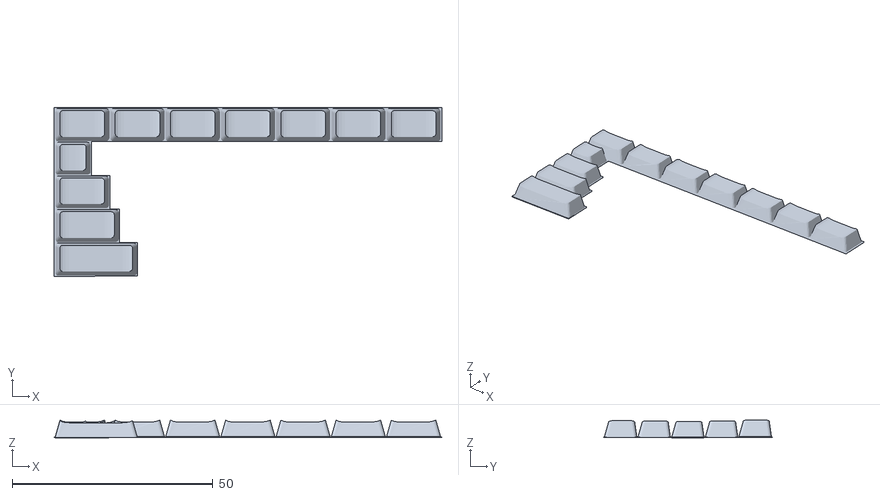
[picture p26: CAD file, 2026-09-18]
carcasa/stl/key_1_dark_grey_x1.stl
96.7 x 42.0 x 4.45

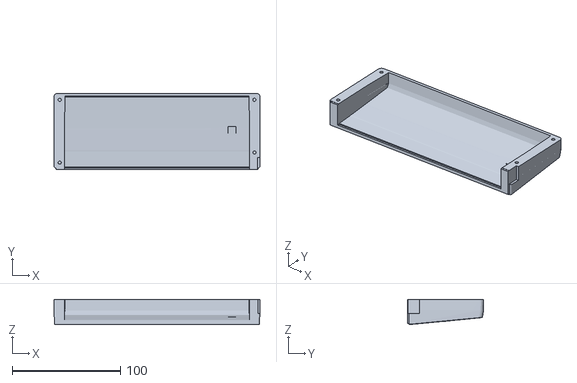
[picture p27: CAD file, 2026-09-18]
carcasa/stl/tapacartucho.stl
190.0 x 70.3 x 23.1

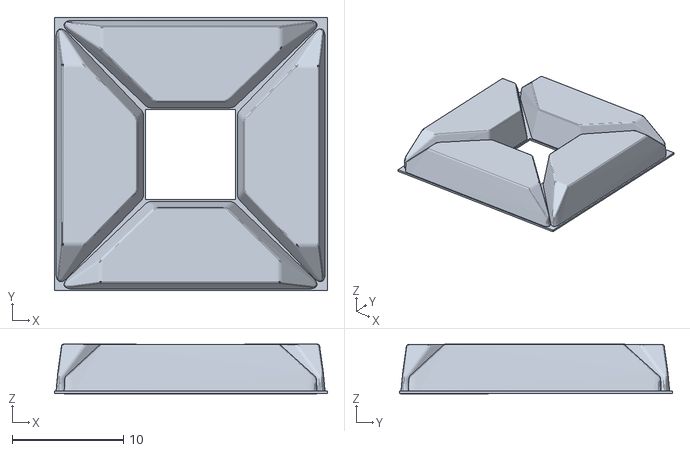
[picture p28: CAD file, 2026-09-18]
carcasa/stl/cursor_dark_grey_x1.stl
24.5 x 24.5 x 4.47

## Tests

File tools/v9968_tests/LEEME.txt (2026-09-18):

Tests del V9968 para la SD (MSX-DOS) — suite oficial de HRA!
=============================================================

33 programas .COM del propio autor del V9968 (Takayuki Hara / HRA!),
tal cual los publica en hra1129/V9968_Cartridge (los mismos con los que
valida SU cartucho -> comparabilidad directa con su hardware).

Copyright (C) 2025-2026 Takayuki Hara. Redistribuidos conservando su
aviso segun su licencia (BSD-like, uso no comercial) — compatible con
la publicacion gratuita del MSXimus.

COPIA ESTA CARPETA A LA SD y ejecuta desde MSX-DOS cuando el V9968
este integrado (primer build F1). ORDEN RECOMENDADO:

  1. CHKVDP.COM     — deteccion: debe identificar el VDP (V9958 por
                      FakeID / V9968 con ID real S#1)
  2. SC0TEST/SC0WTEST/SC1TEST/SC2TEST/SC3TEST/SC4TEST — modos basicos
  3. SC5TEST/SC6TEST/SC7TEST/SC8TEST — modos bitmap (nuestro tablero
                      de sim era SC5: referencia visual conocida)
  4. SC1INTR/SC1INTR2 — interrupciones (H-int/V-int)
  5. PALTEST        — paleta
  6. SP1TEST/SP2TEST/SP2TEST2/SP3TEST — sprites (SP3 = modo NUEVO
                      del V9968, solo con R#20 activado)
  7. SC5HMMC/SC5LINE/SC5LMCM/SC5LMMC/SC5YMMM/SC8HMMV — comandos VDP
  8. SC5ROT/SC5SRCH — comandos NUEVOS del V9968 (LRMM/SRCH)
  9. V9968DM.COM    — la demo oficial (el gran final)

Con fallos: apuntar CUAL test y QUE se ve — cada uno aisla un
subsistema, asi que el nombre del test que falla ya localiza el area.

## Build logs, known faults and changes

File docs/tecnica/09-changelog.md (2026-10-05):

# 09. Changelog

Versión a versión, qué cambió, qué dado se entregó y con qué hashes. La primera parte es la **línea 138K**, la del porte que vive en este repositorio; la segunda es el historial de la era v3 del MSXimus en la Tang Console 60K, del que deriva el core y del que el 138 hereda cada cambio por merge. Sale de los LEEME de cada entrega en `files/<fecha>/`, que quedan fuera de git (los del 138 en este repo, los del 60K en `MSX_up_v3`), y de las notas de `mi_release/`.

Los hashes son md5, los ocho primeros dígitos salvo donde se indica. El "dado" es el número primo con que se sembró el place and route ([capítulo 07](07-sintesis-campanas.md)); el margen es el peor setup del informe de temporización. En el 138 el `clk_86` del V9968 está sobre-restringido a 11,30 ns en `msx_v9968.sdc` (el periodo real es 11,64), así que un margen "contra 11,30" lleva unos 0,34 ns escondidos: se indica cuál es el real.

## Línea 138K

El MSXimus_138 es el MSXimus portado a la Tang Console 138K: la misma placa base (dock con HDMI, SD, dos USB-A, PMOD, BL616, ESP32-C6 y el módulo SDRAM W9825 de 32 MB) con el SOM Tang Mega 138K (GW5AST-LV138PG484A: 138.240 LUT, 340 BSRAM, 12 PLL, 298 DSP, 1 GB de DDR3, flash SPI de 16 MB) en vez del Mega 60K. Menú, tarjeta, mappers, audio, V9968, packs y puertos son los del 60K; lo que cambia está en el [capítulo 01](01-arquitectura.md) y en el `README.138.md`. Las versiones del porte se numeraron aparte (v1, v2) hasta la v3.7, que toma el número del 60K porque es la V3.7b traída entera por merge. Gowin EDA 1.9.12.03 edición Standard con licencia (la Education no soporta el 138K).

**Nada de esta línea ha corrido nunca en una placa 138K**: la placa era prestada, la v1 y la v2 se entregaron sin validar y la v3.7 está en campaña. Lo que hay es síntesis limpia, gate pasado y los bancos de simulación del 60K. Todo lo que en el historial del 60K de más abajo es "validado en placa" aquí es "compilado y verificado en simulación, pendiente de placa"; no se repite en cada entrada.

Lo que cuesta un dado en el 138: CLS ~57 % (el 60K va al 98 %), PnR 15-19 min desde la v3.7 (7 min en la v1), BSRAM 116/340, bitstream de 4,88 MB (el del 60K, 2,47). No hay problema de área ni de rutado: el listón es el dominio de 86 MHz del V9968 y su shim, que cierra alrededor de 1 de cada 3 dados. Campañas de 3 dados (`p138a`..`p138j`), con el gate del 60K (setup ≥ 0, holds solo en la IP DDR3) contra el `clk_86` sobre-restringido.

### v1 (7 de septiembre de 2026, interna): el porte

Es la **V3.5d del 60K** (rama `V3.5`, commit `dd8d8ff`, más los cambios de la v3.5d) compilada para el GW5AST-138B. Lo que hubo que tocar para que compilara y cerrara:

- **Dispositivo** `GW5AST-138B GW5AST-LV138PG484AC1/I0` en `build.tcl`. Los chips fabricados desde julio de 2025 son versión C y Gowin pide `GW5AST-138C`: hay que mirar la serigrafía del SOM; las entregas dicen con qué versión se compilaron.
- **Pines**: `msx_console138k.cst/.sdc`, copia 1:1 de los del 60K (el SOM Mega 138K saca a la placa base las mismas bolas, dock y DDR3 incluidos; verificado contra los cst de nand2mario para la Console 138K) con tres retoques que el chip exigió: `IO_TYPE` de la DDR3 a `SSTL15`/`SSTL15D` (el 138 rechaza el sufijo `_I`), `s1`/`s2`/`fan_en_o` a `LVCMOS33` (en el 138 caen en el banco 5, que va a 3,3 V) y fuera las `INS_LOC` del DLL/PLL de la DDR3 del 60K. Sin contrastar contra el esquemático: `sd_*`, `spi_irqn`, `s2`, `fan_en_o`, `esp_*`.
- **PLL + PLL_INIT en cascada** (`fpga/pll138/`): el GW5AST no tiene `PLLA` (error RP0008) y su `PLL` tiene dos límites nuevos, VCO 650-1300 MHz y frecuencia de comparación 19-81,25 MHz, con los que desde el pad de 50 MHz no salen 108/54/27 ni 371,25 exactos. `pll_27` (50/2 ×27, VCO 675) da 27,000 exactos; de ahí `pll_main` (×40, VCO 1080: 108, 54, 27, 135 y **36 MHz para el motor del OPL4**, que ya no puede ser 37,5; CE de 44,1 kHz = 14112/15000), `pll_86` (VCO 945: 85,9) y `pll_ddr3` (VCO 891: 297 para la DDR3 y `CLKOUT1` = 74,25 sin gatear, del que cuelga `pll_74` ×10 con 74,25 y 371,25 para el HDMI). Sin mDRP: el `pll_stop` de la IP DDR3 va directo a `ENCLK2` del PLL, donde en el 60K estaba la danza mDRP con `pll_mDRP_intf`.
- **La salida del OPLL (jt2413) se registra en `clk_27m`** antes del mezclador (`jt2413_wav_r27`): el árbol de sumas de 22 ns de `opll/u_acc` (54) a `snd_mix` (27), que en el 60K cabía por poco en la relación 54→27, aquí daba −4,3 ns en todos los dados.
- **Mapa de flash +4 MB**: el bitstream del 138 se comía el pack en 0x400000. Pack en **0x800000**, bloque de configuración en **0x880000**, YRW801 del OPL4 en **0x900000** (tres `localparam` en `top.v`). Los packs son los mismos ficheros que en el 60K; solo cambia la dirección donde se graban.

Campañas: `p138a` (RP0008, no hay PLLA), `p138b`/`p138c` (constraints: IO_TYPE, INS_LOC, banco 5), `p138d` (gate OK pero con el VCO fuera de rango: no se entrega; de aquí salen el CLS del 57 %, el BSRAM 116/340 y los 7 min de PnR), `p138e` (PA2078: dividir el pad de 50 por 5 se sale del PFD), `p138f` (cascada de PLL, cero avisos, pero los dados rechazados por el OPLL a −4,3 ns), `p138g` (OPLL registrado; 3359/3361/3371 pasan los tres el gate, con 0,013-0,029 ns en el shim del V9968: el rutador cumple el periodo y para; el 3361 se entregó un primer momento y hoy está en `superados/`), `p138h` (`clk_86` sobre-restringido a 11,30 ns; 3389 gate OK con 0,07 ns contra 11,30, ~0,41 reales; 3373 con 0,014, ~0,35 reales; 3391 rechazado con −0,475, ni el periodo real). La sobre-restricción se queda en el sdc. En el 3389 el STA marca el fMax de `clk_54m` como FAIL sin ningún camino negativo: el artefacto conocido de Gowin.

| | |
|---|---|
| Core | `msximus138_v1_dado3389.fs` eba70f2b (`_jtag.bin` d6f4e217), ~0,41 ns reales en `clk_86`, cero holds, compilado como 138B. Respaldo 3373: f60fea96 / b7dd7492 |
| Packs | los del 60K de la misma fecha, en 0x800000 |
| BL616 | pendiente: el firmware del 60K no se ha compilado para la 138K; la Console 138K trae el partner firmware de Sipeed |

Entrega en `files/20260907/`, con el plan de pruebas en placa en `LEEME_138_v1.txt`.

### v2 (8 de septiembre de 2026, entregada el 9; interna): Game Master 2

La v1 más el bloque 6 de la **v3.5f del 60K**, portado tal cual: mismo `gm2_slot1.v`, mismos enganches en `top.v`, mismo puerto 46h (bits 6 y 7), misma memoria en los segmentos 480-496 de la megaram (ROM en 480-495, SRAM en el 496); como el pack es común, el menú es el mismo. Commit cc719a5.

Campaña `p138i` (3463/3467/3469), con `clk_86` a 11,30 ns: 3469 gate OK con 0,006 ns contra 11,30 (~0,35 reales); 3463 rechazado (−0,699, es decir −0,36 reales); 3467 rechazado (−0,992, −0,65 reales, y además −0,94 en `clk_54m`, `cpu RD → cpu_din`). Uno de tres, como en la `p138h`. El GM2 no aparece en ninguna lista de caminos.

Core: dado 3469, `msximus138_v2_gm2_dado3469.fs` d5a7a485 (`_jtag.bin` 400c6e02); sin respaldo. Packs regenerados con el menú del GM2 (2.1.4 c2c16cd8, Nextor 3 d763ec36), los mismos ficheros del 60K. Entrega en `files/20260909/`; el porte quedó aparcado ese mismo día.

### v3.7 (18 de septiembre de 2026, en campaña): la V3.7b del 60K por merge

Retomado el 18 de septiembre: **todo lo que el 60K hizo entre la v3.5f y la v3.7b entra de una vez**, por merge y no por copia. El 138 no compartía historia con `MSX_up_v3` (su base d4b9343 era un squash), así que se injertó con `git replace --graft d4b9343 1306d86` (la V3.5d del 60K, el commit más cercano) y se fusionó la rama `V3.5` (ad38c1f). Cuatro conflictos: `.gitignore`, `build.tcl` (`add_file sd_dma.sv`), `sd_tb/run.sh` y el PLL del backend DDR3, donde se conserva la instanciación del 138 (`init_clk`/`enclk`) y entra el `.reset(~pll27_lock | wd_pll_rst)` del 60K. `top.v` se fusionó solo conservando el mapa de flash, `jt2413_wav_r27` e `init_clk`. Commit 268d99a. Desde aquí la historia del 60K está dentro del repo y los siguientes portes son `git fetch ../MSX_up_v3 V3.5 && git merge`.

Lo que trae, con el detalle en el historial del 60K de abajo:

- **DMA de lectura de la SD** (v3.6 y v3.6c): a la RAM sin pasar por el Z80, modo lógico por los registros del mapper, contadores de patrones y el driver de Nextor leyendo por DMA.
- **Mandos HID por los USB-A** (v3.6f) y los dos arreglos de la v3.6e (cruceta y relectura del registro 15 del PSG).
- **El MSX espera a la DDR3** y el LED de la SD (U12) parpadea mientras no calibra (v3.6g, dentro de la v3.6h).
- **Generación C del V9968** (v3.6h): R#20/R#21 bloqueados por el bit 7 del puerto #4 (9Ch/8Ch) y máscara del A17.
- **Mezclador de audio por fuente** (v3.7): puerto 44h extendido, persistencia de 11 bytes en el bloque de configuración (aquí en **0x880000**), `config_init` arreglado, `cpu_run` registrado y resincronizado a 108 MHz.
- **Motor de reintentos escalonado de la DDR3 y puertos 2Ah-2Ch** (v3.7b), con la espera del arranque en 10 s. La VRAM vive en la misma IP con el mismo backend, así que la lotería de calibración por dado que se ve en el 60K es igual de aplicable aquí (pendiente de verificar en placa).
- El puerto 2Fh dice **37h**, como en el 60K. Packs: los de la V3.7 del 60K (bios 6db0cf8: 2.1.4 fb9b6c38, Nextor 3 10321483), obligatorios para ver la página del mezclador, grabados en 0x800000.

Síntesis limpia para GW5AST-138B (LUT 38.468). El banco del backend DDR3 (`tb_ddr3_backend.sv`) lleva el stub del PLL del 138 (`init_clk`, `enclk0`, `enclk2`, `clkout1`) y pasa entero, incluida la secuencia de 18 intentos fallidos de la v3.7b; `run_ddr3_backend.sh` apunta a este repo.

Core: dado **4391**, adf693b5, campaña `p138k`. Margen 0,034 ns contra los 11,30 ns del `clk_86` sobre-restringido, es decir, ~0,37 ns reales (la misma clase que el 3389 de la v1 y el 3469 de la v2); holds solo la IP DDR3. Campaña `p138j` (4339/4349/4357): 0 de 3 (dos por el dominio de 86 MHz, −1,12 y −0,76 contra 11,30; el 4357 cerraba el 86 pero colocó la CPU lejos de la SDRAM, `cpu1/DO → mem1/SdrDat` a −4,5 ns). Campaña `p138k` (4363/4373/4391/4397/4409): 1 de 5 (4373 se quedó a −0,05 en `cpu1/IORQ`; 4363, 4397 y 4409 por `ff_flash_state`, `cpu1/DO` y el 86). Con el diseño de la v3.7 el PnR del 138 pasa de 7 a 15-19 minutos por dado. Entrega en `files/20260918/` con `LEEME_138_v3.7.txt`. Sin validar en placa.

### OPL4: la relectura de los registros de slot (5 de octubre de 2026; en la rama `V3.8`, sin core nuevo)

Arreglo de un defecto visto en simulación, traído de la Zynq y del 60K el mismo día (el detalle, en el historial del 60K de su repositorio). Al leer por 7Fh un registro de slot del wavetable, la primera lectura devolvía a menudo el valor del registro leído justo antes, también respetando /WAIT. La causa estaba en el motor (`fpga/opl4wave/YMF278B.sv`): `REG_Q` se cargaba antes de que la BSRAM de los registros hubiese entregado el dato y la corrección llegaba cuando `opl4_pcm.v` ya había capturado. Ahora se carga en el mismo CE con el dato de esa lectura; `opl4_pcm.v` no cambia y /WAIT dura lo mismo. Las escrituras y el sonido no cambian.

- `YMF278B.sv` y `ymf278b_gowin.v` son los mismos ficheros que en el 60K y la Zynq.
- Banco `tools/opl4wave_sim/tb_slotrd.v` (`run_slotrd.sh`), aquí con el motor a **36 MHz** (CE 14112/15000): con el motor de antes, entre 1.270 y 1.340 de 4.200 lecturas únicas distintas de lo escrito por semilla; con el arreglo, 0 en las tres. /WAIT en un IN 7Fh: 343 ns de mínimo y 376 de media desde que el Z80 baja RD, igual antes que después.
- `run_sim.sh` y `tb_regrd.sv` en verde, y los ocho volcados de PCM de `run_pitch.sh` y `run_pan.sh` bit a bit iguales antes y después. `run_pan.sh` deja de apuntar a la carpeta `MSX_up`.
- Síntesis limpia para GW5AST-138B (LUT 40.296, BSRAM 104; el bloque `uopl4pcm` con sus 8 BSRAM). Sin campaña: como el resto de la línea, nada de esto ha corrido en una placa.

## Historial del 60K (del que deriva el core)

Lo que sigue es el changelog de la era v3 del MSXimus en la Tang Console 60K, tal cual, porque cada cambio del core es también un cambio del 138. Pero los **dados, hashes, márgenes y cifras de placa son del 60K**: las velocidades de la SD, las calibraciones de la DDR3, los negros desde el cargador, las validaciones en placa y las noches de campañas al 98 % de CLS no se han reproducido en el 138, cuyos dados están arriba. Las rutas `files/<fecha>/` y `mi_release/` de esta parte son del repo `MSX_up_v3`, y las direcciones de flash que cita (0x400000, 0x480000) son las del 60K: en el 138 están 4 MB más arriba. Las versiones publicadas en GitHub llevan tag; las intermedias son entregas internas probadas en la placa 60K.

## v3.1 (26 de agosto de 2026, publicada, tag `v3.1.0`)

La versión que da nombre a la era: **el core reconstruido sin el SSRAM de la GW5AT-60B**, que Gowin retiró por un problema de silicio. Todas las memorias que vivían ahí pasaron a BSRAM o a registros, lo que obligó a rehacer por dentro el motor de ondas del OPL4, los registros del OPL3 y la caché PCM.

- Panel de estado en **F12** por el BL616 de la placa, con el MSX congelado debajo.
- Identificación como **turbo R**: registros del S1990 en E4-E7 y CHGCPU mueve el turbo. Sin R800.
- **Ratón MSX** desde un ratón USB con cable.
- Dos BIOS a elegir: la plana y la del navegador de la SD.
- El turbo pasa a **F11**.

| | |
|---|---|
| Core | `MSXimus_v3.1.fs` 2cbf1690, margen 0,607 ns. Respaldo 4655e7bf (0,473 ns), no publicado |
| Packs | bios-MSX 0d82f357, bios-Menu 28cb2a7b |
| BL616 | `bl616_v3.1.bin` af5a4f79 en 0x40000, con el de Sipeed 4dbe9bb1 en 0x0 |
| C6 | `firmware_esp32c6_unapi_merged.bin` 8acd1918, el mismo de la v2.1.2 |

## v3.2 (4 de septiembre de 2026, publicada, tag `v3.2`)

**El core no cambia**: es el mismo `.fs` de la v3.1. Cambia todo lo de encima.

- **Una sola BIOS**: el navegador es un ajuste, *Menú al arrancar*, guardado en la flash.
- **Descargas desde el menú**: tecla F, File-Hunter, ROMs y discos directos a la tarjeta.
- Logo MSX animado en la pantalla del C6.
- El firmware del C6 pasa a su propio repositorio, `ESP32-for-FPGA`, el mismo binario para el MSXimus y el MSXnano.

## v3.5a (5 de septiembre, interna)

Primera build del **plan 3.5**: la SD y los mappers.

- El controlador de la SD, arreglado de raíz: el token de estado de la escritura nunca se evaluaba y el host daba por escrito un sector que la tarjeta aún estaba programando. Ahora se lee el token y se espera el busy. Reloj de la tarjeta a 6,75 MHz (era 2,25). CRC16 de lectura comprobado, con reintento. CMD12 acotado.
- **Megaram de 4 MB** (era 2): el mapper de RAM se recorta a 2 MB y la megaram se queda con su hueco. ASCII16 recupera el bit 7 del registro; **NEO-8 y NEO-16** nuevos. Puerto 46h.
- Banco de 33.047 operaciones aleatorias contra la megaram de la v3.1 como oráculo.

Core: dado 3001, c3e350b0, margen 1,084 ns. Respaldo 3019. BSRAM al 118/118: desde aquí no queda ninguna.

## v3.5b (6 de septiembre, interna)

- **El menú pasa a ROM de 32 KB**: la segunda página va donde estaba el driver kanji, que desaparece del MSXimus. Ya no se descomprime en RAM.
- **SRAM de cartucho persistente** en la tarjeta: ficheros `.SRM` en `FHUNT`, guardado al siguiente arranque tras reset (bloque 5 del plan).

Core: dado 3041, 508f8330, margen 1,084 ns; respaldo 3083 (0,904 ns). Ocho dados en una noche para sacar dos buenos. Core y pack van en pareja: un core anterior con este pack no arranca el menú.

## v3.5c (6 de septiembre, interna)

- **La SD por puertos de E/S**: los registros del controlador en 47h-4Fh del dispositivo 48h, además de la ventana de memoria, que sigue igual. INIR en vez de LDIR.
- **Multibloque** CMD18 y CMD25 con un solo búfer: el core para el reloj de la tarjeta entre bloques.
- Driver de Nextor nuevo, común a 2.1.4 y 3, que sondea el core y usa lo que hay. Ninguna combinación de core y pack deja de arrancar desde aquí.

Core: dado 3169, eece0162, margen 0,481 ns; respaldo 3109 (0,419 ns). Velocidades en placa: 90, 104 y 112 KB/s por ventana, puertos y multibloque.

## v3.5d (6 y 7 de septiembre, interna)

- **Cronómetro de milisegundos** en el core, por el índice 25-27 de 4Eh: el menú medía la carga con el contador de la BIOS, que se para con las interrupciones inhibidas, y daba cifras imposibles.
- **Menú de pruebas** con la tecla T: velocidad de la SD por sus caminos, sonido, configuración.
- Todas las salidas del módulo de puertos de la SD pasan a registradas: la lógica combinacional colgada de IORQ_n y WR_n se llevó por delante tres campañas (0,171 ns, -1,55 ns, -0,791 ns).
- Una carrera metida al registrar la orden por ventana rompió la carga de ROMs en el dado 3257, que se retiró; el 3319 la lleva arreglada.

Core: dado 3319, de39e213, margen 1,309 ns, el mejor de la serie. Seis campañas y dieciocho dados en una noche: el mismo RTL dio desde 1,19 ns hasta -0,18 según el dado. Es el punto del que salió la v1 del 138.

## v3.5e (8 de septiembre, pack de diagnóstico)

Solo el pack: la tecla T también desde el navegador, no solo en el logo. El core sigue el 3319.

## v3.5f (9 de septiembre, interna)

- **Game Master 2 emulado en el slot 1** (bloque 6): la ROM del cartucho y sus 8 KB de SRAM en la megaram, armado por el menú para los juegos Konami, guardado en `FHUNT\GM2.SRM` como la SRAM de cartucho. Ajustes: *Slot 1* con tres estados.
- Los packs del MSXimus pasan a **512 KB justos, sin la cola de configuración**: grabar un pack ya no pisa los ajustes.
- Se cierra la "pantalla negra" de Metal Gear 2: era la ROM [9692], cuyo arranque comprueba si hay MSX-DOS, no el core.

Core: dado 3461, e140f8da, margen 1,299 ns; respaldo 3457 (0,627 ns). Es la v2 del 138.

## v3.5g y v3.5h (9 de septiembre, packs)

- Corregido el "Enviando GET..." colgado de File-Hunter: una rutina de CRC había ido a parar a la página 1, que durante la sesión de red es la ROM del ESP (regresión de la 3.5b).
- **Tecla G** en la pantalla de lanzar: Game Master 2 On/Off por lanzamiento, para los juegos que usan el mapper Konami-SCC sin ser de Konami. Fuera la línea de velocidad de carga.

## v3.6 (9 de septiembre, interna)

- **DMA de lectura de la SD a la RAM**: el core vacía el búfer de sector sin pasar por el Z80, congelando la CPU con el bus en reposo y escribiendo por el camino del streamer de la flash. De 112 a **640 KB/s**. Guarda del refresco de la SDRAM: el refresco autónomo solo en las ventanas de espera de la tarjeta.
- El menú carga las ROMs por DMA, cluster a cluster.
- El puerto 2Fh dice 3.6.

Core: dado 3529, 29ffd767, margen 0,726 ns; respaldo 3527 (0,148 ns, solo respaldo). Commits ec9893d y bc0e3d0 en MSX_up_v3, e446e65 en la BIOS.

## v3.6b (9 de septiembre, pack)

El análisis del mapper de una ROM sin etiqueta pasa de leer sector a sector por la ventana a una DMA de 256 KB a la megaram y un escaneo con CPIR desde ahí: de siete segundos a dos. Commit 152693e en la BIOS.

## v3.6c (9 de septiembre, interna, validada en placa)

- **DMA en modo lógico**: el destino puede ser una dirección del Z80 que el core traduce con los registros del mapper, que para el Z80 son de solo escritura. Es lo que necesitaba el driver de Nextor.
- **Contadores de patrones de mapper** en la propia DMA: el análisis de una ROM sin etiqueta pasa a coste cero.
- **El driver de Nextor lee por DMA** cuando el búfer está en RAM del mapper: el arranque de DOS y la carga de programas se notan.
- Firma 'M' en el índice 31 de 4Eh.

Core: dado 3533, 1d3ab9ee, margen 0,913 ns; respaldo 3541 (0,039 ns, en el término del refresco, solo respaldo). Commits e5f1a54 en MSX_up_v3, 9aff42a en la BIOS. Validado en placa el 9 de septiembre: DMA a 640 KB/s, DOS arranca mucho más rápido, los discos cargan bien con Nextor 2.1.4 y con Nextor 3, Manbow 2 y Metal Gear 2 con Game Master 2 funcionan.

## v3.6d (9 de septiembre; retirada el 14)

`cpu_run`, el término de seis señales que gobierna el refresco de la SDRAM, pasó a registrado antes de entrar al controlador de memoria: era el peor camino de temporización en los tres dados de la v3.6c (commit 74f95de). **Retirada**: el primer dado que la llevó, el 3557, pasa el gate con 1,17 ns y se queda en negro al arrancar; el 3593, mismo RTL sin este registro, arranca. Un dado de cada, así que no es una prueba cerrada, pero el registro no tenía más función que ganar margen y el margen sin él (0,9 ns) ya cumple. El porqué queda abierto: sobre el papel el registro solo retrasa un ciclo de 54 MHz la puerta del refresco autónomo, y ninguno de los seis términos (reset, streamer de la flash, ESP, F12, DMA) explica que la SDRAM no arranque. Ya pasó algo parecido en la v3.5d al registrar la orden por ventana (dado 3257). Revertida en el commit de cierre de la v3.6e.

## v3.6e (14 de septiembre, interna)

Dos errores del core que salieron a la luz portándolo a la Zynq (`fpga/zynq/`, repo privado `MSXimus_zynq`), donde el buzón de depuración permite inyectar mandos y ratón y leer la telemetría sin hardware. Los dos están en `top.v` y afectan igual a la Console 60K; entran en la siguiente campaña.

- **La cruceta de los mandos, mal cableada desde la v3.1**: `assign joystick0/1` tenía dos errores a la vez. El eje vertical estaba al revés de como lo consume `joy0_msx` (el byte que ve el PSG): ponía arriba en el bit 0 y abajo en el 1, y el consumidor lee arriba en el 3 y abajo en el 2. Y el eje horizontal se tomaba de los bits 10 y 11 de la palabra del BL616, que son los **hombros L y R**, no la cruceta: en el formato del firmware (`usb_gamepad.cpp:337` con `hidparser.cpp`: right/left/down/up en los bits 0-3 del byte HID, subidos a 7/6/5/4) izquierda y derecha son los bits **6 y 7**. En la Console 60K el resultado era: arriba daba derecha, abajo daba izquierda, izquierda y derecha no hacían nada y los hombros movían arriba y abajo. El primer error salió en la Zynq; el segundo, al revisar ese arreglo contra el firmware: el companion de la Zynq (`hid_pad.c`) había copiado del comentario de `top.v` la misma idea equivocada de que la cruceta iba en 10/11, así que allí el arreglo a medias parecía completo. Ahora `top.v` lee 4/5/6/7 y `hid_pad.c` emite ese mismo formato, con los hombros en 10/11. Los botones A/B y el autodisparo no cambian.
- **El ratón perdía el movimiento**: la relectura del registro 15 del PSG devolvía FFh (solo el 14 estaba implementado en la multiplexación de `cpu_din`; el `O_DA` del YM2149 sigue sin conectar). La interrupción de la BIOS lee, modifica y escribe ese registro dos veces por frame para los gatillos de `ON STRIG` (puerto 1 `AND AFh OR 03h`, puerto 2 `AND DFh OR 4Ch`): con FFh de partida escribía AFh y luego DFh, es decir, el pin 8 del puerto 2 subía y bajaba a 60 Hz, y cada pulso hacía que `msx_mouse` capturase y vaciase su acumulador en un ciclo fantasma que nadie leía. `PAD(17)`/`PAD(18)` devolvían 0 salvo con programas que leen cada frame (INDEV lo disimulaba). Ahora el registro 15 se relee (`psgPB`) y las escrituras quedan en CFh/8Fh, con el pin 8 quieto.
- `msx_mouse` gana dos salidas de diagnóstico (`dbg_cur_x`, `dbg_rel_x`) que en la 60K quedan sin conectar.

Commits 39289a2 y 816937c en MSX_up_v3 (rama V3.5). El ratón y la cruceta se validaron en la Zynq desde BASIC: `STICK(1)` 1/5/7/3 para arriba/abajo/izquierda/derecha, `STRIG(1)`/`STRIG(3)` con A/B, `PAD(17)` = 20 para un delta de 80 (sensibilidad ÷4). Queda confirmar el sentido del ratón (`NEGAR_DELTA`) con un programa real.

Core: **dado 3593**, b823b1d3, margen 1,129 ns; holds solo la DDR3 y el anillo del ventilador. Es el RTL de la v3.6c más los dos arreglos de arriba, **sin la v3.6d**. Es el primer core de la 60K con el que se puede probar un mando.

La noche de campañas que lo produjo, para que conste lo que cuesta un dado al 98 % de CLS: siete dados en tres campañas (v36e 3547/3557/3559, v36f 3571/3581, v36g 3583/3593). Cuatro no rutaron (PR0004, entre 84 y 425 redes), uno falló el gate (3571, -0,34 ns en el T80), y de los dos que pasaron, el 3557 (con la v3.6d) se queda en negro y el 3593 (sin ella) arranca. Sin respaldo.

Un apunte que sale de la misma revisión, sin arreglar: los registros 0 a 13 del PSG tampoco se releen (devuelven FFh; `O_DA` del YM2149 está sin conectar, aunque el modelo sí los sirve). Ningún juego probado lo ha echado en falta, pero un reproductor que haga `RDPSG 7` para tocar el mezclador se encontraría todo silenciado.

**Un error del V9968, encontrado la misma noche y sin arreglar: el marcador de Xevious Fardraut Saga sale en blanco.** El juego (Namco 1989, 256 KB, `[GoodMSX] [2489]`) arranca, y el logo, la intro, la demostración y las escenas se dibujan bien; pero en partida la banda del marcador, arriba, sale blanca con puntos de colores en vez del `TOP / HI SCORE / AREA / LEFT` que muestra openMSX. El campo de juego, los sprites y el scroll van bien. Pasa igual en la Console 60K y en la Zynq, luego es del VDP compartido y no de ninguno de los dos portes. En la Zynq se volcó la VRAM durante la partida: la línea 0 de la página 0 tiene gráficos reales, y la zona de las líneas 212 a 255 (`6A00h`-`7FFFh`, fuera de la ventana visible) está entera a `FFh`, que en SCREEN 5 es blanco. Es decir, el VDP está mostrando arriba una zona de VRAM que nadie ha escrito. El juego usa el truco clásico de mover el desplazamiento vertical (R#23) a media pantalla con la interrupción de línea (R#19) para que el marcador quede quieto mientras el campo hace scroll, y los dos registros existen en `vdp_cpu_interface.v`, así que es un detalle de comportamiento y no una función que falte. Quedan dos mecanismos por separar: o el marcador vive en otra zona y a media pantalla se aplica el desplazamiento equivocado, o el juego sí lo dibuja en las líneas 212-255 y el V9968 pierde las escrituras por encima de la línea 211. Lo primero que hay que hacer es mirar en openMSX dónde escribe el juego el marcador y qué valor toma R#23 al principio del cuadro. Herramientas de la Zynq para seguirlo: `tools/vram.tcl` vuelca la VRAM cruda desde la DDR y `tools/vramfill.tcl` la rellena. Sin probar en el MSXnano, que lleva el VDP clásico.

## v3.6f (16 de septiembre, interna)

**Mandos por los USB-A.** Hasta aquí los dos USB-A solo servían teclado y ratón ("gamepads USB-A = pieza futura", decía `top.v`) y el único camino para un mando era el host USB del BL616, que vive en el USB-C OTG y necesita un hub o adaptador OTG con alimentación en el puerto donde va el cargador. Se descubrió el 16 de septiembre con el panel de F12 diciendo `USB: nada` y el mando en un USB-A. `usb_hid_host` ya sacaba `game_snes`, y en el mismo formato SNES de doce bits que la palabra del BL616: se OR-ea con el mando 1 del MCU, gateado por "hay mando en ese puerto" y sincronizado a 54 MHz. Cualquier mando en un USB-A cae en el puerto 1 del MSX. Commit 9a80f4d.

Límite: el host del fabric es HID puro con el informe de los mandos genéricos (ejes a 00/7F/FF). Un mando XInput (Xbox y los receptores 2,4 GHz que se presentan como Xbox 360, como el del Lenovo C01) no se ve por USB-A; con el firmware del BL616 y un hub en el OTG sí se enumeraba, pero la lectura de interrupción fallaba (`XBOX client #0: submit failed`), y Albert decidió no seguir por ahí: el BL616 se queda sin mandos, con su firmware congelado en el commit 3e67939 (el del panel con las filas de diagnóstico), y los mandos del MSXimus son HID por USB-A.

Del firmware del BL616, ya que se tocó: el `bl616_v3.1.bin` publicado el 26 de agosto se compiló sin `usbh_initialize()`, la pila USB host, que se fue por delante al quitar los montajes de FatFs; ningún mando pudo funcionar nunca con esa release. Repuesta en 0219b25, y de paso la cruceta como hat switch y el recorte de ejes de más de 8 bits, portados de FPGA-Companion (7146b7c). Repositorio privado de respaldo `MSXimus-firmware-bl616`.

Core: dado 3623, 2667d28b, margen 0,756 ns (clk_86, dentro del shim del V9968); holds solo la DDR3. Campaña v36h, cuatro dados: 3613 y 3607 fuera de gate (-0,05 y -1,87 ns en el motor del OPL4), 3617 con una red sin rutar. Sin respaldo. En la semana, once dados para tres útiles: al 98 % de CLS la campaña de tres ya no basta, y la de cuatro tampoco sobra.

## v3.7b (17 de septiembre, noche; en campaña): la calibración de la DDR3 desde el cargador

En placa, con el 4139: el arranque desde el cargador falla 3 de 5 veces (negro más de 10 s y después el menú sin el logo); el 4153 de respaldo, negro siempre, también desde el PC. En los dos, el LED U12 parpadea solo y más rápido con F11: es el chivato de la v3.6g (cuenta con el reloj de bus), es decir, **la DDR3 de la VRAM no calibra y el MSX corre por debajo**. Igual que el 3557 y el 3623; el 3593 y el 4001 calibran siempre. No es el BL616 (mismo firmware en todos) ni la colocación de la IP (idéntica en nueve dados, buenos y malos, según los informes): es la probabilidad de éxito de cada intento de calibración, que depende del dado y de la alimentación, la "lotería del ojo" de la saga de julio. Un dado que la tenía en ~1/7 (la _128Z) calibraba en 2 s; el 4153 la tiene en ~0.

- **Motor de reintentos escalonado** (b5c15ee, `v9968_ddr3_backend`): 8 intentos de 335 ms como hasta ahora, 4 de 671 ms, 4 de 1,34 s y después de 2,68 s; a partir del 17º (~11 s fallando) el pulso de reset incluye el PLL de 297 MHz, que es lo que hace un apagado y encendido (el remedio de nand2mario para un fallo), y la IP no sale de reset hasta que el PLL reengancha. Nunca se toca nada *durante* un intento (lección de las _129). Un dado que calibra a la primera no nota nada.
- **La espera del arranque pasa de 5 a 10 s**: sin vídeo no hay nada que hacer antes, y así un dado lento calibra sin que el MSX haya arrancado a ciegas y perdido el logo.
- **Puertos 2Ah-2Ch**: intentos fallidos, duración del intento bueno y tiempo total, para que "falla 3 de 5" pase a ser un número por dado (y para saber si un intento normal tarda 30 ms o 300 ms).
- Banco de pruebas del backend con la IP fallando 18 intentos seguidos: ventanas, resets del PLL y contadores como se espera; la suite T1-T9 sigue en verde.
- Campañas de la noche (b5c15ee, cuatro de cinco dados, 23:02-01:31): v37e 4 de 5 pasan el gate (4159 0,081 ns, 4177 0,020, 4201 0,039, **4211 1,010**), v37f 1 de 5 (4231 0,068; 4229 con seis caminos de la propia IP DDR3 sin cerrar), v37g 1 de 5 (**4273 0,465**), v37h 2 de 5 (4289 0,328, **4297 1,616**). Veinte dados, nueve por el gate, tres con margen de entrega: 4297, 4211 y 4273, en `files/20260918/` con un LEEME de cómo medirlos desde el cargador. Los tres llevan el motor nuevo y los puertos; cuál calibra es la lotería del dado.

## v3.7 (17 de septiembre): mezclador de audio por fuente

Pedido de Albert la misma tarde en que la v3.6h arrancó desde el cargador ("ya que estamos"). Es el mezclador que la línea Zynq estrenó ese día (5d3b409), traído tal cual.

Core: dado 4139, 6175b7c5, margen **2,012 ns** (uadpcm, clk_54m), el mejor de la era v3; holds solo la IP DDR3 (0,040). RTL = 82b1b9c (el HEAD 4c163f7 solo añade una etapa de registro en la escritura del 44h, sin cambio funcional). Campaña v37c, cinco dados: 4129 sin rutar, 4133 −0,154 ns en el decodificador del 44h (por eso el registro del HEAD), **4139, 4153 (1,243 ns) y 4157 (1,130 ns) pasan el gate**: 3 de 5, contra el 1 de 5 habitual, por el cierre del cruce de `cpu_run` (abajo). Respaldo: 4153. Packs nuevos obligatorios para ver la página (bios 6db0cf8: 2.1.4 fb9b6c38, Nextor 3 10321483).

- **Puerto 44h extendido**: `{solo_sel, canal, nivel}`. Canal 0 = la ganancia maestra de siempre (compatible con `OUT 44h,0..7`), 1-6 = PSG, SCC, OPLL, MSX-Audio, OPL4 FM, OPL4 wave con nivel 0-8 = k/8 aplicado a cada fuente **antes** de la suma; el 7 (WaveGame) no existe en el Tang (lee Fh, la escritura se ignora, el menú esconde la fila porque el 2Fh es < A0h). Lectura `{0, canal, nivel}` y sonda `OUT 44h,F0h`. Los diez multiplicadores 19×4 caen en DSP (MULTALU27X18: 8 → 18 de 118): LUT +94, ALU −47, es decir, área neutra.
- **Persistencia en la cola del pack**: el bloque de configuración de la flash (0x480000 en el 60K; 0x880000 en el 138) pasa de 6 a 11 bytes: los 6 de siempre, los 28 bits de niveles en little-endian y un byte de suma (xor ^ A5h). Un bloque viejo de 6 bytes (flash borrada detrás) siembra lo de siempre y deja el mezclador a 8/8; un bloque con la suma mal o un nivel > 8, igual. Testbench en Icarus de la captura y la siembra (cinco escenarios).
- **Error latente arreglado**: `config_init` era la ventana *entre* la captura del penúltimo byte y la del último, así que los consumidores a 27 MHz leían el último byte viejo. Con 6 bytes ese último era la ganancia maestra: probablemente nunca se sembró de la flash en el Tang (nadie lo notó porque el defecto x5 es el valor que se usa). Ahora es un pulso de 4 ciclos tras el último byte, con todo estable; el testbench reproduce el fallo con la ventana vieja.
- El menú (bios 5568de4 + d991daa): fila *Mezclador de audio* en Ajustes con la página de ocho filas, barra de octavos y nota de prueba por chip; en el Tang sin mezclador (3.6h) ofrece solo la ganancia maestra. Los packs nuevos llevan además el arreglo de los SSID en kana del setup WiFi (724ba64).
- Versión del core en el 2Fh: 37h.
- **El peor camino de todos los dados, cerrado** (82b1b9c): el término del refresco autónomo (`cpu_run` = reset & flash_idle & esp_boot_ok & ~iosys_frz & ~dma_rfsh_ok) entraba combinacional desde clk_54m al RESET de los contadores de refresco de la SDRAM en clk_108m, un cruce de 9,26 ns. Fue el peor camino del 4001 (0,771 ns), de los dos marginales de la v36q y tumbó tres de los cuatro dados rutados de la v37a (−1,1, −3,1, −1,2 ns). Vuelve el registro a 54 MHz de la v3.6d (retirada por un negro que resultó ser la DDR3) y `memory.v` lo resincroniza con dos FF a 108 MHz: el cruce es FF → FF sin lógica. El retraso de ~37 ns es inocuo (el T80 tarda ≥ 280 ns en su primer ciclo de bus; la DMA espera 40 ciclos antes de escribir); `tools/sdr16_tb` pasa entero (TZ: 0 refrescos autónomos con el Z80 vivo).
- Campaña v37a (4049-4079, RTL sin ese registro): 4 de 5 rutaron (el mezclador no estorba al rutado), 3 tumbados por ese camino y 4057 por −0,3 ns en `cpu1 → ff_sd_sector`. v37b abortada; v37c con el registro dio los tres dados de arriba.

## v3.6h (17 de septiembre): generación C del V9968 y espera a la DDR3

La última build de la era v3 por decisión de Albert: después de esta, solo errores graves.

Core: dado 4001, c70eae6d, margen 0,771 ns (clk_54m→clk_108m, `u_sddma` → `mem1/rfsh_gap`); holds solo la IP DDR3 (0,040). RTL = 679b8f0 (idéntico en síntesis al HEAD 17/09 con `DIETA_V36H` apagado). PnR 14 min. Campaña v36q, cinco dados: 3947 y 4003 sin rutar (166 y 188 redes), 3989 fuera de gate por -0,006 ns en `ff_flash_state`, 3967 gate OK pero 0,005 ns (respaldo solo para pruebas). Packs: los de la V3.6c sin cambios.

- **V9968 generación C** (679b8f0, traído de la Zynq): R#20 y R#21 se ignoran mientras el bit 7 del puerto #4 (9Ch, y su espejo 8Ch, que ahora se decodifican) esté a 1, que es el estado tras el reset; el puerto #4 devuelve ese bit. Y la máscara del A17 en las bases de tabla en modo V9958. Es lo que saca el marcador de Xevious Fardraut Saga: la BIOS escribe R#20..R#23 = 0 en cada init del VDP y en la generación B eso encendía el modo nativo sin que nadie lo pidiera. Consecuencia: el software de la generación B (DEVCON con 0x9F, V9968DM, la TECH DEMO 0.7.0) no ve el V9968 hasta que haga `OUT (9Ch),0` antes de tocar R#20/R#21.
- **El MSX espera a la DDR3** (856d9c6): el paso a `reset3_n` (streamer del pack y Z80) espera a `ready` del backend DDR3 de la VRAM, con tope de ~5 s para arrancar a ciegas si nunca calibra. Y **el LED de la SD (U12) parpadea solo** mientras la DDR3 no ha calibrado (42c7d1d): el único chivato sin PC. Motivo: los dados 3557 (v36e) y 3623 (v36h) se quedaban en negro desde el cargador y arrancaban desde el USB del PC, con el 3593 arrancando siempre; S1 no lo curaba, lo que apunta a la calibración de la DDR3 y no al core MSX (y exculpa, probablemente, a la v3.6d).
- **La dieta, probada y retirada** (7d0f761, retirada el 17/09): fuera de la build la telemetría serie, la tira WS2812, el ventilador por temperatura y el segundo PSG, y un solo decodificador de teclado; LUT 38.100 → 36.173 (-5,1 %). Con un 5 % menos de lógica el placer 1 rutó **peor**: 0 de 13 colocaciones distintas (v36l/m/n/p), contra 9 de 16 con el netlist completo en la semana anterior; la campaña de control sobre el netlist sin dieta (v36q) rutó 3 de 5 y dio el 4001 al primer intento. Es la lección del 08/08 otra vez: al 96-98 % de CLS manda la congestión local, no el área. La dieta queda como opción (`DIETA_V36H` en `top.v`, apagada) por si sirve en una caza; la producción lleva todo lo de la v3.6g.
- Campaña v36k: los cinco dados murieron en el SDC (una excepción sobre `psg2`, que la dieta había quitado; Gowin aborta ante un objeto inexistente). La línea vuelve con el PSG2; si se compila con `DIETA_V36H` hay que comentarla.
- Campañas v36l, v36m (con `maxfan 50`) y v36n: 0 de 15, todos sin rutar, y con un segundo problema encima de la dieta (3e87b28): el latido mínimo del `dbg_uart` comparaba con `==` y el placer daba la misma colocación para dados distintos (3761 y 3847 idénticos, 3797/3803/3877 idénticos): quince dados que eran unos ocho. Vuelve el `>=` de la telemetría completa. La v36p, ya con dados reales, confirmó el 0 de 5 de la dieta. La v36o (dieta con `place_option 2`) rutó 4 de 5 pero ninguno cerró setup (-0,12 a -0,72 ns): el placer 2 congestiona menos y coloca peor, como se midió el 08/08. `tools/encadenar_campanas.ps1` tira campañas una tras otra (variantes, árboles de control) hasta un gate OK.

## Pendiente

Del 138, por delante de todo, cuando haya placa:

- **Probar el porte en una placa 138K**, en el orden del plan de `files/20260907/LEEME_138_v1.txt`: logo y menú, Ajustes, SD por las tres rutas, ROMs grandes y SRAM, DOS, OPL4 a 36 MHz (velocidad y cortes), V9968/DEVCON, WiFi/File-Hunter, ventilador y botones a 3,3 V; y después lo de la v3.7 (DMA, mandos por USB-A, mezclador, calibración de la DDR3 con `pll_stop→ENCLK2` y sus puertos 2Ah-2Ch).
- Los pines sin contrastar contra el esquemático (`sd_*`, `spi_irqn`, `s2`, `fan_en_o`, `esp_*`), la versión del chip (B o C, por la serigrafía) y el firmware del BL616 para la 138K.
- Cerrar la campaña `p138j`: dado, hash y margen de la v3.7 en `files/20260918/`.

Heredado del 60K (el core es el mismo):

- Xevious Fardraut Saga: el marcador en blanco (V9968, ver arriba).
- Validar los mandos HID por USB-A de la v3.6f y el ratón sin INDEV (en el 60K el ratón quedó validado el 16 de septiembre con el 3593; en el 138, con todo lo demás).
- Entender por qué el `cpu_run` registrado (v3.6d) deja la SDRAM sin arrancar, si es que es él: un segundo dado con y sin el registro lo cerraría.
- Fase 3 de la SD: reloj de la tarjeta a 13,5 MHz, que exige rehacer el divisor y el muestreo.
- Guardado de Manbow 2, que usa una flash AMD en el cartucho en vez de SRAM.
- Publicar la v3.6: carpeta de release, notas y créditos.

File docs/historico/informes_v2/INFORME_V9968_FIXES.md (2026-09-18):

# Cierre de la campaña "últimos bugs del V9968" — MSXimus

Fecha: 2026-07-28 · HEAD de referencia: `8e1c467` (_161e, camino de audio en tres etapas)
Repo: `C:\Users\alber\proyectosAI\msx\MSX_up` (NO modificado: todo va en `.patch`)
Parches: `C:\Users\alber\AppData\Local\Temp\claude\C--Users-alber\8d6fc485-fa87-43bb-a6d5-f5fe1500a986\scratchpad\v9968fix\`

Siete frentes: seis bugs del informe del niquelado (#1, #2, #16, #17, #18, #19) más el glitch del logo MSX2+ que estaba en la lista de limitaciones del README. **Ninguno se ha sintetizado con Gowin** (la máquina estaba horneando) y **ninguno se ha visto en placa**: todo lo de abajo es simulación (Icarus + Verilator bajo WSL).

---

## 1. Tabla resumen

| # | Bug | Veredicto | Qué se arregló | Ficheros de RTL tocados | Verificador adversarial | Riesgo |
|---|---|---|---|---|---|---|
| **#1** | Doble ejecución / livelock del bus de la CPU | **ARREGLADO** (con condición) | El latch de `vdp_cpu_interface.v` aceptaba con `bus_valid && ff_bus_ready` **crudo** mientras el maestro (`v9968_cpu_glue.v`) solo da la transferencia por hecha con el `bus_ready` gateado. Los dos lados no coincidían en QUÉ ciclo era la transferencia → doble ejecución y, en el peor caso, **livelock** (bus atascado + VRAM machacada). El efecto más destructivo medido no es el "salto +1" de las lecturas sino el **OUT al puerto 1 duplicado**, que toggla `ff_2nd_access` dos veces y desincroniza el par de bytes (46 de 48 fases con R#7 pegado en el valor viejo). Fix de 3 líneas: `wire w_bus_accept = bus_valid & bus_ready;` y el latch acepta con eso. Bit-idéntico en tráfico normal. | `fpga/v9968/vdp_cpu_interface.v` (+19/−1) · `fpga/v9968/ORIGEN.txt` · bancos nuevos `tools/v9968_sim/tb_cpuif_dbl.sv` + `run_cpuif_dbl.sh` | **DUDOSO.** Diagnóstico y fix correctos y sin regresión (logs byte-idénticos, verificados por el revisor). PERO el revisor **reprodujo** el "residuo hermano" que el autor documentó y declinó parchear: con la pre-lectura lanzada en el mismo ciclo de la aceptación, la transacción se pierde en silencio. A LAT=200 (placa ≈190): original OK=13/PERDIDAS=102/DOBLES=115 → parcheado OK=27/**PERDIDAS=203**/DOBLES=0. El parche mata la doble ejecución **y duplica las pérdidas silenciosas**, que producen EL MISMO desincronizado del par de bytes que se pretendía cerrar. La cura de UNA LÍNEA que el propio autor escribe y descarta (`&& !w_bus_accept` en la rama de la pre-lectura) sube el barrido a 230/230, 0 pérdidas, 0 dobles, y es neutra en los 5 modos del banco del autor. | **MEDIO** mientras falte esa línea; BAJO con ella. Gate: un nivel de LUT más en el enable del latch, 0 FF nuevos, camino del bus de la CPU (no las familias crónicas de placement). **No cubre**: bug #26 del glue (descarta flancos de `csw_n/csr_n` sin cola ni /WAIT, sigue vivo >2,5 µs) ni la rancidez de lecturas cuando la latencia supera el presupuesto del Z80. |
| **#2** | Deadlock de la caché de comandos al abortar un flush | **ARREGLADO** (dos parches) | `vdp_command_cache.v`: un R#46 (start, legal sin esperar CE=0) que cae con un flush **ya drenado** (típico tras POINT/SRCH/LMCM, que no ensucian) ponía `ff_busy=1` sin nadie que lo bajara → `cache_vram_ready=0` **para siempre**. Fix: 1 línea `ff_busy <= 1'b0;` en el estado `3'd1`, único punto por el que pasan TODOS los flushes. El esbozo A del informe está **refutado** (dejaba el mismo deadlock si lo que había en vuelo era una lectura). **HALLAZGO NUEVO #2b**: con la caché ya sana el "rectángulo fantasma" SIGUE — el `w_cache_flush_end` del comando abortado apaga el `ff_command_execute` del comando NUEVO (`vdp_command.v:1115`) y congela sus contadores; también clobbrea `reg_ny` (:822) y `ff_border_detect` (:1124). Fix: cualificar los tres con `&& (ff_state == c_state_finish)`. | **P1**: `fpga/v9968/vdp_command_cache.v` (1 línea) + `tools/v9968_sim/tb_cmdcache.sv`/`run_cmdcache.sh` · **P2 (#2b)**: `fpga/v9968/vdp_command.v` (3 sitios) + `tb_cmdghost.sv`/`run_cmdghost.sh` | **CONFIRMADO** (el más sólido de la campaña). El revisor rehízo el A/B, escribió dos escenarios adversariales propios ([F] R#46 en el mismo ciclo del `rdata_en` con caché sucia, [G] el maestro mantiene `valid` desde dentro del flush) y ambos pasan. Aporta una **demostración** de la neutralidad de timing (llegar a `3'd1` con `ff_busy==1` ⟺ el flush no emitió ni una escritura) y un argumento extra a favor del P2: HRA **ya** cualifica ese mismo `w_cache_flush_end` con `ff_state==c_state_finish` para `ff_command_end` (`vdp_command.v:346`). Huecos nombrados: la batería del repo no ejecuta ni una vez la línea parcheada (solo comandos de escritura), y `tb_cmdghost` no barre k negativo. | **BAJO.** P1: 0 lógica combinacional nueva. P2: un comparador de 6 bits sobre `ff_state` (que ya lleva `syn_maxfan=4`) para tres FF de control. **Dependencia dura: con SOLO el P1 el rectángulo fantasma NO desaparece.** Residuales preexistentes en el mismo camino: #16 y #17 (abajo) y una tercera vía de pérdida de lectura (respuesta descartada en silencio mientras `ff_flush_state != 0`). |
| **#16** | Respuesta de lectura huérfana tras abortar | **ARREGLADO** | La respuesta de una lectura ya aceptada llega 14–90+ ciclos después; si entre medias hay `start`, la rama `command_vram_rdata_en` **resucita** la entrada `cache#0` —que ya es del comando NUEVO— con la dirección ABORTADA. Medido: el byte del comando nuevo acaba escrito en la dirección vieja (`VRAM WR addr=30000 … data=…5c`) + `rdata_en` espurio que pisa `ff_read_pixel/ff_read_byte`. Fix: dos contadores de 2 bits (`ff_read_pending`/`ff_read_discard`) en un **always propio** (la aceptación hay que verla EN EL CABLE) y la rama de respuesta gateada con `ff_read_discard == 2'd0`. | `fpga/v9968/vdp_command_cache.v` (líneas 115, 695, 757) + `tb_cmdcache_abort.sv` | **CONFIRMADO.** El revisor verificó la procedencia (md5 del fichero parcheado), rehizo la batería (idéntica) y escribió 5 escenarios adversariales que el banco del autor no cubría: **ADV-A** (lectura emitida pero JAMÁS aceptada + start → el contador NO se arma; era el riesgo nº1, un falso positivo se habría comido la respuesta buena = CE=1 permanente), **ADV-C** (dos abortos encadenados: HEAD entrega el byte equivocado, parcheado correcto → el parche es **más fuerte** de lo que el informe afirma), **ADV-E** (desborde del contador: degrada al comportamiento de HEAD, **no cuelga**). Reparo menor: el comentario del RTL dice "≤2 en vuelo"; en realidad tolera 4 (3 descartes). | **BAJO.** +4 FF, un término más en el enable de la última rama; no toca ningún camino de dirección/dato. Residual real (no hipotético): **respuestas fuera de orden** — la cabecera de `vdp_vram_interface.v` documenta que el shim sirve fuera de orden y ni el banco del autor ni el del revisor lo modelan; si la nueva llega antes que la huérfana se descarta la buena → corrupción, no cuelgue. Cerrarlo exige un bit de generación en `vram_tag/vram_rtag`. |
| **#17** | Strobe `rdata_en` colgado tras abortar | **ARREGLADO** (con reservas) | Si el R#46 cae en el único ciclo en que `ff_cache_vram_rdata_en` está alto y además hay flush sucio, las ramas de mayor prioridad lo tapan durante TODO el flush; al acabar, el motor ve `ready=1`, da su petición por aceptada y espera **para siempre** un `rdata_en` que ya nadie generará (CE=1 hasta el siguiente R#46). Fix: 1 línea `ff_cache_vram_rdata_en <= 1'b0;` en la rama del start. Medido: 236 cuelgues en 5 latencias → 0. No hace falta blindar también `cache_flush_start`. | `fpga/v9968/vdp_command_cache.v` (rama start, ~línea 171) + `tb_cmdcache17.sv` | **DUDOSO.** El revisor confirmó mecanismo, ausencia de pérdida de dato y neutralidad ciclo a ciclo, y **amplió** la prueba (abortos encadenados a espaciado realista: PRE 335 cuelgues → POST 0). Dos huecos medidos: **(A)** el parche quita el único rescate *accidental* de `ff_busy` (el `ff_busy <= 1'b1` de la rama start-sucia del FIX ABORTO no tiene bajador garantizado): 15 casos de "caché encallada" que solo aparecen en POST, todos con 2–4 ciclos entre dos R#46 — **inalcanzable para el Z80**, desaparece a espaciado realista. **(B)** el beneficio solo está demostrado con un comando de LECTURA detrás: con LMMV/HMMV la clase #17 va 46→46 porque el que manda es el CE prematuro (= bug **#2b**). No se puede vender como "el fin del comando fantasma" sin el #2b. | **BAJO** con #2b y #16 aplicados; engañoso sin ellos. Cero lógica nueva (solo añade `start`, ya la señal de máxima prioridad, al enable de un FF de 1 bit). Deja un peligro latente nombrado: `ff_busy <= 1'b1` sin bajador garantizado (candidato a ticket propio). |
| **#18** | Scroll horizontal de sprites vs. splits de R#27 | **ARREGLADO** (con corrección pendiente) | La resta del scroll de sprites del _120 usaba `reg_horizontal_offset_l` (**R#27 vivo**) mientras el FONDO usa el latcheado, que solo se carga una vez cada DOS líneas → un split de R#27 llegaba antes a los sprites que al fondo (hasta **7 px** de desalineo, ráfagas de ~2 líneas). Fix: wire `w_horizontal_offset_l_next` (función de próximo estado del latch) restado en `ff_screen_pos_x_sprite`, conservando el registro que el _120 añadió por timing. Corrige además una afirmación **falsa** del ORIGEN.txt ("bit-exacto … incluso en el cambio de R#27"). | `fpga/v9968/vdp_timing_control_ssg.v` · `fpga/v9968/ORIGEN.txt` · nuevos `tools/v9968_sim/tb_hscroll_sprite.sv`, `gen_ssg_variants.py`, `run_hscroll.sh` | **DUDOSO.** El revisor confirmó el diagnóstico leyendo el core (asimetría real: `vdp_timing_control_ssg.v:155-163/432` vs `vdp_timing_control_screen_mode.v:226-227`), reprodujo el A/B (fix vs ref: 0 desajustes en 1,03 M ciclos con vivo≠latcheado) **y encontró que la frase "BIT-EXACTO" que el parche deja escrita en el RTL y en ORIGEN.txt es FALSA**: durante la aserción del reset el mux devuelve el valor viejo, no 0 → 1 ciclo de divergencia. Impacto en placa nulo, pero es el mismo tipo de sobre-afirmación que este parche viene a corregir del _120. Variante de UN token (`!reset_n ? 3'd0 : …`) probada en verde con 0 desajustes. Además: `run_hscroll.sh` devuelve 0 aunque imprima `*** FALLO ***`. | **MEDIO.** **No es cosmético**: cualquier demo/juego con splits de R#27 por línea verá los sprites moverse hasta 7 px respecto a las builds actuales (hacia lo correcto, alineado con el fondo y con el V9958/upstream). Gate: un mux de 3 bits en el operando del restador, destino FF (no reintroduce el cono que el _120 vino a romper); salida documentada si el ruter protesta = el truco del _120f. |
| **#19** | Snap del coeficiente bilineal a `8'd63` | **INERTE** | **No se toca nada.** Con `c_numerator == reg_denominator == 192` el acumulador Bresenham es un punto fijo (`w_hold` siempre 0, `ff_numerator ≡ 0`) → `ff_coeff ≡ 0` con snap o sin él desde el commit de bordes `6d15c0b`: cambiar `8'd63` por `8'd255` sería un **NO-OP**. Y la consecuencia visual que el esbozo atribuía al bug ("1 de cada 3 fronteras con columna fantasma al 25 %") es **FALSA incluso para el RTL anterior**: el coeff 63 aparecía en 41 280 ciclos y en NINGUNO `tap0 != tap1` (cae siempre en la columna de HOLD). El _142 hacía lo que prometía. | `fpga/v9968/vdp_video_out.v` — **+57 líneas, TODAS de comentario, 0 de código** | **CONFIRMADO** ("sin cambio funcional que verificar"). | **CERO.** Netlist idéntica, no requiere resintesis ni prueba en HW. La conclusión depende de tres invariantes enumeradas en el propio comentario (`c_numerator == reg_denominator`, `c_start_numerator = 0`, el `8'd192` que cablea `vdp.v`); si alguna cae, el valor correcto del snap es `8'd255`, no `8'd63`. |
| **LOGO** | Glitch del logo MSX2+ | **ARREGLADO** (con reservas) | **NO es entrelazado de vídeo** (R#9 = 0x00 en las cinco capturas de la FS-A1WSX): es el "entrelazado" de **PÁGINAS del scroll SP2**. La BIOS pinta el logo en SCREEN 5 página 1 y lo anima con R#25=0x03 (SP2\|MSK) vía registro indirecto R#17→R#26/R#27; SP2 reparte los 512 px en dos páginas y el core cambia de página **una vez por línea activa**. El productor de prefetch del shim (+2 lineal) no genera C+1 tras el cruce → **exactamente 1 miss por línea = 185–193/frame**. Fix "_163 ECO DE CRUCE DE PÁGINA": reutiliza el eco de arranque del _135 (zona segura, drenaje solo con backend ocioso) para encolar las dos palabras que faltarán, reconociendo el cruce **sin mirar ningún bit de página**. Con UN solo tiro la frontera solo se corre una palabra (corrección honesta del propio autor): hacen falta DOS. | `fpga/src/v9968_vram_shim.v` (2 FF `xg_cred`/`xg_snd`, una rama `else-if`, rearme en hblank) · `fpga/v9968/ORIGEN.txt` (nota cruzada; **el core de HRA no se toca**) · nuevos `tools/v9968_sim/tb_logo.sv`, `run_logo.sh` | **DUDOSO.** El revisor confirmó el diagnóstico en el fuente (bit de página SP2 = bit 15 de byte = bit 13 del vector en SCREEN 5), el techo de daño (el drenaje escribe `pww`, **nunca** contesta a un consumidor → no puede devolver dato malo) y que el banco no está inerte. Cuatro huecos: **(1)** la justificación de generalidad es **falsa y comprobable** — en SC7/8 `w_blink_page` cae en el bit 14 del vector (no el 12), que es el **selector de stream**, así que allí lo cubre el _135 y esta rama ni dispara (benigno **por suerte, no por diseño**); **(2)** ningún banco de regresión enciende SP2 → "byte a byte idéntico" solo prueba que la lógica está dormida; **(3)** el banco escribe R#8=0x2A (**sprites apagados**) cuando la captura que él mismo cita dice 0x28 (encendidos): los "3 miss/frame" están medidos con el backend más desahogado que el caso real; **(4)** R#26 solo barre 8..16 de 32 columnas, nunca la frontera en el borde de línea. | **MEDIO-BAJO.** Resultados: miss 185–193 → 3/frame (−98,3 %), píxeles malos ~4300 → 48–112/frame (−97,8 %); 5 frames de control sin SP2 **idénticos**; `tb_sc8cmd_full`, `tb_sc5line`, `tb_cpu_bulk` y `tb_scroll` byte a byte iguales. Riesgos: ocupación del `ecq` (2 empujes/línea más sobre una cola de 3 usables; si en placa aprieta, el guardia `!ecq_full` **descarta en silencio** → volvería el glitch, nunca corrupción; cura = ecq a 8 plazas o prioridad al eco de cruce). Modos de patrones (SC0/1/2, menú TEXT2) sin medir: `tb_screen1` hace timeout igual antes y después. |

---

## 2. ORDEN DE APLICACIÓN recomendado

### 2.1 El solape real

**Tres parches tocan `fpga/v9968/vdp_command_cache.v`** y **tres tocan `fpga/v9968/ORIGEN.txt`**. Son dos situaciones muy distintas:

| Fichero | Parches | ¿Se pisan? |
|---|---|---|
| `fpga/v9968/vdp_command_cache.v` | #2 (P1), #16, #17 | **NO se pisan textualmente.** Los hunks caen en zonas disjuntas: #17 en la rama `start` (~línea 171), #2 en el estado de cierre de flush `3'd1` (~línea 304), #16 en las líneas 115 (declaraciones), 695 (`else if( command_vram_rdata_en )`) y 757 (always nuevo al final). `git apply` recalcula los offsets solo. Los tres verificadores lo comprobaron por separado, y el de #16 va más allá: **son compatibles SEMÁNTICAMENTE**, no solo textualmente — ninguno cambia el significado de `start == aborto`. |
| `fpga/v9968/vdp_command.v` | #2 (P2, bug #2b) | Único. Sin solape. |
| `fpga/v9968/vdp_cpu_interface.v` | #1 | Único. |
| `fpga/v9968/vdp_timing_control_ssg.v` | #18 | Único. |
| `fpga/v9968/vdp_video_out.v` | #19 | Único (solo comentarios). Si algún día se parchea el magnificador cerca de la línea 395, aplicar este **primero**. |
| `fpga/src/v9968_vram_shim.v` | LOGO | Único. No toca nada del agente de audio (`ganancia`). |
| **`fpga/v9968/ORIGEN.txt`** | **#1, #18, LOGO** | **SÍ SE PISAN — conflicto seguro.** Los tres añaden un bloque de bitácora, y **#1 y #18 usan los dos la etiqueta `_162`**. Además el parche de #2 **no** toca ORIGEN.txt a propósito (deja la entrada redactada para que la ponga el orquestador) y el de #17 tampoco. |

### 2.2 Orden

```
0.  RENUMERAR LAS ETIQUETAS DE BUILD (antes de aplicar nada)
    HEAD = _161e (el agente 'ganancia' sigue commiteando en el camino de audio).
    #1   -> _162  (4 apariciones: 3 comentarios en el .v + el bloque de ORIGEN)
    #18  -> _163  (3 apariciones: 2 comentarios en el .v + el bloque de ORIGEN)
    LOGO -> _164  (renombrar el bloque "_163 ECO DE CRUCE DE PAGINA")
    Es un sed; hacerlo AHORA evita dos bloques "_162" contradictorios en el árbol.

1.  bug19/bug19_comentario.patch                 (vdp_video_out.v — solo comentario, riesgo 0)
2.  bug17/bug17_vdp_command_cache.patch          (rama start, ~L171)
3.  bug2_cachebusy/bug2_cachebusy.patch          (cierre de flush, ~L304)
4.  bug16/bug16_vdp_command_cache.patch          (L115 / L695 / L757)
5.  bug2_cachebusy/bug2b_command_execute.patch   (vdp_command.v — OBLIGATORIO con el 3)
6.  bug1/bug1_cpuif_doble_disparo.patch          (+ la línea extra, ver 2.3)
7.  bug18/bug18_v9968_scroll_sprites_162.patch   (+ el término de reset, ver 2.3)
8.  sp2eco/v9968_logo_sp2_163.patch              (último: es el único de fpga/src/)
```

**Por qué ese orden dentro de `vdp_command_cache.v` (2→3→4):** de menor a mayor número de línea del primer hunk **no** es lo que importa (git recalcula), pero sí conviene que el que añade más líneas al final del fichero (#16, con su `always` nuevo de ~57 líneas) entre el último: así los `--check` intermedios son más legibles y, si hay que rebasar algo a mano, el diff de contexto queda limpio. Si prefieres orden alfabético o cualquier otro, **también funciona**; lo verificado es que los tres aplican sobre HEAD y que #2 aplica también después de #16/#17.

**Conflictos previsibles y cómo se resuelven:**

- **ORIGEN.txt (pasos 6, 7, 8)**: el 6 y el 7 chocarán si los dos bloques van al mismo sitio del fichero. Aplicar el de #1 primero, luego el de #18 **con `git apply --3way`** o pegar el bloque a mano; el de LOGO añade una nota cruzada y suele caer aparte. Al terminar, añadir **a mano** la entrada de #2/#2b y la de #17, que sus autores dejaron redactadas pero no parcheadas.
- **Cabecera de ORIGEN.txt**: sigue diciendo que solo `vdp_vram_interface.v` y `vdp.v` están parcheados y "el resto, INTACTO". Ya era falso en HEAD (`vdp_command_cache.v` lleva FIX ABORTO) y esta campaña lo deja mucho más falso: **hay que reescribirla** — es el invariante de trazabilidad contra upstream del propio proyecto.
- **`git status` sucio**: uno de los agentes vio 13 borrados sin stage con nombres extraños en `fpga/` (`fpga/0`, `fpga/el`, `fpga/grupo`, `fpga/CH340`…) y ~70 untracked. `fpga/v9968/` está limpio. Revisarlo **antes** de commitear (los ficheros raros del listado de la raíz —`1`, `2][7`, `300`, `degrada`, `ff_1st_byte`, `n_glue)`— son basura de redirecciones de shell).

### 2.3 Dependencias de contenido (más importantes que el orden)

1. **#2 P1 → #2 P2 (bug #2b): DURA.** Con solo el P1 el bloqueo duro de la caché desaparece pero **el rectángulo fantasma NO**. Medido: RTL tal cual 12/15 · +P1 12/15 (caché sana, motor congelado) · +P1+P2 **15/15**.
2. **#17 → #2b: DURA en la práctica.** El #17 solo cierra el síntoma cuando el comando que aborta es de **lectura** (POINT). Con LMMV/HMMV el que manda es el CE prematuro del #2b.
3. **#17 ↔ #16: complementarios.** Son mutuamente excluyentes por caso (si el strobe está alto, la respuesta que lo generó ya llegó) y quedan 2 cuelgues de 130 con solo el #17. **Entran juntos o no entran.**
4. **#1 necesita su línea extra.** Sin `&& !w_bus_accept` en la rama que lanza la pre-lectura, el parche cambia 115 dobles ejecuciones por 101 pérdidas silenciosas adicionales — el mismo síntoma que iba a curar. Copia probada por el revisor en `…\scratchpad\adv\fix2\vdp_cpu_interface.v`. **Alternativa mínima aceptable**: aplicar tal cual pero **reescribir** el párrafo "RESIDUO CONOCIDO (NO tocado, NO demostrado)" de ORIGEN.txt, porque está demostrado, es alcanzable con la latencia de placa y el parche lo vuelve determinista.
5. **#18 necesita el término de reset.** Cambiar la asignación a `assign w_horizontal_offset_l_next = ( !reset_n ) ? 3'd0 : ( ff_v_count[0] && w_h_count_end ) ? reg_horizontal_offset_l : ff_horizontal_offset_l;` — o quitar la palabra "bit-exacto" del RTL y de ORIGEN.txt y documentar la excepción del ciclo de reset. Un token contra una afirmación falsa en el árbol.
6. **LOGO necesita dos correcciones de texto** antes de commitear: el bit de página en SC7/8 es el **14**, no el 12, y la cobertura de SC7/8 la da el **_135**, no esta rama.

---

## 3. Plan de validación en placa

Nada de esto se ha visto en hardware. Regresión mínima común a **toda** la tanda: arrancar, entrar al menú (TEXT2), cargar una ROM y un disco, y mirar el **COM11** (los `drops` S1/wq deben seguir en 0 y `bgmiss` debe **bajar**).

### #1 — bus de la CPU
- **VRAMSOK2**: es el testigo histórico del "salto ±1" del puerto CPU (~0,1–0,3 %). Es la prueba discriminante: si el residuo baja, el fix está haciendo lo suyo.
- **LDIRVM / LDIRMV** a pelo (bloques grandes, BASIC o un pequeño .COM): no debe perderse ni corromperse un byte.
- **Cargador de ROMs del menú** (miles de bytes por el puerto 0): tiempo de carga y checksum.
- **DEVCON.COM** y la demo **ru66-v9968** de herraa1: el síntoma que este bug produce es el **par de bytes desincronizado** → registros que no llegan a su sitio (R#7 pegado). Si al arrancar la ru66 los colores/bordes se estabilizan, es este.
- Turbo: probar también a **5,37 MHz (WSX)**, que es donde el presupuesto del Z80 aprieta más.

### #2 + #2b + #16 + #17 — motor de comandos y su caché
Todos comparten síntoma (**rectángulo fantasma / comando colgado con CE=1**), así que se validan juntos:
- **DEVCON.COM** (el examen final del V9968) — las dos versiones si hace falta; recuerda que difieren en UN byte (entrada "14"=R#20: 0xFF para nuestra RTL vieja).
- **Suite de tests de HRA** (V9968DM, VDPTEST2) — comandos encadenados y POINT/SRCH/LMCM.
- **Software que reescribe R#46 sin esperar CE=0**: es el disparador exacto. Rutinas que encadenan comandos a pelo, y juegos con mucho blitting — **Aleste 2** (el caso que cerró la campaña de la DRAM) y **Metal Gear 2**.
- **SCREEN 5 / SCREEN 8 con LMMM/HMMM/LMMV** y el **smoothscroll SC5/SC8** de la batería.
- Qué mirar: nada de rectángulos a medio pintar, ningún cuelgue con el VDP ocupado eternamente, y que el **borde** de los comandos (`ff_border_detect`) siga correcto.

### #18 — sprites vs. splits de R#27
- **Parodius** (smoothscroll ya validado en HW): sprites contra el fondo, sin desalineo.
- **Aleste 2** (parallax + sprites) — el A/B más visible.
- **R-Type** con el parche de smooth-scroll (ojo: su jitter de ISR ~15 % de frames es del parche, no del core).
- Batería de scroll SC5/SC8 del proyecto.
- Qué mirar: hasta **7 px** de diferencia respecto a la build _161x, y debe ir **hacia lo correcto** (sprites alineados con el fondo, como en un V9958 real). Si algo se ve peor que antes, es que el juego dependía del desalineo — improbable, pero anótalo.

### #19 — nada
Netlist idéntica. No requiere prueba.

### LOGO MSX2+
- **Entrar a BASIC** en la Console 60K y mirar el logo: el glitch de medio segundo debe desaparecer o quedar casi imperceptible (simulación: 185–193 → 3 misses/frame).
- **Menú (TEXT2)** y SCREEN 1 justo después de salir del logo: es el flanco **sin medir** (el `stride` es pegajoso entre cambios de modo y la rama disparará todas las líneas; el argumento de inocuidad es estructural, no medido).
- **SCREEN 5/8 con scroll** y las escenas duras de las demos.
- **COM11**: `bgmiss` debe **bajar** y los drops S1/wq seguir en 0. Si vuelve el glitch sin corrupción, es el `ecq` lleno → subir a 8 plazas o dar prioridad al eco de cruce.

---

## 4. Lo que queda abierto en el V9968

**De la sección de limitaciones del README** (`README.md:81-87`):
- **Scroll de dos páginas en SCREEN 7 y 8, y scroll hacia atrás**: sin pulir. La campaña **no lo toca** — y el hallazgo del LOGO lo ilumina: en SC7/8 el bit de página cae en el bit 14 del vector (= selector de stream del shim), así que el cruce de página allí es un cambio de stream cubierto por el _135, no la discontinuidad de SCREEN 5. Es el sitio por donde entrar la próxima vez.
- **Líneas residuales** en las escenas más duras de las demos (4–10 misses/frame). El fix del LOGO baja los del SP2, no estos.
- **El logo MSX2+**: el README lo da por "diagnosticado, fix aparcado por rutado". **Esta campaña lo reabre con otro fix** (2 FF en la zona segura en vez de ~100 FF y un mux del productor que atascaron al ruter 62 min en la _154). Actualizar el README **solo tras el veredicto en placa**.
- **El core sigue en la foto de enero de 2026**.

**De `fpga/v9968/ORIGEN.txt` (fixes upstream que faltan):**
- `0683e7e` **R#20/R#21 modificados** — decisión de Albert: mapa viejo en la v2.0, **migración prevista para la v2.1** con las demos parcheadas. Coste: 26 líneas de RTL + 2 bytes de software (DEVCON.COM offset 14883, V9968DM.COM offset 0x377). Cuidado: el comentario del upstream **miente** en el árbol nuevo; en el nuestro aún es cierto.
- `167b7cf` **Sprite Mode2 con PaletteSet# cuando EPAL=1** — FEATURE nueva, 154 líneas de `vdp_sprite_makeup_pixel.v`. **Sin portar.**
- `5978d18` **clone FF para relajar timing** — no portado; nuestros clones _120/_125b cubren todo lo suyo **salvo el registro de `intr_line`** (reserva anotada por si el gate vuelve a quejarse).
- Migración a **th9958** documentada como plan (rama `th9958`), con la lista de qué tomar limpio y qué re-aplicar.

**Residuos técnicos que esta campaña deja nombrados y NO cierra:**
- **Bug #26 del glue**: `v9968_cpu_glue.v` descarta flancos de `csw_n/csr_n` sin cola ni /WAIT; corrompe a latencias >2,5 µs. Vivo.
- **Rancidez de lecturas** cuando la latencia de VRAM supera el presupuesto del Z80 (límite conocido del _149).
- **Respuestas de VRAM fuera de orden**: el tag `{consumidor, byte_sel}` no lleva número de secuencia; ni el banco del autor ni el del revisor lo modelan. Cerrarlo exige un bit de generación que viaje hasta el shim.
- **`ff_busy <= 1'b1` sin bajador garantizado** en la rama start-sucia del FIX ABORTO: el #17 le quita el rescate accidental. Merece ticket propio.
- **Tercera vía de pérdida de lectura**: una respuesta que llegue mientras `ff_flush_state != 0` se descarta en silencio. Preexistente y ortogonal a #16/#17.
- **`tb_sc8cmd_full` está ROJO en HEAD** (`fallos_vram=7428`), probablemente por una referencia `s8r_frame.txt` desfasada. Es el **único** banco de la batería que machaca comandos, así que **hoy no sirve como puerta verde de regresión**. Arreglarlo o regenerar la referencia.
- **`tb_screen1` hace timeout** (preexistente, idéntico antes y después) y **`tb_sprite3` corre "en verde" con todos los contadores a 0** (banco inerte sin sus `define`s). Ninguno vale como evidencia.
- **Cero síntesis Gowin** en toda la campaña, con CLS al 84 %. Los siete parches tienen su salida documentada si el ruter protesta, pero **el impacto real en el gate está sin medir**.
- La **cabecera de ORIGEN.txt** miente sobre qué ficheros están parcheados.

---

## 5. Recomendación (3 líneas)

1. **Aplica YA, en un solo commit**: #2 (P1) + **#2b** + #16 + #17 — es el bloque coherente que mata el rectángulo fantasma y los cuelgues del motor, dos verificadores CONFIRMADOS y los otros dos con huecos acotados e inalcanzables por el Z80; y #19, que es solo comentario y riesgo cero.
2. **Aplica también, pero con su corrección de una línea cada uno**: #1 (con `&& !w_bus_accept` en la rama de la pre-lectura, o el bug se convierte en pérdida silenciosa) y #18 (con `!reset_n ? 3'd0 :`, o quita la palabra "bit-exacto" del árbol) — sin esas líneas, el parche deja escrita en el repo una afirmación que su propio verificador ha refutado.
3. **Deja fuera de este commit** el parche del LOGO hasta corregir la nota del bit (14, no 12), rebajar la afirmación sobre SC7/8 y **rehacer `tb_logo` con R#8=0x28** (sprites encendidos, como los deja la BIOS) más el barrido completo de R#26 0..31: el arreglo pinta muy bien, pero está medido con el backend más desahogado que el caso que dice arreglar.

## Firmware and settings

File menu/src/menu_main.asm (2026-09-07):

.ZILOG
.BIOS
.BIOSVARS

ENABLE_SDCARD=1
MSXIMUS=1				; 1 = build MSXimus/Console 60K: sprites 8/linea en bit3 y 16:9 en bit4
ENABLE_MEGARAM=1

; (aliases de structs Enable* eliminados: mapper/megaram/SD van siempre ON)

.org #8000

; #############################################################################
; ##  MSXnano MAIN MENU (Picoverse-style boot menu) - added for M1
; #############################################################################
; This is now the entry point reached after the FM logo (menu.asm decompresses
; this code to #8000 and jumps here). It shows a main menu with 4 options and,
; when "Arrancar sistema" is chosen, returns to the BIOS so the normal MSX boot
; continues (chain to Nextor/MSX-DOS exactly as it would without a cartridge
; INIT taking over).
;
; STACK NOTE: when execution arrives at #8000 the top of the stack is the
; return address into the BIOS boot routine (the original caller of the
; cartridge INIT at #4760). We save SP here so "Arrancar sistema" can restore
; it and 'ret' cleanly back into the BIOS boot flow.

main_menu_entry:
	; Save the BIOS cartridge-INIT return context. At this point SP points at the
	; BIOS return address (the decompressor's final 'ret' consumed the pushed
	; #8000, leaving the BIOS return on top). We store SP in PAGE-3 RAM (#E000),
	; which does NOT remap like page 2, so "Arrancar sistema" can restore the exact
	; SP and 'ret' reliably even if the menu's stack ends up unbalanced for any
	; reason (this is more robust than relying on perfectly balanced calls).
	ld   (BOOT_SP), sp
	pop  hl							; top of stack = BIOS boot return address
	push hl
	ld   (BOOT_RET), hl				; save it: the WiFi ESP ROM may clobber the stack
	; The goauld BIOS boot calls this cartridge INIT a SECOND time before it
	; finally boots the disk. "Arrancar sistema" sets BOOT_FLAG and rets; on the
	; re-run we see the flag and ret again WITHOUT showing the browser, so a
	; single ESC boots (otherwise it took two: logo + browser reappear, then boot).
	ld   a, (BOOT_FLAG)
	ld   b, a
	xor  a
	ld   (BOOT_FLAG), a				; the flag is only valid transiently
	ld   a, b
	cp   #99
	jp   z, second_pass_boot		; pending boot -> continue the boot, skip the menu
	; (el registro Nextor de #A000 lo cubre el padding del .org #A010: el depack
	; del menu escribe esa zona en cada arranque y borra cualquier firma rancia)
	ld   a, #C9						; limpiar un hook H.STKE residual de un juego
	ld   hl, #FEDA					; lanzado antes (si no, "Arrancar sistema" tras un
	ld   b, 5						; reset manual relanzaria el juego en vez del DOS)
.wipe_stke:
	ld   (hl), a
	inc  hl
	djnz .wipe_stke
	xor  a
	ld   (DSK_PEND), a				; sin .dsk pendiente: el 2o pase NO debe reescribir
	ld   (FH_MODE), a				; File-Hunter off (en frio la RAM es basura)
									; el registro NEXTOR (en frio #C0DD es basura y
									; emulaba un disco inexistente -> caia a BASIC)
	; pantalla de logo (slot 0-3): si el pack la trae (magic 'L'), mostrarla
	ld   a, #8C						; slot 0-3 (expandido, pri 0, sec 3)
	ld   hl, #4000
	call RDSLT
	cp   'L'
	jr   nz, .no_logo
	rst  #30						; CALLF a la rutina del logo (SCREEN5, ~0.5s)
	.db  #8C
	.dw  #4002
.no_logo:
	; premontar la SD BAJO el logo (montaje silencioso): si va bien, el
	; navegador se salta el "Leyendo SD..." y aparece ya con contenido
	ld   a, 2						; FILTER = ALL ANTES de escanear: select_partition
	ld   (FILTER), a				; -> scan_root aplica FILTER; en frio era basura y
									; filtraba los ficheros (solo se veian carpetas
									; en el primer listado hasta cambiar de pestana)
	xor  a
	ld   (SD_READY), a
	ld   (SD_LBA+0), a
	ld   (SD_LBA+1), a
	ld   (SD_LBA+2), a
	ld   (SD_LBA+3), a
	call sd_read_sector				; MBR
	ld   a, (SD_STATUS)
	or   a
	jr   nz, .pm_done
	ld   a, (SD_BUF+510)
	cp   #55
	jr   nz, .pm_done
	ld   a, (SD_BUF+511)
	cp   #AA
	jr   nz, .pm_done
	call enum_partitions
	ld   a, (PART_CNT)
	or   a
	jr   z, .pm_done
	xor  a
	call select_partition
	jr   c, .pm_done
	ld   a, 1
	ld   (SD_READY), a
.pm_done:
	call logo_key_window			; V3.1: el retardo del logo ES la ventana de
									; teclas. Vive en el banco >=A010 (aqui no cabe).
	call restore_palette			; restaurar la paleta de fabrica AL SALIR del
									; logo (no mientras sigue en pantalla)
	ld   a, 2
	ld   (FILTER), a				; default tab = ALL

	; --- v1.9: warn if the bitstream (.fs) and BIOS pack (.bin) versions differ ---
	; e.g. someone flashed a v1.8 .fs with a v1.7 .bin. Port 0x2F returns the FPGA
	; version (0x1X); 0xFF = a pre-v1.9 bitstream with no version port. First boot only.
	in   a, (#2F)
	cp   #30						; this pack's version (v3.0)
	call nz, version_warning

; Re-entry point used by the placeholders (M2/M3): re-init the screen and
; redraw WITHOUT re-capturing the BIOS context (which is only valid on the
; very first entry from the cartridge INIT).
main_menu_restart:
	jp   menu_dispatch				; V3.1: S=Ajustes, W=WiFi, nada=arrancar el MSX
	; ---- desde aqui, codigo YA NO ALCANZABLE (navegador, lanzador y
	; ---- File-Hunter). Se borra en una segunda pasada, cuando esto valide.
main_menu_muerto:
	xor  a
	ld   (BROWSING), a
	call init_screen
	; UNIFIED UI (Picoverse-style): the SD browser IS the home screen. Boot and
	; every "return to menu" land here. ESC in the browser = boot the system,
	; 'A' = settings. The old 4-option menu below is kept but no longer reached.
	jp   main_action_sdrom

; --- v1.9 version-mismatch warning (bitstream .fs vs BIOS pack .bin) ---------
; A = FPGA version read from port 0x2F (mismatched). Shows a warning on SCREEN 1
; and holds ~3s with a busy loop (no keyboard/IRQ needed, so it works even if the
; USB keyboard is dead), then returns and the menu continues.
version_warning:
	ld   c, a						; C = FPGA/bitstream version
	ld   a, 1
	call #005F						; CHGMOD -> SCREEN 1 (clears)
	ld   hl, ver_msg1
	call ver_puts
	ld   a, c
	call ver_pnib					; print bitstream version "M.m"
	ld   hl, ver_msg2
	call ver_puts
	ld   a, #30						; this pack's version
	call ver_pnib
	ld   hl, ver_msg3
	call ver_puts
	ld   de, 6						; hold ~3s
.vw1:
	ld   bc, 0
.vw2:
	dec  bc
	ld   a, b
	or   c
	jr   nz, .vw2
	dec  de
	ld   a, d
	or   e
	jr   nz, .vw1
	ret
ver_puts:							; HL -> zero-terminated string, print via CHPUT
	ld   a, (hl)
	or   a
	ret  z
	call #00A2
	inc  hl
	jr   ver_puts
ver_pnib:							; A = version byte -> "M.m" (hex nibbles)
	push af
	rrca
	rrca
	rrca
	rrca
	call ver_hex1
	ld   a, '.'
	call #00A2
	pop  af
	call ver_hex1
	ret
ver_hex1:
	and  #0F
	cp   10
	jr   c, .vh
	add  a, 7
.vh:
	add  a, '0'
	call #00A2
	ret
IF MSXIMUS
ver_msg1:	.db 13,10,10,"  MSXimus: VERSION MISMATCH",13,10,10,"  Bitstream (.fs): ",0
ELSE
ver_msg1:	.db 13,10,10,"  MSXnano: VERSION MISMATCH",13,10,10,"  Bitstream (.fs): ",0
ENDIF
ver_msg2:	.db 13,10,"  BIOS pack (.bin): ",0
IF MSXIMUS
ver_msg3:	.db 13,10,10,"  Flash the .fs and .bin from",13,10,"  the SAME MSXimus version.",0
ELSE
ver_msg3:	.db 13,10,10,"  Flash the .fs and .bin from",13,10,"  the SAME MSXnano version.",0
ENDIF

; --- Option 1: continue the normal MSX boot ---------------------------------
; Behaves EXACTLY like the proven "Save & Exit" of the config menu (known to
; continue the boot on real Goa'uld hardware): clean up the screen and 'ret'
; through the NATURAL, LIVE stack back to the BIOS cartridge-INIT caller, which
; chains to Nextor / MSX-DOS.
;
; ROOT CAUSE of the previous reset (found by debugger): a previous version
; saved SP + the BIOS return address into page-2 RAM variables at entry and
; restored them here. But on the Goa'uld the page-2 (0x8000-0xBFFF) slot/segment
; mapping is NOT guaranteed to be the same when the menu first runs and when an
; option is later selected, so those variables read back as GARBAGE -> "ld sp,
; garbage" + "ret" jumped to a random address -> CPU reset/loop. The fix is to
; never rely on page-2 stored state: the LIVE stack (page-3 RAM) still holds the
; BIOS return address on top here (the menu's calls are balanced), so a plain
; 'ret' returns correctly regardless of any page-2 remapping.
; boot_system: user chose "arrancar sistema". Mark a pending-boot flag (so the
; BIOS's second INIT pass auto-continues instead of showing the browser again)
; and continue the boot.
; second_pass_boot: 2o pase del INIT con boot pendiente. Si hay un .dsk
; seleccionado, REESCRIBIR el registro NEXTOR_EMU_DATA (#A000-#A015): el
; re-depack de este mismo pase acaba de machacarlo (los datos del menu viven
; en #A010+ desde el reorg y el padding cubre #A000-#A00F a proposito).
second_pass_boot:
	ld   a, (DSK_PEND)
	or   a
	jp   z, main_action_boot
	xor  a
	ld   (DSK_PEND), a
	ld   hl, emuSig
	ld   de, #A000
	ld   bc, 16
	ldir
	ld   a, 1
	ld   (#A010), a					; device index (WonderTANG SD)
	ld   a, 1
	ld   (#A011), a					; LUN
	ld   hl, (EMU_LBA+0)
	ld   (#A012), hl
	ld   hl, (EMU_LBA+2)
	ld   (#A014), hl
	jp   main_action_boot

boot_system:
	ld   a, #99
	ld   (BOOT_FLAG), a
	; fall through to main_action_boot

main_action_boot:
	di
	call INITXT						; clear screen (SCREEN 0) before handing back
	ld   bc, #000d					; turn blink mode off (restore normal text)
	call WRTVDP
	ld   sp, (BOOT_SP)				; restore the exact BIOS-INIT SP saved at entry
	ld   hl, (BOOT_RET)				; re-supply the BIOS return address in case the
	ex   (sp), hl					; WiFi ESP ROM clobbered that stack slot
	ei
	ret								; return into BIOS boot -> normal boot continues

; --- Option 2: Lanzar ROM de la SD -------------------------------------------
; M2.1 derisk: prove the boot menu itself can read a raw SD sector through the
; WonderTANG window BEFORE the OS boots. Menu code runs at #8000 (page 2); the
; SD register window is at #7C00-#7EFF in PAGE 1, slot 3-2. We switch page 1 to
; slot 3-2 only around the access, read sector 0, restore page 1 to slot 3-1.
; The sector buffer + scratch live at FIXED PAGE-3 RAM addresses (NOT reserved
; inside the menu image with 'ds', which would inflate the decompressed image).
SD_LBA		equ	#C000			; 4 bytes: LBA to read (page-3 RAM scratch)
SD_CTYPE	equ	#C004			; 1 byte: card type read back
SD_STATUS	equ	#C005			; 1 byte: 0=OK, 1=init timeout, 2=read timeout
part_type	equ	#C006			; 1 byte: MBR partition 1 type
PART_LBA	equ	#C008			; 4 bytes: partition start LBA (FAT16 volume)
ROOT_LBA	equ	#C00C			; 4 bytes: root directory start LBA
disp_row	equ	#C010			; 1 byte: current display row
sec_left	equ	#C011			; 1 byte: root-dir sectors remaining
ent_in_sec	equ	#C01F			; 1 byte: dir entries left in current sector
name83		equ	#C012			; 13 bytes: formatted 8.3 name (ASCIIZ)
ENT_COUNT	equ	#C020			; 1 byte: number of entries scanned
BR_SEL		equ	#C021			; 1 byte: selected entry index
BR_TOP		equ	#C022			; 1 byte: first visible entry index
BR_TMP		equ	#C023			; 1 byte: scratch (draw_entry)
BR_TMP2		equ	#C024			; 1 byte: scratch (draw_browser loop index)
BR_REC		equ	#C025			; 2 bytes: scratch record pointer
ARR_PTR		equ	#C027			; 2 bytes: array write pointer (scan)
BR_OLD		equ	#C029			; 1 byte: previously-selected index (partial repaint)
BR_OLDTOP	equ	#C02A			; 1 byte: BR_TOP before ensure_visible (scroll detect)
ENT_ARRAY	equ	#C300			; entry array: ENT_SIZE bytes each (type,cluster,name)
ENT_SIZE	equ	80				; record: type(1)+cluster(2)+size(4)+name(73 ASCIIZ)
NAME_OFF	equ	9				; name offset inside a record (type1+cluster4+size4)
SIZE_OFF	equ	5				; file-size dword offset inside a record
NAME_MAX	equ	70				; max name chars stored (+ NUL) -> longer than the
								; 59-col window so long names overflow and marquee-scroll
NAME_WIN	equ	59				; name display window width (cols 9..67, size at 69)
VISIBLE		equ	18				; entries per page (list rows 4..21; hdr 1, tabs 2, line 3, sep 22, footer 23)
MAX_ENT		equ	115				; array capacity (115*80 = 9200 bytes -> C300..E6F0)
HAVE_LFN	equ	#C02B			; 1 byte: a long-file-name is being accumulated
LFN_BUF		equ	#C02C			; 80 bytes: assembled long file name (C02C..C07B)
DIR_SP		equ	#C07E			; 1 byte: folder back-stack depth
DATA_LBA	equ	#C090			; 4 bytes: FAT data region start LBA
SEC_PER_CLUS equ #C094			; 1 byte: sectors per cluster
ROOT_SECS	equ	#C095			; 1 byte: root-directory sector count
JOY_PREV	equ	#C096			; 1 byte: previous joystick code (edge detect)
FAT_LBA		equ	#C097			; 4 bytes: FAT table start LBA
CHAIN_CNT	equ	#C09D			; 2 bytes: file cluster-chain length
BOOT_SP		equ	#C0B0			; 2 bytes: saved BIOS cartridge-INIT SP (page-3, stable)
MQ_OFF		equ	#C0B2			; 1 byte: marquee scroll offset of the selected name
MQ_SEL		equ	#C0B3			; 1 byte: entry index currently being marquee-scrolled
MQ_TICK		equ	#C0B4			; 1 byte: marquee frame counter
BROWSING	equ	#C0B5			; 1 byte: 1 while inside the SD browser (gate marquee)
MAP_SCC		equ	#C0B6			; 2 bytes: Konami-SCC bank-write count
MAP_KON		equ	#C0B8			; 2 bytes: Konami bank-write count
MAP_A8		equ	#C0BA			; 2 bytes: ASCII8 bank-write count
MAP_A16		equ	#C0BC			; 2 bytes: ASCII16 bank-write count
SSEC_LEFT	equ	#C0C0			; 1 byte: sectors left in current cluster (scan)
SCAN_N		equ	#C0C1			; 2 bytes: sectors scanned so far
MAPPER_ID	equ	#C0C3			; 1 byte: detected mapper id
MEG_T0		equ	#C0C4			; 1 byte: megaram write-test readback byte 0
MEG_T1		equ	#C0C5			; 1 byte: megaram write-test readback byte 1
MEG_P42		equ	#C0C6			; 1 byte: SWIO port 0x42 readback (Slot2Mode in bits 4,5)
MEG_B0		equ	#C0C7			; 1 byte: megaram byte 0 BEFORE the write
LOAD_SEG	equ	#C0C8			; 1 byte: current 8K megaram segment being loaded
LOAD_OFF	equ	#C0C9			; 2 bytes: byte offset within the current 8K segment
MEG_RB		equ	#C0CD			; 8 bytes: megaram readback scratch (load verify)
SRCH_BUF	equ	#E880			; 13 bytes: consulta de busqueda del navegador (ASCIIZ)
SRAM_FLAG	equ	#C0D9			; 1 byte: SRAM de cartucho para este lanzamiento (0/1)
P2_SLOT		equ	#C0DA			; 1 byte: slot de la pag.2 al llamar al INIT (v2.0.1
									; caso Aleste2: la BIOS real deja RAM en 0x8000;
									; #02=megaram solo para ROMs lineales MAP_PLAIN)
SD_READY	equ	#C0DB			; 1 byte: SD ya montada+escaneada (bajo el logo)
MAP_SWIO	equ	#C0DC			; 1 byte: smart command del mapper (lo aplica el stub)
DSK_PEND	equ	#C0DD			; 1 byte: registro .dsk pendiente de reescribir (2o pase)
TW_LOAD		equ	#C0DE			; 1 byte: loadcmd de la cinta web (0=RUN 1=BLOAD 2=?)
NEEDLE		equ	#C0D5			; 2 bytes: substring search needle pointer (tag scan)
TAGPTR		equ	#C0D7			; 2 bytes: haystack (filename) pointer (tag scan)
PE_PTR		equ	#C0D9			; 2 bytes: MBR partition-entry pointer (dump diag)
PE_ROW		equ	#C0DB			; 1 byte: partition dump display row
PE_DW		equ	#C0DC			; 4 bytes: 32-bit value scratch for hex print
DSK_LBA		equ	#C0E0			; 4 bytes: abs LBA of the selected .dsk first sector
DSK_SECS	equ	#C0E4			; 2 bytes: .dsk size in 512-byte sectors
EMU_LBA		equ	#C0E6			; 4 bytes: abs LBA of the NEXTOR.EMU data file sector
FAT_SZ		equ	#C0EA			; 2 bytes: sectors per FAT (FATSz16 o FATSz32 low16)
NUM_FATS	equ	#C0EC			; 1 byte: number of FAT copies
NEW_CLUS	equ	#C0ED			; 2 bytes: cluster allocated for a new NEXTOR.EMU (FAT16 path)
; --- FAT32: clusters anchos (4 bytes LE) en pagina-3 alta, zona libre #E840+ ---
CUR_CLUS	equ	#E840			; 4 bytes: current directory cluster (FAT16: 0 = root)
SCAN_CLUS	equ	#E844			; 4 bytes: cluster being scanned (dir chain walk)
FILE_CLUS	equ	#E848			; 4 bytes: selected file's first cluster
LOAD_CLUS	equ	#E84C			; 4 bytes: cluster being loaded (ROM chain walk)
W_TMP		equ	#E850			; 4 bytes: wide-cluster scratch (fatnext/clus2lba)
W_SAVE		equ	#E854			; 4 bytes: CUR_CLUS save/restore (scan_rom/load_rom)
FS32		equ	#E858			; 1 byte: 0 = FAT16, 1 = FAT32 (per selected partition)
SPC_SHIFT	equ	#E859			; 1 byte: log2(SEC_PER_CLUS)
ROOT_CLUS	equ	#E85C			; 4 bytes: FAT32 root directory first cluster
DIR_STACK	equ	#E860			; 8 x 4 bytes: parent-cluster back stack (#E860..#E87F)
FFC_BASE	equ	#C0EF			; 2 bytes: base cluster of the FAT sector being scanned
FFC_LEFT	equ	#C0F1			; 2 bytes: FAT sectors left to scan
MCE_OFF		equ	#C0F3			; 2 bytes: byte offset of the FAT entry within its sector
WDE_LEFT	equ	#C0F5			; 1 byte: root-dir sectors left to scan
MCE_SEC		equ	#C0F6			; 1 byte: FAT sector offset of the cluster entry
BR_BLINK	equ	#C0F7			; 1 byte: per-row blink-attr fill byte (dir colour)
FILTER		equ	#C0F8			; 1 byte: active tab filter (0=ROM, 1=DSK, 2=ALL)
FH_DFERR	equ	#C0F9			; 1 byte: fh2_dfind no pudo LEER (su CF=1 no es fiable)
BOOT_KEY	equ	#C0FA			; 1 byte: tecla cazada durante el logo (0 nada, 1 S, 2 W)
; --- multi-partition support (placed at #E800, above ENT_ARRAY C300..E700) ---
MAX_PARTS	equ	8
PART_TBL	equ	#E800			; up to 8 entries x 4 bytes = start LBA of each FAT16 partition
PART_CNT	equ	#E820			; 1 byte: number of partitions found
EXT_BASE	equ	#E821			; 4 bytes: extended-partition base LBA (0 = none)
CUR_PART	equ	#E825			; 1 byte: currently-selected partition index
EBR_CUR		equ	#E826			; 4 bytes: current EBR LBA while walking the chain
ADD_TMP		equ	#E82A			; 4 bytes: 32-bit add scratch
BOOT_RET	equ	#E82E			; 2 bytes: saved BIOS boot return address (survives WiFi ROM)
BOOT_FLAG	equ	#E830			; 1 byte: 0x99 = boot pending (skip menu on BIOS 2nd INIT pass)
CLK_STR		equ	#E831			; 9 bytes: "HH:MM:SS" + 0 (header clock)
CLK_LAST	equ	#E83A			; 1 byte: last seconds-units digit (clock change detect)
JOY_RPT		equ	#E83B			; 1 byte: joystick auto-repeat frame counter
BAR_FRAC	equ	#E83C			; 2 bytes: acumulador Bresenham de la barra de carga
BAR_TOT		equ	#E83E			; 2 bytes: total de segmentos 8K de la ROM (escala barra)
BAR_CNT		equ	#E85A			; 1 byte: celdas pintadas de la barra (tope fisico 64)
JOY_RPT_DELAY equ 14			; frames before a held stick starts repeating
JOY_RPT_RATE  equ 2				; frames between repeats (lower = faster)
RAM_SLOT_30	equ	#83				; ENASLT id: expandido, primario 3, secundario 0 (RAM mapeada)
MEG_SLOT	equ	#02				; primary slot 2 (the OCM relocates the megaram here
								; when Slot2Mode is set via the SWIO smart command)
; mapper ids
MAP_PLAIN	equ	0
MAP_KON_ID	equ	2
MAP_SCC_ID	equ	3
MAP_A8_ID	equ	4
MAP_A16_ID	equ	5
MAP_UNK		equ	6
MAP_THRESH	equ	2				; min bank-writes to accept a mapper signature
SD_BUF		equ	#C100			; 512 bytes: sector transfer buffer
SD_SLOT_32	equ	#8B			; ENASLT slot id: expanded, primary 3, secondary 2 (SD)
SD_SLOT_31	equ	#87			; ENASLT slot id: expanded, primary 3, secondary 1 (menu)
SDC_SDATA	equ	#7C00			; 512-byte sector transfer window
SDC_ENABLE	equ	#7E00			; wo: bit0 = enable SDC register block
SDC_CMD		equ	#7E01			; wo: bit0=read
SDC_STATUS	equ	#7E02			; ro: bit7=busy bit1=timeout bit0=bloque RECHAZADO
SDC_SADDR	equ	#7E03			; wo: 4 bytes = LBA
SDC_CTYPE	equ	#7E0C			; ro: card type

main_action_sdrom:
	ld   a, (SD_READY)
	or   a
	jp   nz, browse					; montada bajo el logo -> navegador directo
	call cls_browser				; show feedback (the SD init can pause a moment)
	ld   hl, #0103
	call POSIT
	ld   hl, readingStr				; "Leyendo SD..."
	call print_string
	; --- read sector 0 (MBR with partition table) ---
	xor  a
	ld   (SD_LBA+0), a
	ld   (SD_LBA+1), a
	ld   (SD_LBA+2), a
	ld   (SD_LBA+3), a
	call sd_read_sector
	; --- SD-present check: if the init/read timed out (no card, or not the SD
	;     window) bail out cleanly instead of parsing garbage and hanging ---
	ld   a, (SD_STATUS)
	or   a
	jp   nz, sd_not_present
	ld   a, (SD_BUF+510)			; MBR boot signature must be 0x55 0xAA
	cp   #55
	jp   nz, sd_not_present
	ld   a, (SD_BUF+511)
	cp   #AA
	jp   nz, sd_not_present
	; --- enumerate ALL FAT16 partitions (4 primaries + extended-chain logicals) ---
	call enum_partitions
	ld   a, (PART_CNT)
	or   a
	jp   z, sd_not_present			; no readable FAT16 partition
	xor  a
	call select_partition			; open partition 0 (reads BPB, computes root, scans;
	jp   c, sd_not_present			; sets BR_SEL/BR_TOP/MQ_SEL/BROWSING)
	ld   a, 1
	ld   (SD_READY), a				; las vueltas desde ajustes ya no re-montan
	jp   browse						; scrolling browser (returns to menu on ESC)

; sd_not_present: no usable SD card (init/read timeout or bad MBR signature).
; In the unified UI the browser is the home screen, so DON'T loop back to it
; (that would re-read the SD and bounce here forever). Offer the global actions.
sd_not_present:
	call cls_browser
	ld   hl, #0103
	call POSIT
	ld   hl, noSdStr
	call print_string
	ld   hl, #0105
	call POSIT
	ld   hl, noSdStr2
	call print_string
.snp_key:
	call browse_getkey
	cp   #0D						; RETURN -> arrancar sistema
	jp   z, boot_system
	cp   #1B						; ESC -> arrancar sistema
	jp   z, boot_system
	cp   #53						; 'S' -> Settings (Ajustes)
	jp   z, config_menu_entry
	cp   #73						; 's'
	jp   z, config_menu_entry
	cp   #57						; 'W' -> WiFi config
	jp   z, main_action_wifi
	cp   #77						; 'w'
	jp   z, main_action_wifi
	cp   #54						; 'T' -> Cinta web (TSX streaming)
	jp   z, main_action_tsxweb
	cp   #74						; 't'
	jp   z, main_action_tsxweb
	cp   #46						; 'F' -> File-Hunter (buscar y listar online)
	jp   z, fh_browse
	cp   #66						; 'f'
	jp   z, fh_browse
	jr   .snp_key

; =====================================================================
; Multi-partition support
; =====================================================================
; is_fat16: A = MBR/EBR partition type byte. CF=1 if it is a FAT12/16/32 type
; we can browse (0x01/0x04/0x06/0x0E FAT16, 0x0B/0x0C FAT32). CF=0 otherwise.
is_fat16:
	cp   #01
	jr   z, .if_yes
	cp   #04
	jr   z, .if_yes
	cp   #06
	jr   z, .if_yes
	cp   #0E
	jr   z, .if_yes
	cp   #0B						; FAT32 CHS
	jr   z, .if_yes
	cp   #0C						; FAT32 LBA
	jr   z, .if_yes
	or   a							; CF = 0
	ret
.if_yes:
	scf
	ret

; add_partition_at: HL = ptr to a 4-byte start LBA. Append it to PART_TBL if room.
add_partition_at:
	ld   a, (PART_CNT)
	cp   MAX_PARTS
	ret  nc							; table full -> ignore
	push hl							; src
	ld   l, a						; dest = PART_TBL + cnt*4
	ld   h, 0
	add  hl, hl						; *2
	add  hl, hl						; *4
	ld   de, PART_TBL
	add  hl, de
	ex   de, hl						; DE = dest
	pop  hl							; HL = src
	ld   bc, 4
	ldir
	ld   a, (PART_CNT)
	inc  a
	ld   (PART_CNT), a
	ret

; set_add_tmp: HL = ptr to 4-byte value -> ADD_TMP = value.
set_add_tmp:
	ld   de, ADD_TMP
	ld   bc, 4
	ldir
	ret
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

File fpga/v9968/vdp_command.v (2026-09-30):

//
//	vdp_command.v
//
//	Copyright (C) 2025 Takayuki Hara
//
//	本ソフトウェアおよび本ソフトウェアに基づいて作成された派生物は、以下の条件を
//	満たす場合に限り、再頒布および使用が許可されます。
//
//	1.ソースコード形式で再頒布する場合、上記の著作権表示、本条件一覧、および下記
//	  免責条項をそのままの形で保持すること。
//	2.バイナリ形式で再頒布する場合、頒布物に付属のドキュメント等の資料に、上記の
//	  著作権表示、本条件一覧、および下記免責条項を含めること。
//	3.書面による事前の許可なしに、本ソフトウェアを販売、および商業的な製品や活動
//	  に使用しないこと。
//
//	本ソフトウェアは、著作権者によって「現状のまま」提供されています。著作権者は、
//	特定目的への適合性の保証、商品性の保証、またそれに限定されない、いかなる明示
//	的もしくは暗黙な保証責任も負いません。著作権者は、事由のいかんを問わず、損害
//	発生の原因いかんを問わず、かつ責任の根拠が契約であるか厳格責任であるか（過失
//	その他の）不法行為であるかを問わず、仮にそのような損害が発生する可能性を知ら
//	されていたとしても、本ソフトウェアの使用によって発生した（代替品または代用サ
//	ービスの調達、使用の喪失、データの喪失、利益の喪失、業務の中断も含め、またそ
//	れに限定されない）直接損害、間接損害、偶発的な損害、特別損害、懲罰的損害、ま
//	たは結果損害について、一切責任を負わないものとします。
//
//	Note that above Japanese version license is the formal document.
//	The following translation is only for reference.
//
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
//	1. Redistributions of source code must retain the above copyright
//	   notice, this list of conditions and the following disclaimer.
//	2. Redistributions in binary form must reproduce the above
//	   copyright notice, this list of conditions and the following
//	   disclaimer in the documentation and/or other materials
//	   provided with the distribution.
//	3. Redistributions may not be sold, nor may they be used in a
//	   commercial product or activity without specific prior written
//	   permission.
//
//	THIS SOFTWARE IS PROVIDED BY THE COPYRIGHT HOLDERS AND CONTRIBUTORS
//	"AS IS" AND ANY EXPRESS OR IMPLIED WARRANTIES, INCLUDING, BUT NOT
//	LIMITED TO, THE IMPLIED WARRANTIES OF MERCHANTABILITY AND FITNESS
//	FOR A PARTICULAR PURPOSE ARE DISCLAIMED. IN NO EVENT SHALL THE
//	COPYRIGHT OWNER OR CONTRIBUTORS BE LIABLE FOR ANY DIRECT, INDIRECT,
//	INCIDENTAL, SPECIAL, EXEMPLARY, OR CONSEQUENTIAL DAMAGES (INCLUDING,
//	BUT NOT LIMITED TO, PROCUREMENT OF SUBSTITUTE GOODS OR SERVICES;
//	LOSS OF USE, DATA, OR PROFITS; OR BUSINESS INTERRUPTION) HOWEVER
//	CAUSED AND ON ANY THEORY OF LIABILITY, WHETHER IN CONTRACT, STRICT
//	LIABILITY, OR TORT (INCLUDING NEGLIGENCE OR OTHERWISE) ARISING IN
//	ANY WAY OUT OF THE USE OF THIS SOFTWARE, EVEN IF ADVISED OF THE
//	POSSIBILITY OF SUCH DAMAGE.
//
//-----------------------------------------------------------------------------

module vdp_command (
	input				reset_n,
	input				clk,
	//	VRAM interface
	output		[17:0]	command_vram_address,
	output				command_vram_valid,
	input				command_vram_ready,
	output				command_vram_write,
	output		[31:0]	command_vram_wdata,
	output		[3:0]	command_vram_wdata_mask,
	input		[31:0]	command_vram_rdata,
	input				command_vram_rdata_en,
	//	CPU interface
	input				register_write,
	input		[5:0]	register_num,
	input		[7:0]	register_data,
	input				clear_border_detect,
	input				read_color,
	output				status_command_execute,			//	S#2 bit0
	output				status_border_detect,			//	S#2 bit4
	output				status_transfer_ready,			//	S#2 bit7
	output		[7:0]	status_color,					//	S#7
	output		[8:0]	status_border_position,			//	S#8, S#9
	//	Screen mode
	input		[9:0]	screen_mode,
	input				vram_interleave,
	input		[7:0]	reg_text_back_color,
	input				reg_command_enable,
	input				reg_command_high_speed_mode,
	input				reg_ext_command_mode,
	input				reg_vram256k_mode,
	output				vram_access_mask,
	output				intr_command_end
);
	localparam	c_hmmc		= 4'b1111;
	localparam	c_ymmm		= 4'b1110;
	localparam	c_hmmm		= 4'b1101;
	localparam	c_hmmv		= 4'b1100;
	localparam	c_lmmc		= 4'b1011;
	localparam	c_lmcm		= 4'b1010;
	localparam	c_lmmm		= 4'b1001;
	localparam	c_lmmv		= 4'b1000;
	localparam	c_line		= 4'b0111;
	localparam	c_srch		= 4'b0110;
	localparam	c_pset		= 4'b0101;
	localparam	c_point		= 4'b0100;
	localparam	c_lrmm		= 4'b0011;
	localparam	c_lfmc		= 4'b0010;
	localparam	c_lfmm		= 4'b0001;
	localparam	c_stop		= 4'b0000;

	localparam	c_wait_hmmc	= 6'd40;
	localparam	c_wait_ymmm	= 6'd40;
	localparam	c_wait_hmmm	= 6'd40;
	localparam	c_wait_hmmv	= 6'd40;
	localparam	c_wait_lmmc	= 6'd40;
	localparam	c_wait_lmcm	= 6'd40;
	localparam	c_wait_lmmm	= 6'd40;
	localparam	c_wait_lmmv	= 6'd40;
	localparam	c_wait_line	= 6'd40;
	localparam	c_wait_srch	= 6'd40;
	localparam	c_wait_pset	= 6'd40;
	localparam	c_wait_point= 6'd40;

	localparam	c_imp		= 4'b0000;
	localparam	c_and		= 4'b0001;
	localparam	c_or		= 4'b0010;
	localparam	c_eor		= 4'b0011;
	localparam	c_not		= 4'b0100;
	localparam	c_rsv1		= 4'b0101;
	localparam	c_rsv2		= 4'b0110;
	localparam	c_rsv3		= 4'b0111;
	localparam	c_timp		= 4'b1000;
	localparam	c_tand		= 4'b1001;
	localparam	c_tor		= 4'b1010;
	localparam	c_teor		= 4'b1011;
	localparam	c_tnot		= 4'b1100;
	localparam	c_trsv1		= 4'b1101;
	localparam	c_trsv2		= 4'b1110;
	localparam	c_trsv3		= 4'b1111;

	//	screen_mode code
	localparam	c_g1		= 0;			//	Graphic1 (SCREEN1) w_mode index
	localparam	c_g2		= 1;			//	Graphic2 (SCREEN2) w_mode index
	localparam	c_g3		= 2;			//	Graphic3 (SCREEN4) w_mode index
	localparam	c_g4		= 3;			//	Graphic4 (SCREEN5) w_mode index
	localparam	c_g5		= 4;			//	Graphic5 (SCREEN6) w_mode index
	localparam	c_g6		= 5;			//	Graphic6 (SCREEN7) w_mode index
	localparam	c_g7		= 6;			//	Graphic7 (SCREEN8) w_mode index
	localparam	c_t1		= 7;			//	Text1    (SCREEN0:WIDTH40) w_mode index
	localparam	c_t2		= 8;			//	Text2    (SCREEN0:WIDTH80) w_mode index
	localparam	c_gm		= 9;			//	Mosaic   (SCREEN3) w_mode index

	localparam	c_bpp_2bit	= 0;
	localparam	c_bpp_4bit	= 1;
	localparam	c_bpp_8bit	= 2;

	reg					ff_command_execute;
	reg			[7:0]	ff_read_pixel;
	reg			[7:0]	ff_status_color;
	reg			[7:0]	ff_read_byte;
	reg			[7:0]	ff_source;
	wire		[7:0]	w_destination;
	wire		[7:0]	w_lop_pixel;
	//	_125b (MSXimus): maxfan ADEMAS de los clones de HRA — la familia
	//	ff_screen_mode -> next_state/cache_vram_address fue la ultima migaja
	//	de la campana de timing.
	reg			[9:0]	ff_screen_mode;				/* synthesis syn_preserve = 1 syn_maxfan = 8 */
	reg			[9:0]	ff_screen_mode_clone;		/* synthesis syn_preserve = 1 syn_maxfan = 8 */
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

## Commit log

2026-09-07 Base: MSX_up_v3 rama V3.5 en dd8d8ff + cambios pendientes de la v3.5d (SD por puertos, cronometro, menu de pruebas)
    Punto de partida del porte a la Tang Console 138K (GW5AST-138). Copia de los
    ficheros seguidos y de los nuevos sin commitear del MSX_up_v3 a fecha
    07/09/2026, sin entregas (files/) ni salidas de build.
2026-09-07 Porte a la Tang Console 138K (GW5AST-138B): device, constraints 1:1 y mapa de flash +4 MB
    - build.tcl: set_device GW5AST-138B GW5AST-LV138PG484AC1/I0; constraints
    msx_console138k.cst/.sdc (copia 1:1 de los del 60K: el SOM Mega 138K lleva
    las mismas bolas que el Mega 60K para el dock y para la DDR3, verificado
    contra los cst de nand2mario para la Console 138K).
    - La IP de DDR3 (Gowin v3.0, generada para gw5at60b) se reutiliza: es
    portable dentro de Arora V (nand2mario usa una de gw5a25b en el 60K y en el
    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
2026-09-07 README.138: que cambia respecto al 60K, version B/C del chip, mapa de flash
2026-09-07 138K: PLLA -> PLL + PLL_INIT (pll138/), pll_stop directo a ENCLK2, IO_TYPE SSTL15 en la DDR3
    - El GW5AST-138 no tiene el primitivo PLLA (ERROR RP0008): usa PLL, con los
    mismos divisores pero sin mDRP. pll138/gen: gowin_pll, pll_27, pll_74,
    pll_86, pll_12 y pll_ddr3 = <n>_MOD (PLL, ICP/LPF dinamicos) + PLL_INIT del
    gw5ast138b (pll138/pll_init.v, de nand2mario/ddr3_framebuffer_gowin, Apache-2.0).
    Los divisores se leyeron de los ficheros del 60K con gen_pll138.py.
    - Clientes DDR3 (v9968_ddr3_backend, wave_ddr3): fuera la danza mDRP; el
    pll_stop de la IP va directo a ENCLK2, como en la Console 138K de nand2mario.
    - top.v: init_clk (50 MHz del pad) en los PLL estaticos.
    - sdc/build.tcl: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
2026-09-07 138K cst: fuera las INS_LOC del 60K (PLL/DLL de la DDR3), s1/s2/fan_en_o a LVCMOS33
    En el GW5AST-138 el banco 5 (AB13/AA13/AB12) queda fijado a 3,3 V por la flash
    de configuracion (MSPI como GPIO): los botones y el ventilador, que en el 60K
    iban a 1,5 V en el banco de la DDR3, pasan a 3,3 V. Las INS_LOC de sitio
    (DDRDLLM_BL, PLL_L[0]) eran del mapa del 60K; se quitan para el arranque del porte.
2026-09-07 138K: VCO de los PLL dentro del rango 650-1300 MHz; motor OPL4 a 36 MHz
    El PLL del GW5AST-138 avisa (PA1019) con VCO 1350 (pll_main, pll_27) y 1485
    (pll_74). Divisores nuevos, todos enteros y exactos:
    - pll_main: 50/5 x2 x54 = VCO 1080 -> 108, 54, 27, 135 y 36 (ODIV 10/20/40/8/30).
    El 37,5 del motor OPL4 no sale de 1080; pasa a 36 MHz en el MISMO VCO y fase
    (el sdc lo tiene en el mismo grupo que 27/54/108). opl4_pcm.v: CE de 44,1 kHz
    = 14112/15000 (trama de 768 clk a 46875 Hz), baudios/frame del debug a 36 MHz.
    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
2026-09-07 138K: cascada de PLL (PFD 19-81,25 MHz obliga)
    Desde el pad de 50 no salen 108/54/27 ni 371,25 exactos con PFD >= 19 y VCO <= 1300.
    - pll_27: 50/2 x27 = VCO 675 -> 27,000 exactos (PFD 25).
    - pll_main: referencia clk27_video, x40 = VCO 1080 -> 108/54/27/135 y 36 (motor
    OPL4), todo entero. Reset por ~pll27_lock (PLL_INIT en reset hasta el 27).
    - pll_ddr3 (VCO 891) presta CLKOUT1 = 891/12 = 74,25, sin gatear por pll_stop;
    el backend lo exporta (clk_7425_out).
    - pll_74: referencia 74,25, x10 = VCO 742,5 -> 74,25 y 371,25 (= pll_hdmi de
    nand2mario para la Console 138K).
    [v9968_ddr3_backend.v]
2026-09-07 138K: la salida del OPLL se registra en clk_27m antes del mezclador
    En el 138 el camino opll/u_acc (clk_54m) -> snd_mix (clk_27m) da 22 ns (13
    niveles del arbol de sumas + rutado) contra los 18,5 de la relacion 54->27:
    -4,3 ns en dos dados (p138f). Con el registro, el cruce queda FF->FF sin logica
    y el arbol dispone del ciclo entero de 27. +37 ns de latencia: inaudible.
2026-09-07 138K v1: entrega (dado 3361, respaldo 3359), LEEME, y clk_86 sobre-restringido a 11,30 ns para buscar margen
    p138g: los tres dados pasan el gate con el OPLL registrado; peor camino el
    shim de VRAM/V9968 con 0,013-0,029 ns. Se entrega el 3361. La campana p138h
    compila con clk_86 a 11,30 ns (real 11,64) para que el rutador deje >= 0,34
    ns de margen real en ese dominio.
2026-09-07 Limpieza: fuera 19 ficheros vacios que dejaron redirecciones fallidas de la shell (no eran del proyecto)
2026-09-09 138K v2: el Game Master 2 del slot 1 (bloque 6), identico al de la v3.5f del 60K (gm2_slot1.v, #46 bit6/bit7, segmentos 480-497 de la megaram). Campana p138i: dado 3469 gate OK (~0,35 ns real), entre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
2026-09-18 138K v3.7: la documentacion del 60K adaptada al porte (manual, tecnica, indice, README.138)
    Los 10 capitulos del manual, los 9 de la tecnica, el INDICE y el README.138 hablan ya del
    MSXimus_138: SOM Mega 138K (GW5AST-138B/C, Standard con licencia), mapa de flash del 138
    (bitstream 4,88 MB, pack 0x800000, config de 11 bytes en 0x880000, YRW801 0x900000),
    cascada PLL + PLL_INIT (36 MHz del motor OPL4, pll_stop -> ENCLK2, OPLL registrado),
    clk_86 a 11,30 ns, campanas p138a..p138j, changelog con la linea 138K (v1 07/09, v2 08/09,
    v3.7 18/09) delante del historial del 60K. Lo medido en placa se atribuye al 60K y el
    porte queda marcado como NUNCA PROBADO EN PLACA donde toca (instalacion, problemas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
2026-09-24 Porte de la Zynq: ASCII16-X + megaram de 8 MB, Plain 0000h y ajustes #41/#42
    Los mismos cambios que MSX_up_v3 port-zynq-2409 (ad37e24): la 138K es la misma
    placa base y el mismo modulo SDRAM, y estos ficheros eran identicos a los del
    60K. megaram.v/sd_dma.sv/sdc_ioport.sv de la Zynq, memory.v con el bit 23 a la
    fila 11 (4 MB altos de la megaram), top.v con ram_addr de 24 bits, #46 que
    conserva los bits 0-2 en el reset y un config_update por registro (#41/#42).
    tools/sdr16_tb con la T11. Sin sintetizar aun. Menu: bios-msxnano-msximus
    port-a16x-2409 (los packs son los del 60K).
    [megaram.v, memory.v]
2026-09-25 Shim V9968: las rayas de arranque (write-allocate CPU, miss repetido, sin respuestas tardias al fondo)
    Porte del arreglo de la Zynq (25/09): _187 las escrituras de la CPU sin tag-match
    encolan una relectura que deja la palabra residente en la sc-cache (solo clase CPU,
    solo region identidad < 0x8000); _188 un miss repetido de la misma palabra siembra
    +0 por pfq en vez de volver a sembrar +1/OBL (la lectura de demanda no se lanzaba en
    toda la linea); _189 las respuestas tardias solo van a CPU y comando. Bancos
    tb_t2drop/tb_t2vpoke y flujo Verilator (tareas de bus con asignaciones bloqueantes).
    Sin sintetizar en el 138K (sin placa).
    [v9968_vram_shim.v]
2026-09-27 V3.7.1 (solo arreglos, sin build: sin placa ni margen): los mismos cuatro ficheros del V9968 que el 60K y el puerto 29h = FPGA_PATCH
    [vdp_command.v]
2026-09-27 3.7.1: sin escalones nuevos en los caminos criticos del 60K (ff_byte_mode registrado con ff_screen_mode; 2Fh y 29h en un solo termino del mux de cpu_din)
    Campana pf60a: 1/5 (4649, +0,13 ns) y los peores caminos tocaban justo el mux de cpu_din (-0,103) y ff_command->next_state
    del motor (-0,099). Funcionalmente identico: g2cmd_check 60/60 + SCREEN 2 OK, tb_spcol verde.
2026-09-28 V3.7.2 (sin build): mandos HID genericos por los USB-A (usb_pad_rid.v), como el 60K; FPGA_PATCH = 2
2026-09-28 README: el fichero de ondas del OPL4 es yrw801.bin (el Programmer de Gowin no coge .rom)
2026-09-28 V3.7.3: host USB del fabric robusto ante dispositivos que responden rapido (alineacion al fin del SYNC, timing resincronizado en start) y sin IZQUIERDA pegada tras enumerar; FPGA_PATCH = 3 (mismo arr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
2026-09-29 cpu_din: el mux de lectura de la CPU por GRUPOS en vez de una sola cadena de ternarios
    Las fuentes van en grupos que se resuelven en paralelo (acierto + valor) y
    luego los grupos entre si, en orden: la profundidad pasa de ~N niveles a
    (grupo mas largo + numero de grupos). La prioridad es exactamente la de
    antes: grupos = tramos seguidos de la lista original, orden conservado
    dentro de cada uno; solo se juntan condiciones vecinas con el mismo valor y
    se quitan slot0/slotx, que daban 8hFF = el defecto.
    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
2026-09-29 tools: cpudin_equiv/verify.py, equivalencia formal (yosys miter + SAT) y por simulacion (Icarus) del mux de cpu_din entre dos top.v
2026-09-29 usb_hid_host: un ZLP por EP1 ya no deja IZQUIERDA clavada en el mando USB-A (V3.7.5)
    Probado por Albert en el 60K (3.7.4, 29/09) con el mando conectado: en el
    menu cada seleccion >= 18 volvia 18 atras (IZQUIERDA del joystick = pagina
    anterior, auto-repetida) y parecia que la lista no hacia scroll.
    Causa: el decodificador SNES decidia el eje X con el byte 0 nada mas llegar.
    Un ZLP (DATA vacio) se estroba como UN byte 00 (el primero del CRC) -> eje X
    = 00 = IZQUIERDA, y con un mando con Report ID (0810) ningun informe la
    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
2026-09-29 Timing: las escrituras a los puertos de config (#40-#43, #45, #46) y al mapper (FC-FF) con una etapa de registro
    El cruce 54 -> 27 de 9,26 ns (IORQ_n/WR_n del T80 -> configN_req/mapper_reg_write
    -> CE de config*_ff / mapper_reg*) fue el peor camino de casi todos los dados
    rechazados de la V3.7.4/3.7.5 (pf60g/h/i/j: -0,02..-1,7 ns; 15 dados, uno solo
    con margen y ese no calibraba la DDR3). Mismo arreglo que el #44 de la V3.7
    (cfg4_req_r): peticion, direccion y dato se capturan juntos en 27 MHz y se usan
    un ciclo despues. El OUT dura ~20 ciclos de 27 MHz: no cambia nada.
    Banco tools/cfgreg_sim (Icarus, 20.000 OUT con fase aleatoria frente a
    clk_enable_3m6_27): registros iguales en todos; los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
2026-09-30 V3.7.6: tres arreglos del V9968 del upstream de HRA (29/09): latch del puerto 1 (Fleet Commander II), DIY con el origen arriba (ds4) y paso de pixel registrado; FPGA_PATCH = 6 (mismo porte que el 60K)
    [vdp_command.v, vdp_cpu_interface.v]
2026-09-30 MSX SD Maker 1.0 en MSXsdmaker/ (programa para Windows que prepara la tarjeta SD, instrucciones ES/EN, licencias, fuente), enlazado desde los README; el capitulo 03 se corrige: Nextor no monta FAT32
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2026-10-02 MXUPDATE /N: la descarga escribia restos del bufer (Net_Recv devuelve lo pedido, no lo recibido)
    TCP_RCV del ESP puede entregar menos bytes de los pedidos; la cuenta real la deja el UNAPI en incoming_bytes, pero
    Net_Recv() de network.h (la libreria UNAPI comun del entorno MSXgl) devuelve siempre maxLen. MXUPDATE escribia el
    resto del bufer con datos viejos y daba la descarga por completa antes de tiempo: en placa (02/10, 60K V3.8 contra el
    servidor del PC) la barra se quedo en el 99 % y la comprobacion del fichero lo rechazo por CRC (no se grabo nada).
    Ahora Recibe() llama a tcpip_tcp_rcv y usa la cuenta real.
    Para que el codigo siga acabando antes de 4000h (UNAPI): mensajes de error mas cor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
2026-10-05 OPL4: los registros de slot del wavetable se releen bien a la primera por 7Fh
    Arreglo traido de la Zynq y del 60K (MSXimus 69b1de8); el motor es el mismo
    fichero. Al leer por 7Fh un registro de slot, la primera lectura devolvia a
    menudo el valor del registro leido justo antes (los grupos de la BSRAM unica:
    08h-1Fh, 50h-7Fh y 98h-F7h), y en FNUM/LFO (20h-4Fh, 80h-97h) un 1 % de las
    lecturas devolvia el dato de otro slot. Visto en simulacion; las escrituras y
    el sonido no cambian.
    Causa, en el motor (YMF278B.sv): REG_Q se cargaba dos CE despues del flanco
    de RD con rt_cpu_q, que a esa hora aun guardaba la lectura anterior, y el
    remuestreo REG_RD_DELAY == 10 llegaba entre 3 y 10 CE despues del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
    [YMF278B.sv, ymf278b_gowin.v]
2026-10-05 OPL3 y OPL4: dos arreglos de MoonTANG (timer parado en el ciclo critico, done_d1 sin reset)
    Dos defectos del bloque OPL4 que MoonTANG comparte con el MSXimus,
    encontrados alli en simulacion (MoonTANG aa7e0a4); ninguno visto en placa.
    - fpga/opl3/timer.sv: un timer parado justo cuando su preescalador valia
    TICK-1 seguia desbordando en cada ciclo (tick_pulse no miraba
    start_timer) y los flags y /INT volvian tras cada ack y cada /RESET.
    Ahora el tick exige el timer en marcha y el contador vuelve a 0 mientras
    esta parado; los periodos no cambian. Queda igual que en MoonTANG.
    - fpga/src/opl4_pcm.v: done_d1 sigue al toggle de la memoria sin reset y
    un "hecho" solo cuenta con port_busy.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
2026-10-05 tb_timer: la prueba de vibrato y tremolo del FM mide bien (el core sigue fuera de canon)
    La prueba 4 de build_timer.sh no media el core:
    - (int16_t)sample_l se quedaba con los 16 bits bajos de una muestra de
    24 (16 << 5): la onda salia plegada, de ahi los 4,6 kHz y +/-1244 c.
    - analizaba vbuf despues de rellenarlo con el tremolo.
    - suponia fs = 44100; el core da 27 MHz/545 = 49541 Hz (medido en el
    banco: 545 ciclos por muestra).
    - la frecuencia ciclo a ciclo esta muestreada a f0 y no ve un LFO cerca
    de f0/2.
    - op2 con 23h=41h (sin EGT) caia en release: la pasada ON sonaba con un
    operador menos que el control.
    Ahora: muestra nativa (s24>>5), un bufer por pasada, fs medida,
    demodulaci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
2026-10-13 OPL4 en canon: F8 = 1Bh tras el reset y vibrato/tremolo del FM como el YMF262 (3.8.2)
    Traido de la Zynq (6bce008 y 6795e16, su Z1.2.5) a la rama opl4-canon, desde
    V3.8. Antes de copiar se comprobo que los ficheros del 138K eran identicos a
    los de la Zynq previos a esos commits (salvo ymf278b_gowin.v, que solo
    difiere en la cabecera BSD-3 de 15 lineas, y opl4_pcm.v, que no tenia el
    initial de mix_fm y lleva el CE y la telemetria de 36 MHz).
    - F8 = 1Bh tras el reset (YMF278B.sv, ymf278b_gowin.v, opl4_pcm.v): el chip
    real y openMSX arrancan con el FM a -9 dB por lado; aqui arrancaba en 00h
    porque RST_N e IC_N van a la misma senal y la rama asincrona ponia MIXFM a
    0. ymf278b_gowin.v regen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
2026-10-13 V3.8.2: NEW2 del OPL4 tambien por C5h, cabecera BSD-3 del motor y UPSTREAM; la 3.8.2 lista para la campana
    Traido de la Zynq (su Z1.2.6, 0b35da6, y la cabecera BSD-3 de fbd69b8) a la
    V3.8, que ya lleva el F8 = 1Bh y el LFO canon (rama opl4-canon, fusionada por
    fast-forward y borrada).
    - NEW2 con el dato por C5h (YMF278B.sv, ymf278b_gowin.v, comentario de
    opl4_pcm.v): los discos del "MoonBlaster Wave BASIC driver" (WAVEDRVR.BIN de
    Moonsoft) activan el OPL4 con OUT C6h,05h + OUT C5h,03h; el motor solo
    aceptaba el dato por C7h y borraba el latch con cualquier escritura, NEW2 se
    quedaba a 0 y todo 7Eh/7Fh se ignoraba sin error. Ahora 3'h0 borra el latch,
    3'h1 y 3'h3 aceptan el dato y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
2026-10-15 V3.8.4: DAMP y pseudo-reverb, el ruido de "Dutch Moonsound Veterans" y el resto del motor wave de la Zynq Z1.2.8/Z1.2.9 (sin build)
    El mismo porte que el 60K (V3.8.4) y la Zynq (rama zynq, b7b2ccb; Z1.2.8 y Z1.2.9, validadas en placa el 15/10): YMF278B.sv,
    YMF278B_pkg.sv y ymf278b_gowin.v regenerado con convert.sh (identico al del 60K), opl4fm.v con el latch de direccion FM unico,
    FPGA_PATCH = 4. DAMP y PRVB como el chip, LevelAddTLALFO saturada (el ruido de 2,7 s al cargar canciones en "Dutch Moonsound
    Veterans HDD", que afectaba a la 3.8.2 y la 3.8.3), salida a 0 en el modo de acceso a memoria, puertos de lectura de FNUM/LFO
    solo con su SEL, reset del LFO en su slot, DL a 3 dB por paso, NE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
2026-10-18 geo3d en la 138K: coprocesador 3D de Alex Moncks en 9Dh/9Fh, motor en clk_86 con CE 1/2
    - fpga/geo3d: geo3d v1.0.0 (MIT) con la variante `ifdef GEO3D_CE (sin el
    define, byte a byte el RTL de Alex). El motor va a clk_86 con un clock
    enable a 1/2 propio y replicado (no quedan PRIMARY ni LW para un clk_43).
    geo3d_ce.v lo compila con el define; geo3d_ce_audit.py comprueba sobre el
    netlist que el CE llega a cada FF/BSRAM/DSP del motor y emite set_max_delay
    para los que lo llevan solo en el D.
    - vdp.v: el gancho ext_cmd_* de HRA/Alex (igual que la Zynq).
    - top.v: 9Dh/9Fh, u_geo3d, generador de CE y reset local bajo ENABLE_GEO3D;
    sin el define el netlist es el de la V3.8 (comparado).
    -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
2026-11-03 138K v3.8.4b: el HDMI con su propio PLL (sin probar en placa)
    Con la v3.8.4 una 138K daba MSX vivo pero sin senal HDMI. pll_74 tomaba su
    referencia de 74,25 MHz del CLKOUT1 de pll_ddr3, y los reintentos de la DDR3
    (wd_pll_rst, desde el intento 17) reinician ese PLL y le quitan el reloj al
    HDMI. Hipotesis por lectura del codigo y por banco con un PLL simulado; no
    hay medida en placa.
    - fpga/pll138/pll_hdmiref.v: PLL propio del HDMI (27 x33 /12 = 74,25 MHz).
    - Cada PLL que cuelga de otro espera al lock de su referencia (el PLL_INIT
    calibra ICP/LPF una sola vez, ~16 ms): pll_hdmiref y pll_86 al de pll_27,
    pll_74 al de pll_hdmiref. pll_74 y pll_86 ganan el puerto reset; pll_74,
    ademas, lo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
2026-11-03 138K geo3d-v2: docs de la entrega v3.8.4b + geo3d v2.0 (dado 5867)
    README.138.md: cifras de la entrega de prueba (dado 5867, campana g3v2d,
    1 de 21 dados con geo3d pasa el gate, +0,004 ns, CLS 66 %).
    09-changelog.md: entrada "v3.8.4b + geo3d v2.0" con la procedencia (HRA!
    3d55af4), el reloj a 1/2 (GEO3D_CE), el HMMV rapido, el arreglo del camino
    CPU -> SD (bus_addr_sd) y los bancos de WSL.
    07-sintesis-campanas.md: la direccion del T80 sale de una BSRAM; mirar el
    desglose del camino antes de elegir que registrar.
    Sin probar en placa; la SD es lo primero a comprobar.
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2026-11-08 docs: MXUPDATE 1.4 baja las ondas del OPL4; la YRW801 ya no va en la release
    README, manual 02 (instalacion), 08 (audio), 10 (problemas) y 11 (actualizar), y
    tecnica 11: MXUPDATE /O, la pregunta tras /N, la linea ondas= del manifiesto y
    OndasVacias. La tabla de la flash dice que la YRW801 no es necesaria y que la
    baja MXUPDATE; la release ya no la lista.
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

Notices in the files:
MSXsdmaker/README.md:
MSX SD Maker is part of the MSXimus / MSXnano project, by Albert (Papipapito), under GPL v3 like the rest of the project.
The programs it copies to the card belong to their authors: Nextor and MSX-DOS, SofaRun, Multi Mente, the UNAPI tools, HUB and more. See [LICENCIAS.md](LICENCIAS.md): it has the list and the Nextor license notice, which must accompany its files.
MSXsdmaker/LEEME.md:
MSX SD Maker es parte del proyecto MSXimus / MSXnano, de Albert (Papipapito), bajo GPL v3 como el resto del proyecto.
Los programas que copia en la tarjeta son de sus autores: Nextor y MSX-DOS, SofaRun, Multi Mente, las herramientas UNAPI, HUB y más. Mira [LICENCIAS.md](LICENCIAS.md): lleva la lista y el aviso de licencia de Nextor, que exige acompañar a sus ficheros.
